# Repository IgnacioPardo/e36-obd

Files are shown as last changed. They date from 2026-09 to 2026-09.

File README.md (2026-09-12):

<div align="center">

# E36 OBD

**Read a pre-OBD2 BMW's brain — from a Mac, an iPhone, an Apple Watch, or a board you build yourself.**

A 1994 BMW E36 316i (M43B16, Bosch Motronic 1.7.2) predates OBD2. It speaks **KWP71** over a single-wire **K‑line**, woken with a 5‑baud slow init. A generic OBD2 scan tool can't talk to it at all — not "fewer PIDs", it will *never* establish a session. The usual answer is a Windows laptop running INPA. This isn't that: it's a Mac client, a native iOS/watchOS app, ESP32 firmware, and two open hardware builds — all offline, no Windows, no VM, no third‑party dependencies.







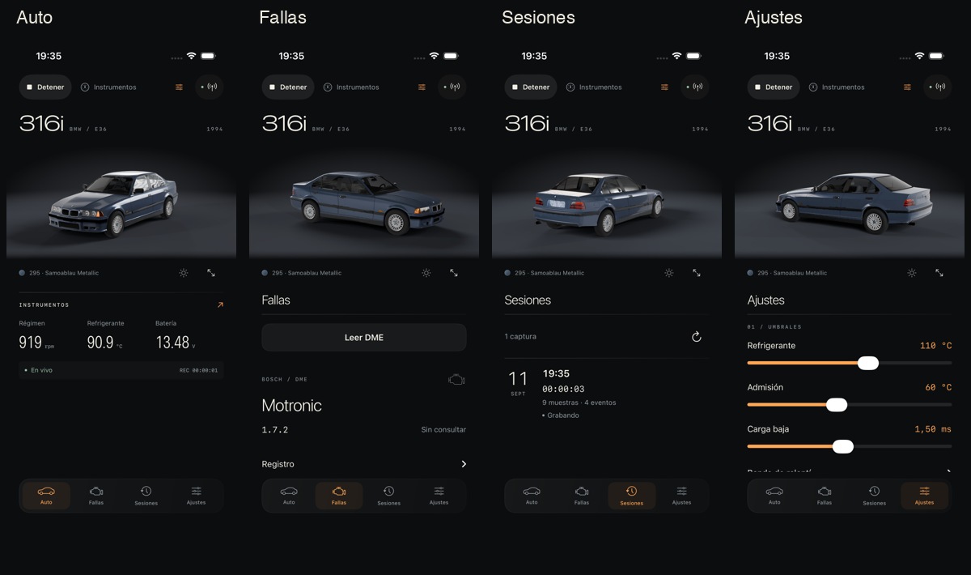
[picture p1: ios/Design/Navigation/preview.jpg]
E36 OBD — Auto, Fallas, Sesiones and Ajustes share a persistent 3D car scene


</div>

---

## Four ways to read the car

| | Component | What it is | Where |
|---|---|---|---|
| 🖥️ | **macOS client + web panel** | ~600 lines of Python (stdlib + `pyserial`) driving an FTDI K‑line cable through Apple's built‑in `AppleUSBFTDI` — the 5‑baud wakeup is bit‑banged with the UART's BREAK control. CLI **and** a local web dashboard. | [`e36obd/`](e36obd/) · [client reference](#-macos-client--web-dashboard) |
| 📱 | **iOS + Apple Watch app** | Native SwiftUI BLE dashboard: authentic E36 instruments, a real‑time 3D car, DME fault reading, session recording to SQLite, CSV export, widgets, CarPlay and Live Activities. No servers, no internet. | [`ios/`](ios/) · [details](#-ios--apple-watch-app) |
| 🔌 | **ESP32‑S3 firmware** | MicroPython K‑line ⇄ BLE bridge (Nordic UART) that the app talks to. Plus an Arduino reference sketch and a WiFi/PWA fallback. | [`firmware/`](firmware/) · [details](#-firmware-esp32-s3) |
| 🧩 | **Onboard board (rev B)** | A custom single PCB — ESP32‑S3 + L9637D + AP63203 buck + an OBD2 plug — that plugs straight into the car, in a printed case with a machined‑look **=BMW=** badge. | [`hardware/onboard/`](hardware/onboard/) · [details](#-hardware) |
| 🛠️ | **ELM backpack (rev E)** | A printed enclosure that turns a gutted ELM327 + an ESP32 DevKit into an inline reader — the salvage build the custom board replaces. | [`hardware/elm-backpack/`](hardware/elm-backpack/) · [details](#-hardware) |

---

## Why it's hard (and what was learned on the car)

K‑line‑only BMWs (E36, E38, E39, early E46) expect the diagnostic K‑line on **OBD2 pin 7**, wake on a **5‑baud** address, and run **KWP71**: framed blocks `[length][seq][title][payload…][0x03]` where *every byte but the last* is acknowledged by its bitwise inversion, in both directions. There is no error recovery — one bad byte ends the session.

This was **verified end‑to‑end on a 1994 E36 M43B16 automatic** (2026‑08‑09). The findings that cost the most to discover:

- **The L‑line jumper is mandatory.** A stock K+DCAN cable drives only OBD2 pin 7, but the 1.7‑era DME wants the 5‑baud wakeup on the **L‑line** (OBD2 pin 15). The fix is a solder bridge between **pins 7 and 15** — the instant it was in, address `0x10` answered `55 00 81`. (Watch pin 16: it's +12 V.)
- **Address is `0x10`** (BMW Motronic DME), not `0x12` (that's DS2, a different protocol).
- **Live values only populate with the engine running** — key‑on/engine‑off reads all zeros and looks exactly like a dead link.
- **Sampling is round‑trip bound** at ~1 Hz over 9600 baud, so a log's silence is not proof a sub‑second glitch didn't happen.
- **Reads degrade with the engine running** — ignition noise corrupts the byte handshake, so the live path collapses the core sensors into one contiguous 11‑byte read and rebuilds the session when it breaks.

> 📎 Full pre‑flight electrical checklist, the discovery method for un‑mapping sensors, and protocol notes are in [the client reference below](#-macos-client--web-dashboard) and [`docs/PROTOCOL_NOTES.md`](docs/PROTOCOL_NOTES.md).

---

## 📱 iOS + Apple Watch app

[`ios/E36OBD.xcodeproj`](ios/) — a native SwiftUI dashboard that reads the car over **BLE**, with no server and no internet. iOS 18+, watchOS 11+, **zero third‑party dependencies** (SQLite is the system `libsqlite3`; everything else is Apple's own frameworks).

<table>
<tr>
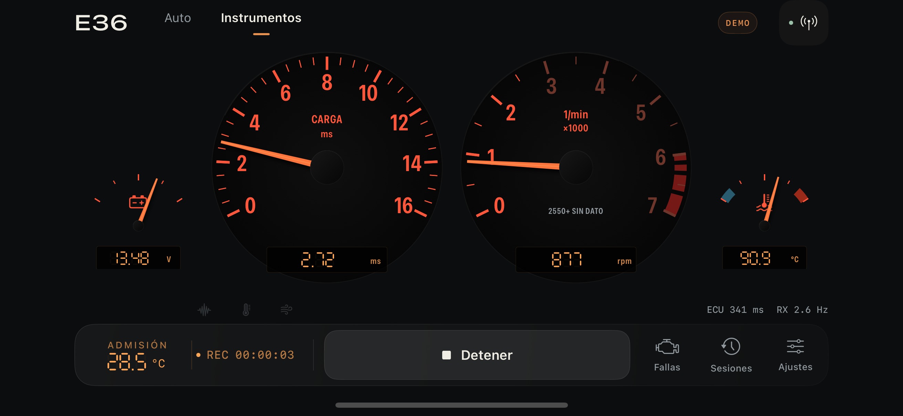
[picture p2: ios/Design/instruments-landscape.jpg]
E36 instrument cluster: load and tach dials, battery and coolant gauges, amber 7-segment readouts
<td width="60%"></td>
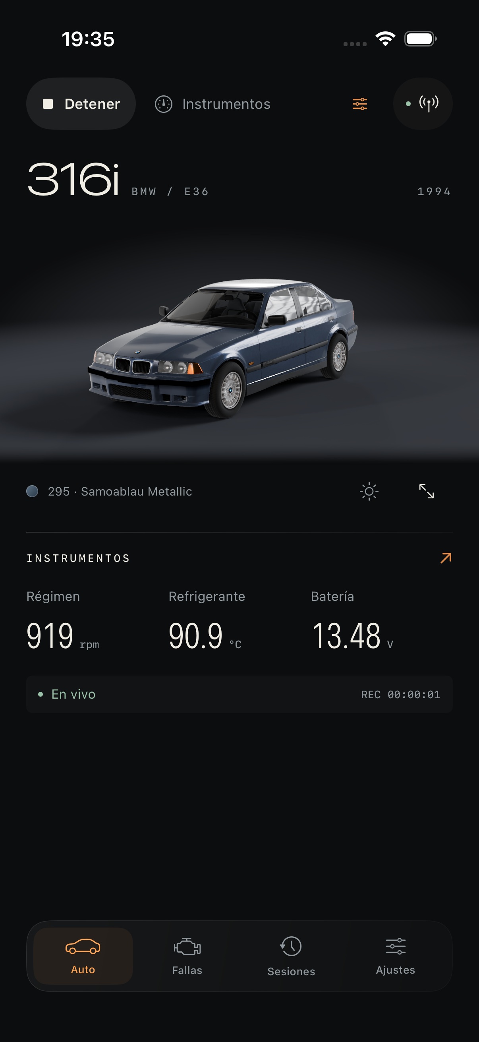
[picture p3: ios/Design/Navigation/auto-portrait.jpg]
Auto overview screen with the 3D E36 and live readings
<td width="40%"></td>
</tr>
<tr>
<td align="center"><em>Instruments — the E36 cluster, rebuilt</em></td>
<td align="center"><em>Auto — vehicle, reader state, latest readings</em></td>
</tr>
</table>

**What it does**

Latest development handoff: [session context, design decisions, validation and installation state](docs/sessions/2026-09-11-app-scene-companions.md).

- **Instruments** — the classic 90s BMW cluster in portrait and landscape: load (ms) and tach dials with the red zone, battery/coolant gauges, amber 7‑segment readouts, fan‑out auxiliaries. Needles ease to each reading without interpolating stored samples. Saturated 2550 rpm and empty‑RAM reads are called out as **DME sin datos** rather than shown as real values.
- **Auto** — a real‑time **3D render of the owner's 316i in 295 Samoablau Metallic**, drawn on‑device with RealityKit + Metal. Normal tabs keep the whole car in frame. Expand the scene for free navigation: one finger orbits horizontally and vertically, two fingers pan the camera, and pinch moves from detail close-ups to distant views without auto-fit pushing back. Zoom and pan can be combined; the chosen distance and position survive device rotation. The reset button or double-tap restores the front view, and closing the scene restores protected dashboard framing. Paint, glass and reflections are computed on the phone; the sun button selects studio or outdoor surroundings.
- **Navigation** — Auto, Fallas, Sesiones and Ajustes share one persistent scene, above their content in portrait and beside it in landscape. Each tab is the next quarter-turn around the car; moving back through the bar reverses that ordered orbit, including when tabs are skipped. The scene reaches the screen edge; text and controls retain readable insets. En vivo, Instrumentos and BLE stay at the top. Starting capture keeps the current tab; closing Instruments returns to it. Session selection and unsaved settings survive navigation.
- **Faults** — reads the DME fault memory; pauses and resumes the same recording session around the read.
- **Sessions** — every capture recorded to local SQLite (WAL, file‑protected), browsable with a shared cursor across all five channels and **CSV export** of sensors + events. Gaps are never bridged.
- **Alerts** — configurable thresholds (low load, coolant, intake) with hysteresis, sound and haptics; every episode is logged even when sound is rate‑limited.
- **Widgets · CarPlay · Watch · Live Activities** — *Instrumento E36*, *Garage E36* (with the car render) and *OBC E36* widgets for the Home Screen, StandBy and CarPlay. Garage and OBC also have a large Home Screen size with all five readings; a watchOS companion with five full‑screen gauges and complications; and a Live Activity on the Lock Screen and Dynamic Island. The ESP32 keeps a single BLE link to the phone; everything else is fed from it.

<table>
<tr>
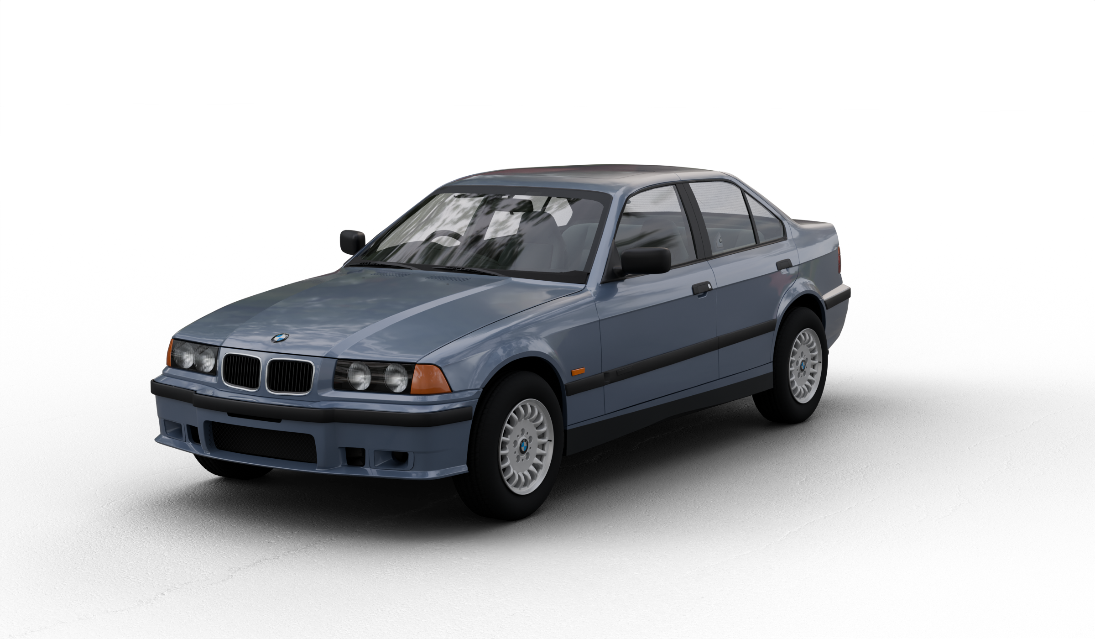
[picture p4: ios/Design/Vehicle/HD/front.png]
High-quality render of the Samoablau E36 316i, front three-quarter
<td></td>
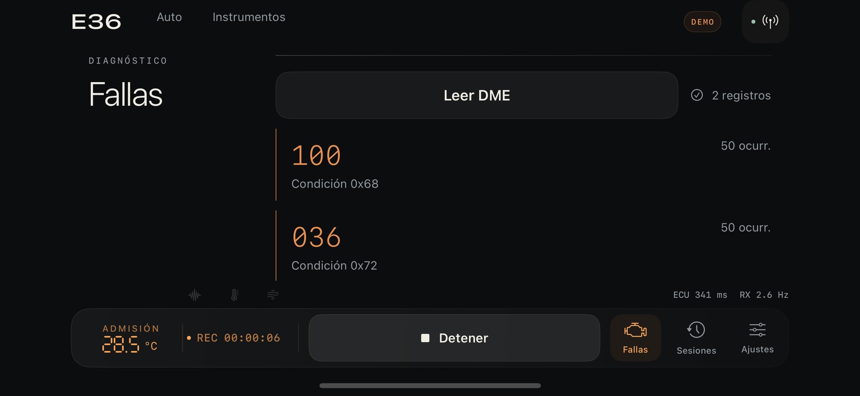
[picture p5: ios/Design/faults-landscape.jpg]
DME fault reading screen
<td></td>
</tr>
</table>

**Architecture.** The tested, platform‑independent core is a local Swift package, [`ios/Core`](ios/Core) (`E36Core`), so the hard parts run without a simulator:

| Module | Responsibility |
|---|---|
| `AcquisitionMachine` | pure state machine for BLE capture (sync → idle → live, faults, DME recovery) |
| `WireProtocol` | frames raw bytes into lines before UTF‑8; parses telemetry vs text |
| `SessionStore` | an `actor` owning the sole SQLite connection; records off the UI/BLE threads; CSV export |
| `AlertEngine` | threshold rules with hysteresis |
| `Models` · `GraphSeries` · `WidgetSnapshot` · `CompanionSnapshot` | sensor model, downsampling that keeps extrema/events, and the bounded snapshots shared to widgets and the watch |

```sh
open ios/E36OBD.xcodeproj          # E36OBD Demo runs on the simulator (scenario picker, no BLE radio)
swift test --package-path ios/Core # 19 core tests, no simulator needed
```

The Xcode project is generated, not hand‑edited — `python3 ios/tools/generate_project.py` regenerates it with the stdlib alone. Deeper docs: **[`ios/DESIGN.md`](ios/DESIGN.md)** (instrument design), **[`ios/VALIDATION.md`](ios/VALIDATION.md)** (QA log), **[`ios/WIDGETS.md`](ios/WIDGETS.md)**, **[`ios/WATCH_AND_LIVE_ACTIVITIES.md`](ios/WATCH_AND_LIVE_ACTIVITIES.md)**, and the 3D pipeline in **[`ios/Design/Vehicle/`](ios/Design/Vehicle/)**.

---

## 🔌 Firmware (ESP32‑S3)

The board runs **MicroPython** (`ESP32_GENERIC_S3‑SPIRAM_OCT`, v1.29.0). On boot, [`firmware/mp/main.py`](firmware/mp/main.py) does `import ble; ble.arrancar()`, starting the BLE loop on its own thread so attaching the REPL doesn't kill it.

| Module | Role |
|---|---|
| [`firmware/mp/kline.py`](firmware/mp/kline.py) | KWP71 transport: 5‑baud slow init, block send/recv with inverted acks, RAM reads, sensor + fault decode. Drives the **ST L9637D** on `TX=GPIO17`, `RX=GPIO18`. DME at **9600 baud** (`0x10`); the automatic gearbox EGS at **4800 baud** (`0x6C`). |
| [`firmware/mp/ble.py`](firmware/mp/ble.py) | The BLE "panel": Nordic UART service, command loop, live streaming, fault reads, session lifecycle and desktop‑grade recovery. |
| [`firmware/mp/web.py`](firmware/mp/web.py) | Optional WiFi SoftAP dashboard (`E36-OBD` / `192.168.4.1`), not started at boot. |
| [`firmware/kline_e36/kline_e36.ino`](firmware/kline_e36/) | An Arduino/C++ reference port of the same protocol — a bring‑up sketch that inits and reads faults once over USB serial. |

**BLE contract** — advertises the **name only** (`E36-OBD`); the app verifies Nordic UART after connecting.

```text
service 6E400001-B5A3-F393-E0A9-E50E24DCCA9E   RX 6E400002-… (write)   TX 6E400003-… (notify)
commands (1 ASCII char): v = live · f = faults · s = stop · ? = help
live line:  D <rpm> <load_ms> <coolant_C> <battery_V> <query_ms> [intake_C]
            D 930 0.70 63.1 13.48 341 23.7
```

Output is CRLF, chunked ≤20 bytes with 12 ms between notifications; intake temp is appended last so older clients stay compatible. **Update firmware over USB** with [`ios/tools/update_ble.py`](ios/tools/update_ble.py) (via `mpremote`) — it backs up every target file, verifies it's really the E36 reader, writes, reads back, and rolls back on any mismatch. It never reflashes MicroPython or touches `main.py`.

Host‑run tests in [`firmware/tests/`](firmware/tests/) exercise the real modules against a scripted fake UART / mocked radio — including a byte‑for‑byte match against the desktop client:

```sh
python3 -B -m unittest discover -s firmware/tests -v
```

---

## 🧩 Hardware

Two open builds, both parametric — a Python source file generates the board or the case, verified by script before export.

### Onboard board — rev B (`hardware/onboard/`)

One 90 × 50 mm two‑layer PCB for JLCPCB SMD assembly: **ESP32‑S3‑WROOM‑1 + L9637D + AP63203 buck + a PCB‑mount OBD2 plug**. 3.3 V straight from the car's 12 V, a hardware low‑battery cutoff (buck EN divider: on at 12.5 V, off at 11.5 V), and it plugs directly into the E36's 20‑pin round connector via a pigtail. `gen_board.py` is the source of truth — placement, nets, zones and the custom OBD2 footprint; `export.py` runs DRC and emits gerbers/BOM/CPL. **DRC: 0 errors.**

<table>
<tr>
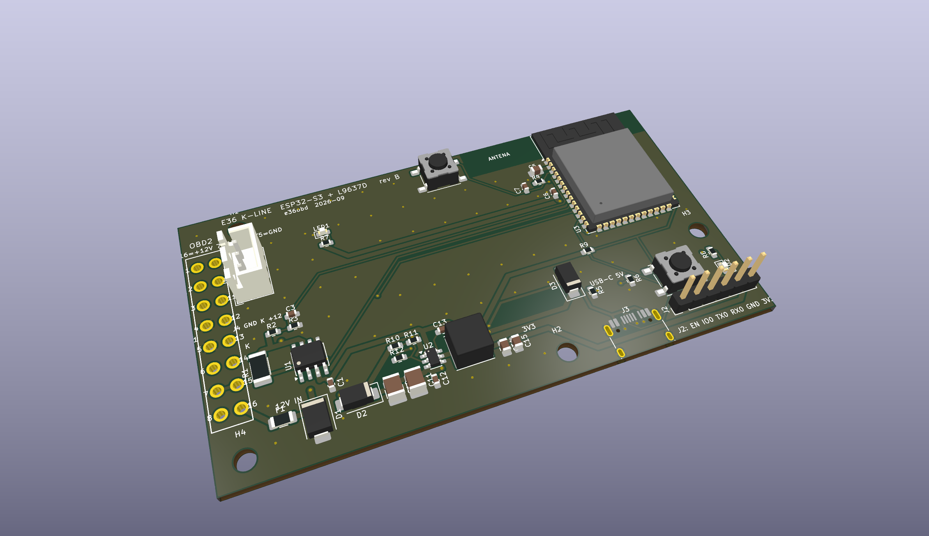
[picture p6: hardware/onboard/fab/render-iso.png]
Bare rev B PCB: ESP32-S3, L9637D, AP63203 buck, OBD2 footprint
<td></td>
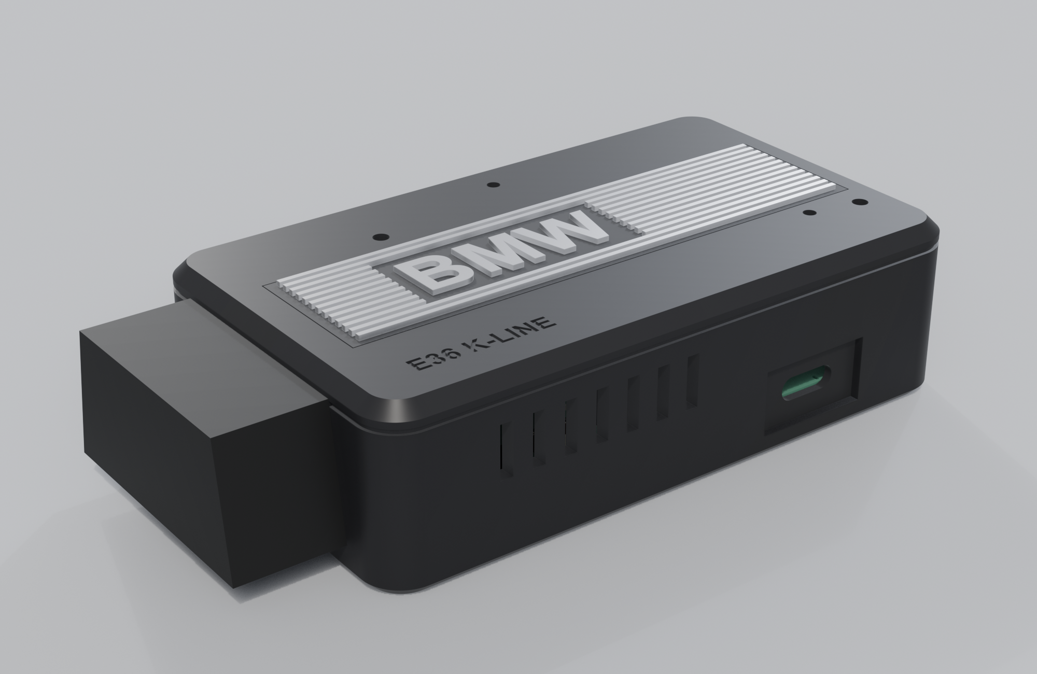
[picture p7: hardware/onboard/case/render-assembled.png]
Printed case with a silver M50-style BMW badge and E36 K-LINE embossing
<td></td>
</tr>
<tr>
<td align="center"><em>The board — ESP32‑S3 + L9637D + buck + OBD2</em></td>
<td align="center"><em>The case — =BMW= badge, light‑guide LED, USB‑C</em></td>
</tr>
</table>

`case.py` generates a three‑piece printed enclosure (96.8 × 56 × 27 mm): black base and lid with R6 corners, 45° chamfers and a shadow line at the seam, plus a separate **=BMW= badge** copied from the M50 valve cover — black field, 13 fine silver ribs running the length of the lid, the "BMW" plaque set toward the plug and cutting only the middle ribs (one filament change at 1.6 mm, or two colours via AMS). The OBD2 plug's neck is clamped in the end wall, the USB‑C shell passes through a shell‑shaped opening flush with a bezel, LEDs come out through Ø3 mm light pipes, RESET/BOOT are clip holes, and four M3 × 12 screws from below thread into brass heat‑set inserts — nothing visible on the outside. `CASE_PIGTAIL=1` builds the variant without the OBD2 plug for a direct 20‑pin pigtail. See [`hardware/onboard/README.md`](hardware/onboard/README.md) for the full BOM, the schematic, the pinout, the print list and the pre‑fab checklist. ([schematic](hardware/onboard/fab/schematic.png))

### ELM backpack — rev E (`hardware/elm-backpack/`)

The predecessor build: a 162 × 48 × 30.4 mm printed inline enclosure that houses a gutted ELM327 + a buck + an ESP32‑S3 DevKit end‑to‑end, with the same ribbed BMW lid. Fully parametric (`model.py` on build123d), with an offline interactive [CAD viewer](hardware/elm-backpack/viewer.html) and print‑ready 3MF/STL.

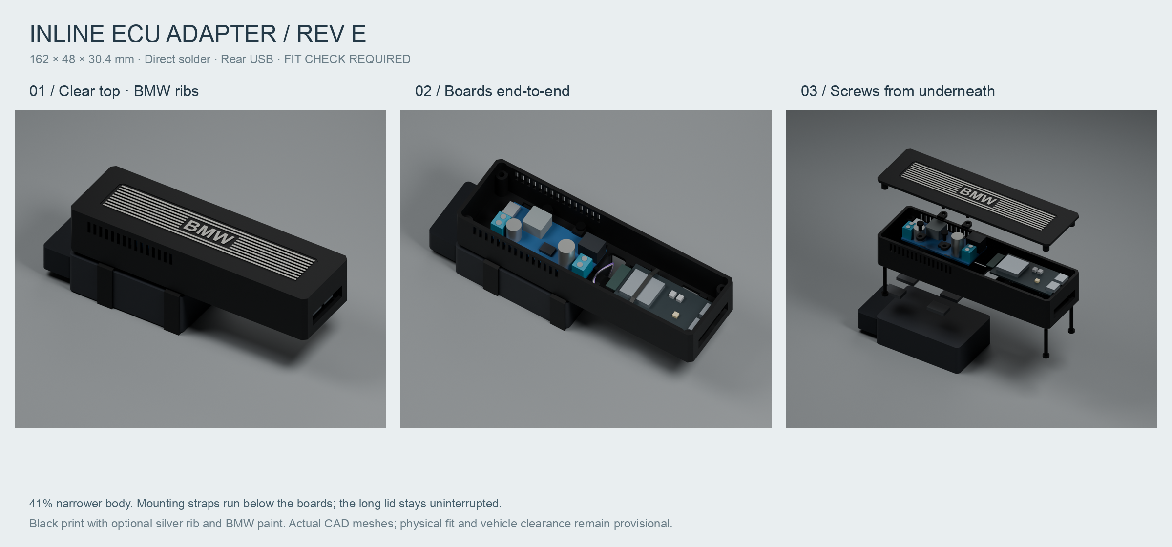
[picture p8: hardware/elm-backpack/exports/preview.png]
ELM-backpack inline enclosure: assembly, internal layout and exploded view


Details, the parts list and print settings: [`hardware/elm-backpack/README.md`](hardware/elm-backpack/README.md).

---

## 🖥️ macOS client & web dashboard

Pure Python — stdlib plus `pyserial`. It drives an FTDI **FT232R "INPA compatible K+DCAN"** cable through the OS's own `AppleUSBFTDI` (no vendor kext), bit‑banging the 5‑baud init with the UART's BREAK control. From the repo root:

```bash
python3 -m venv .venv && ./.venv/bin/pip install pyserial   # first time
./.venv/bin/python -m e36obd doctor                         # desk test, no car
```

**Command line** — run in order; each only makes sense once the previous worked:

| Command | What it does |
|---|---|
| `doctor` | Lists serial ports, flags the FTDI one, toggles BREAK, listens 2 s. Silence with no car is fine. |
| `scan` | Tries candidate addresses (`0x10` first) and reports which return a `0x55` sync + keywords. |
| `id` | Prints the ECU identification strings — the real proof of a working link. |
| `codes` | Reads stored fault codes (raw hex; a *speculative* 5‑byte grouping is not a verified decode). |
| `log` | Live values to CSV — `--adc`, `--ram ADDR:LEN`, `--param`, `--interval`, `--duration`, `--out`. |
| `raw` | Sends an arbitrary block title with optional payload — for hunting non‑standard commands. |
| `clear` | Erases fault memory (prompts). **Destroys evidence — read and save codes first.** |

Global flags go **before** the subcommand: `--port`, `--baud` (9600), `--address` (`0x10`), `--loopback auto|on|off`, `-v`. Example: `./.venv/bin/python -m e36obd --address 0x10 -v id`.

**Web dashboard** — `dash` serves a local panel (stdlib + `pyserial`, no framework/CDN, works offline). One thread owns the serial port and drains an action queue between samples, so recording, re‑reading faults, dumping RAM and probing the gearbox coexist with live polling without fighting over the line.

```bash
./.venv/bin/python -m e36obd dash            # http://127.0.0.1:8036
./.venv/bin/python -m e36obd dash --lan      # reachable from the phone, token-guarded
./.venv/bin/python -m e36obd dash --demo     # synthetic data, no car
```

Four hash‑addressable tabs — **Tablero** (analog instruments + 4‑min trend), **Diagnóstico** (decoded faults, DS2 gearbox probe, before/after snapshots), **Capturas** (recorded sessions with a shared cursor and two‑session overlay), **Scanner** (RAM explorer with cumulative change detection). Write and actuator blocks (`0x02` WriteRAM, `0x1A` WriteEEPROM, `0x04` ActivateActuator) are blocked **in the server**, verified against a simulated ECU. There's also a Web Bluetooth **PWA** in [`docs/ble/`](docs/ble/).

<details>
<summary><strong>Pre‑flight electrical checklist</strong> — read this before the cable ever touches the car</summary>

Almost every "it doesn't work" report is one of these three, and all three fail *silently* — the port opens, the command runs, and nothing answers.

1. **OBD2 pins 7–8 must be bridged.** K‑line‑only BMWs expect the K‑line on pin 7; many cables/adapters present it on pin 8. Set the cable's K‑line switch, or solder 7↔8 on its PCB. Verify with a multimeter in continuity: probe pin 7 and pin 8 on the cable's own 16‑pin connector — it should beep.
2. **The 20‑pin adapter must be fully pinned.** The cable is bus‑powered from OBD2 pin 16 (+12 V from the car). Cheap adapters wired K‑line‑and‑ground only leave the FTDI chip unpowered. Confirm it passes at minimum K‑line, +12 V and ground.
3. **Multimeter checks — verify, don't trust.** Confirm the 20‑pin round pinout against a BMW source (TIS / service manual) before probing; several conflicting diagrams circulate. Do continuity with the harness **disconnected from the car**; do voltage at the car's connector with nothing else plugged in.

| Check | Meter mode | Expected |
|---|---|---|
| Battery at the round connector's +12 V pin | DC volts, black on chassis ground | ~12.4 V off, ~13.8–14.4 V running |
| Round K‑line pin → OBD2 pin 7 | Continuity, unplugged from car | Beeps / ~0 Ω |
| Round +12 V pin → OBD2 pin 16 | Continuity, unplugged | Beeps / ~0 Ω |
| Round ground pin → OBD2 pins 4 and 5 | Continuity, unplugged | Beeps on both |
| OBD2 pin 7 → pin 8 on the cable itself | Continuity | Beeps (see §1) |

4. **Ignition position 2.** The DME is only awake with the ignition in position 2 (dash lights on, engine not running). Position 1 is not enough; nothing answers with the key out.

</details>

<details>
<summary><strong>Discovering what the values mean</strong> — ADC channels and the RAM map are un‑mapped</summary>

`log` is a **discovery tool**, not a dashboard: there's no table saying which channel is coolant or where the TPS lives, and raw ADC bytes are not degrees. The method is empirical — change **one** thing with a known physical effect, then find the column that moved the same way.

- **Coolant temp** — log a full sweep through a cold‑start warm‑up; it's the channel that moves *monotonically* over ~10 min then flattens (NTC sensors often fall as temp rises).
- **Throttle** — engine off, ignition on; sweep the pedal. TPS tracks the pedal, returns to rest, and hits a ceiling at wide‑open.
- **Battery** — calibrate absolutely against the multimeter; two points give a linear scale and often hint at the shared ADC reference.
- **Intake air** — responds within seconds to a heat gun, unlike coolant's minutes of lag.

Prefer monotonic or repeatable‑cycle stimuli, load the CSV into anything that plots, then re‑log the interesting channels at a shorter interval. **Nothing here persists a mapping for you — write down what you confirm.**

</details>

<details>
<summary><strong>Troubleshooting</strong></summary>

| Symptom | Likely cause | What to do |
|---|---|---|
| `No serial port found` | Cable not enumerated, or macOS hasn't claimed it | `ls /dev/cu.*`; try another USB port/cable; `system_profiler SPUSBDataType`; pass `--port`. |
| `doctor` opens the port but BREAK fails | `/dev/tty.*` selected instead of `/dev/cu.*`, or a vendor FTDI kext interfering | Always use `/dev/cu.*`; uninstall any vendor FTDI driver and reboot. |
| `scan` finds no responding address | Almost always electrical | Work the pre‑flight list in order before widening the address set. |
| Init OK but blocks fail their ack — `bad ack for byte N` | Timing / line quality, or non‑standard framing | Re‑run with `-v`; try a shorter adapter; if always byte 0, force `--loopback on|off`. |
| Session establishes then dies mid‑`log` | KWP71 drops the link if blocks stop; also a loose‑connection signature | Lower `--interval`, fewer channels; then check the physical connection. |
| Disconnects worse with the engine running | Ignition noise on a single‑wire bus, or a sagging supply | Route away from plug leads/coil; verify pin‑16 voltage running; clean ground. |
| `NOT_SUPPORTED` | BMW used a different block title | Probe with `raw --title 0xNN`. |

</details>

<details>
<summary><strong>Known vs unknown</strong> — how much to trust the output</summary>

**Solid:** KWP71 framing and acks (from [colinbourassa/libiceblock](https://github.com/colinbourassa/libiceblock)); the macOS BREAK‑banged 5‑baud init (absolute bit deadlines, the port never leaves 9600); loopback auto‑detection.

**Not confirmed:** exact block titles may be non‑standard per manufacturer; the fault‑code record layout and code→description mapping are **not** decoded (a code number without a table tells you a fault exists, not what it is); ADC channel meanings, the RAM map and scaling are unknown and must be derived. `raw` and `log` exist precisely to explore this.

</details>

---

## Repository layout

```
e36obd/         macOS client + web dashboard (Python: stdlib + pyserial)
firmware/       ESP32-S3 firmware — mp/ (MicroPython, shipping) + kline_e36/ (Arduino ref) + tests/
ios/            SwiftUI iOS + watchOS app — E36OBD.xcodeproj, Core/ (E36Core package), Design/Vehicle/ (3D)
hardware/       onboard/ (rev B custom PCB + case) · elm-backpack/ (rev E enclosure) · wiring diagrams
docs/           PROTOCOL_NOTES.md, EGS_NOTES.md, GAUGE_DESIGN.md, cableado.html, ble/ (Web Bluetooth PWA)
sessions/       archived AI-assisted development transcripts (Git LFS)
```

Large binary assets (`.usdz`, `.blend`, `.glb`, `.exr`, `.step/.stl/.3mf`, `.pdf`, session logs) are tracked with **Git LFS** — install [git‑lfs](https://git-lfs.com) and `git lfs pull` to fetch them.

## Safety

- **Do not probe pins at random with the ignition on.** Shorting a DME input to +12 V or ground can destroy it, and not every line is fuse‑protected. An M1.7.2 is expensive and increasingly rare.
- Do continuity testing with the harness **disconnected from the car**; do voltage testing one pin at a time against a known‑good ground.
- **Verify the round‑connector pinout against a BMW source before touching a probe to it.** Assume any diagram — including in this repo — is wrong until you've checked it. Beware pin 16 (+12 V) next to the K‑line.
- **`clear` and fault‑memory erase destroy evidence.** Read and save codes first; the web panel always snapshots before erasing.
- `raw` sends arbitrary block titles to a live engine controller. `WRITE_RAM`, `WRITE_EEPROM` and `ACTIVATE_ACTUATOR` are not read‑only. Know what a title does before sending it.
- Do first‑contact work engine‑off. Once logging with the engine running, keep the cable clear of the belts, fan and exhaust manifold.

---

<div align="center">
<sub>Personal project for a specific 1994 E36 316i (M43B16). No affiliation with BMW; "BMW" marks belong to their owner and the badge/branding here are for a personal build. No formal license — ask before reuse.</sub>
</div>

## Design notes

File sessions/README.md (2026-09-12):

# AI development sessions

Archived transcripts of the AI-assisted development of this project.
Snapshots taken 2026-09-08 (and 2026-09-12 for `c5212502`); conversations may have continued afterward.

## claude/  — Claude Code sessions (JSONL)
| file | source worktree | notes |
|---|---|---|
| `36c9b727-….jsonl` | `~/Desktop/E36_OBD` | main K-line / BLE thread |
| `520df9c4-….jsonl` | `~/Desktop/E36_OBD` | earlier session |
| `17cce4e9-….jsonl` | `conductor/workspaces/E36_OBD/nassau` | this worktree |
| `c5212502-….jsonl` | `conductor/workspaces/E36_OBD/nassau` | 2026-09-10 → 09-12: single-board PCB rev B (ESP32-S3 + L9637D + AP63203 + OBD2), printed case with M50 badge, JLCPCB/PCBWay pricing. Snapshot 2026-09-12; the session continued briefly after it. |

A third Desktop session (`9db594c5-…`, ~124 KB, 2026-08-09) existed at first
scan but was pruned from `~/.claude` before it could be archived.

### Raw material of session `c5212502` (2026-09-12)
| file | what |
|---|---|
| `claude/c5212502-tasks-2026-09-12.zip` | outputs of the background tasks and the Explore sub-agent spawned by that session (Freerouting logs, renders, DRC runs, the session-mining agent report) |
| `claude/c5212502-subagents/`, `claude/17cce4e9-subagents/` | full JSONL transcripts of the sub-agents each session spawned |
| `claude/memory-2026-09-12/` | snapshot of Claude's project memory notes (`MEMORY.md` index + one file per topic) as they stood at the end of the session |

`17cce4e9-….jsonl` was also refreshed to its 2026-09-11 state (it had grown since the first snapshot).

## codex/  — Codex CLI rollouts (JSONL)
Five rollouts whose `cwd` was the `nassau` worktree (2026-09-07).
The two large files are full sessions with inline tool output.

### E36 app conversation, September 11 checkpoint

[`codex/01a07e40-ac26-7072-b6db-2e6874e66e4d-visible-2026-09-11.jsonl`](codex/01a07e40-ac26-7072-b6db-2e6874e66e4d-visible-2026-09-11.jsonl) preserves the user messages and visible assistant replies from the ongoing iPhone/BLE/3D/Watch/widget conversation through the commit-preparation checkpoint. Export metadata records its timestamp, message count and credential redactions. It excludes internal runner instructions, private reasoning and tool payloads; attachment paths refer to the original workspace. Earlier raw snapshots remain historical archives.

For continuation, start with the [current session handoff](../docs/sessions/2026-09-11-app-scene-companions.md), which records the latest accepted design, camera controls, widget fix, tests, device installation and remaining hardware checks.

### E36 raw-format conversation and tool records

The [compressed raw-format archive](codex/01a07e40-ac26-7072-b6db-2e6874e66e4d-raw-records-2026-09-11.jsonl.gz) adds the original tool-call inputs, tool responses and embedded screenshots requested after the visible-message export. It preserves the JSONL record envelopes, timestamps, call IDs and public payload fields. It contains **6,743 message/tool records and 751 embedded images**, about **470 MiB compressed**. One tool call was still pending at the snapshot cutoff.

This is not a byte-identical copy of the internal runner log: private reasoning, system/developer instructions, internal metadata and duplicate runtime events are excluded. Outputs from reads of internal session/instruction files are marked as excluded; known credentials are redacted. The [manifest](codex/01a07e40-ac26-7072-b6db-2e6874e66e4d-raw-records-2026-09-11.manifest.json) records the exact cutoff, SHA-256, counts and exclusions. The archive was reopened to verify gzip integrity, every JSON record, call/output pairing and base64 image payloads.

The local worktree may contain only an LFS pointer to conserve disk space. Materialize the archive before opening it (allow at least 470 MiB of free space):

```sh
git lfs pull --include="sessions/codex/01a07e40-ac26-7072-b6db-2e6874e66e4d-raw-records-2026-09-11.jsonl.gz"
gzip -dc sessions/codex/01a07e40-ac26-7072-b6db-2e6874e66e4d-raw-records-2026-09-11.jsonl.gz | less
```

The standard-library [exporter](export_codex_records.py) accepts a local Codex rollout path and a destination `.jsonl.gz`. It builds in a temporary directory before publishing the file to avoid caching incomplete LFS objects while the archive grows. Source rollouts are read without modification. These archives use Git LFS.

> These are raw transcripts and may contain paths or tokens surfaced by tool
> output. Kept in a private repo. Scrub before making this repository public.

## Readable enclosure session and handoff

The approved long ESP32/buck/ELM enclosure chat now has a [visible-conversation snapshot](../docs/sessions/2026-09-11-elm-backpack-transcript.md) and [continuation handoff](../docs/sessions/2026-09-11-elm-backpack.md), captured for the 2026-09-11 commit/push request. The [eight original reference images](../hardware/elm-backpack/references/README.md) are tracked alongside the enclosure. These readable records omit execution instructions, private reasoning and tool traffic.

### Enclosure raw-format records, September 11 checkpoint

The [compressed JSONL archive](codex/01a07e53-ae96-7b91-8f25-bf9802ad1c1f-raw-records-2026-09-11.jsonl.gz) retains the original record fields and timestamps for 64 public messages, 419 tool call/result records, and 45 embedded images. Its [manifest](codex/01a07e53-ae96-7b91-8f25-bf9802ad1c1f-raw-records-2026-09-11.manifest.json) records the exact snapshot cutoff, counts, exclusions, redactions and SHA-256 checksum. The checkpoint includes the request for raw transcripts; conversation after that cutoff is not included.

This is a filtered raw-format export, not a byte-identical runner backup: system/developer instructions, private reasoning, runtime state and duplicate events are excluded; outputs that read internal instruction/session files are redacted. Tool activity and images are retained, unlike the readable transcript. The archive uses Git LFS. After fetching LFS objects, decode it with:

```sh
gzip -dc sessions/codex/01a07e53-ae96-7b91-8f25-bf9802ad1c1f-raw-records-2026-09-11.jsonl.gz > enclosure-transcript.jsonl
```

The [export script](export_codex_records.py) accepts a local source JSONL path and destination `.jsonl.gz` path and writes a companion manifest.

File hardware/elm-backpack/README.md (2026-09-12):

# BMW inline ECU adapter — revision E

**162 × 48 × 30.4 mm**, with the buck and ESP32-S3 arranged end-to-end. The body is **41% narrower and 52 mm longer** than revision D. The long BMW ribbed lid has no straps or visible screws across its face. Black printed parts, black hardware; silver paint on the BMW lettering and ribs is optional.

The ESP headers are removed for direct soldering. **Both ESP USB sockets face the tail, away from the OBD plug.** The converter remains above the original ELM housing; the ESP occupies the extended tail. Two straps pass through recessed floor slots under the buck and wrap beneath the ELM. A separate rear tie position supports the extended tail against an existing suitable mounting point.

**First-fit prototype:** the board dimensions, ELM housing and installed vehicle clearance remain provisional. Print the gauge and measure the actual parts before the full enclosure. [PLAN.md](PLAN.md) records the measurement sources and decisions.

Current inline enclosure, internal layout and exploded assembly

[Compare the previous wide case with this revision](exports/comparison.png).

## Files

| File | Purpose |
|---|---|
| [Exploded views](exports/exploded-views/all-views.png) / [full-resolution ZIP](elm-backpack-exploded-views.zip) | Four angles: labelled assembly, OBD end, underside fasteners and board mounts |
| [viewer.html](viewer.html) | Offline interactive CAD viewer: orbit, open lid, explode, switch silver paint on/off |
| [print-layout.3mf](exports/print-layout.3mf) | Geometry only: **1 base + 1 lid + 4 buck keepers**, flat on the bed |
| [fit-gauge.stl](exports/fit-gauge.stl) | First print to check both board outlines and screw holes |
| [base.stl](exports/base.stl), [lid.stl](exports/lid.stl), [buck-keeper.stl](exports/buck-keeper.stl) | Millimetre meshes in print orientation; print four keepers |
| [base.step](exports/base.step), [lid.step](exports/lid.step), [buck-keeper.step](exports/buck-keeper.step) | Individual editable solids, in print orientation |
| [assembly-with-references.step](exports/assembly-with-references.step) | Assembled CAD, including named electronics, ELM, pads, straps and optional paint references. Do not print these references. |
| [dimensions.svg](exports/dimensions.svg) | Inline layout and longitudinal section |
| [black.png](exports/black.png) | Same printable geometry without silver paint |
| [parameters.json](parameters.json), [model.py](model.py) | Editable dimensions and CAD generator |

## Parts and hardware

| Quantity | Item | Use |
|---|---|---|
| 4 | Black M3 × 25 screws, head diameter ≤5.6 mm, head height ≤2 mm | Insert from **underneath** through the base into the lid's blind 2.6 mm pilots; nominal thread engagement 4.5 mm |
| 4 | M3 × 6 screws, head diameter ≤5.6 mm | Buck keepers |
| 2 | 10 mm-wide reusable straps, about 1 mm thick and 250 mm long | Through floor slots beneath buck, around ELM; trim after checking closure overlap |
| 1 | Suitable nylon tie or 10 mm strap | Rear floor slots to a suitable existing support; choose length after checking installed route |
| 1 each | Nylon ties approximately 2.5 × 150 and 2.5 × 100 mm | ESP retention and internal harness strain relief |
| 4 | Insulating silicone pads, 10 × 16 × 3 mm | Case-to-ELM spacing |
| 4 + 4 | 0.5 mm silicone pads, about 1 × 5 mm | Buck support edges and keeper toes; upper pads compress into a 0.3 mm gap |
| 2 | 0.5 mm silicone pads, 14 × 6 mm | Central ESP underside supports |
| As needed | Insulating sleeve for ties and protection for the drilled ELM hole | Protect wires and board contact areas |

The lid screws travel through 3.4 mm base holes and engage the lid from z=20.5 to 25 mm. Their heads sit below the floor, within the 3 mm mounting-pad gap. Use the specified low heads; taller heads need more spacing. This closure requires detaching the case from the ELM for lid service.

The keeper toes only overlap the PCB's outer 1 mm. Check all four support patches on the real converter; reposition `buck_clamp_fraction` if a lead or component occupies one. The ESP's central supports stay between its two solder rows.

## Print and check

1. Print **fit-gauge.stl** at 100% in millimetres. With the connecting bar and raised hole bosses at the far end, the left pocket is the buck and the right is the ESP. Pockets add 0.3 mm clearance per side. Left screw sample: 2.6 mm pilot; right: 3.4 mm clearance. Test an M3 screw gently by hand and adjust hole diameters for your printer if necessary.
2. Check the **63.5 × 27.5 mm buck PCB** and **65 × 28 mm overall ESP envelope** against the pockets. Measure the buck's maximum component height above its PCB, solder protrusions, the ESP carrier-PCB ends and antenna overhang, USB position, and clear support patches. The gauge does not establish height or connector fit.
3. Measure available space for the **162 mm case plus USB cable** in the actual vehicle position. The reference ELM body ends 84 mm before the case tail. Locate a suitable support for that extension rather than leaving the OBD connection to carry the full cantilever. The case can be repositioned slightly on the ELM; check both strap locations remain over its body and clear of the plug.
4. Starting print settings: 0.4 mm nozzle, 0.20 mm layers, 4 walls, 5 top/bottom layers, 30% gyroid. Base: floor down. Lid: detailed outer face down, locating rim and blind screw bosses upward. Keepers: flat. Use a smooth plate for the lid detail. The recessed field closes with short bridges between the ribs/letters; inspect them in the slicer. Side vents span 2 mm, and the harness anchor spans 3 mm. The recessed **floor** strap channels are open from above and need no bridge across their 12 mm length. Add removable local support under the 32 mm rear USB-window roof.
5. Import the 3MF as geometry and select your own printer/material profile. Base: **48 × 162 × 28 mm**. Inverted lid: **48 × 162 × 9.9 mm**, including its inward screw bosses. Those bosses nest inside the base, so assembled case height is **30.4 mm**. The arranged bed allowance is approximately **110 × 182 mm**, before brim/exclusion zones. No G-code or printer profile is included.
6. Prefer unfilled ASA for the intended car enclosure, following the material manufacturer's profile and enclosed-printing requirements; see [Prusa's ASA guide](https://help.prusa3d.com/article/asa_1809). PETG can serve for a cool bench fit check. Confirm actual operating temperature with the enclosure closed; the vents establish neither weather sealing nor a continuous converter-output rating.

## Assembly, unpowered

1. Test the empty lid and all eight screw positions. Its rim has 0.35 mm clearance per side. The four lid bosses enter relieved base corners with 0.35 mm radial clearance and a 0.3 mm axial gap to the base posts. Do not force or bottom out screws.
2. **Thread the two 10 mm mounting straps before fitting the buck.** Their crossbars sit in the 1 mm-deep floor recesses at y=-55 and -9.3 mm. The straps should sit flush with the normal inner floor, leaving 1 mm below the assumed buck solder envelope. Keep closures below the ELM, clear of its OBD plug. Prepare a separate tie in the rear slots at y=54 if needed for installation support.
3. Protect the existing ELM hole, label the wires, remove the ESP headers/jumper housings and feed the harness through the **16 × 12 mm floor entry** between the boards. Solder directly to pads or very short pin stubs, insulate each joint, and follow the existing [wiring diagram](../../docs/cableado.html).
4. Apply the small buck support pads. Place the converter component side up, with **input terminal/DC-jack end toward the gap between the boards**. Fit the four padded keepers with M3 × 6 screws; tighten only enough to retain the board. Check support and toe contact on the actual PCB edges.
5. Fit the two ESP pads and the ESP component side up, USB facing the tail window. Route insulated wires parallel to its underside. The nominal 1.5 mm solder envelope leaves 3.5 mm for wires. Guide the sleeved 2.5 mm retaining tie through the two small floor slots and over the metal RF shield; keep the antenna, buttons and nearby components free. Snug without bending the PCB.
6. Tie the insulated harness to the small bridge anchor between the boards. Keep slack back to the ELM hole. Reserve the converter's end spaces for terminal-wire bends, and keep wires clear of the lid rim and screw bosses. Rendered wires show routing intent only.
7. Seat the lid and insert its four M3 × 25 screws **from below**. Apply the four 3 mm mounting pads between the ELM's plain back and the case, at x=±10, y=-72/-31 in the reference layout. Keep straps, screw heads, the small ESP tie and hole clear of the pads.
8. Position the case so the floor entry lies just beyond the ELM tail hole. Wrap the two already-threaded straps beneath the ELM and fasten them. Support the extended ESP end through its rear slots using a suitable existing mounting point; check the complete adapter can be unplugged and serviced.
9. Confirm both real USB cable overmolds enter the rear window and mate fully. Check wiring, then run the intended load with the lid closed and verify temperature and Wi-Fi/BLE reception in its actual installation position.

## What was verified

- Each printed CAD part is a single valid solid. All STL meshes are closed, consistently wound, have one connected component and positive volume, and begin at z=0.
- No detected interference between printed parts, the provisional board/component/solder/USB-plug envelopes, mounting straps and ESP retaining tie. Buck-to-ESP envelopes and straps-to-ELM references are checked separately. [CAD results](exports/cad-validation.json).
- The 3MF was reopened and checked for millimetres, three mesh definitions and six placed parts. It has not been sliced for a specific printer. [Mesh results](exports/mesh-validation.json).
- Actual exported mesh renders and the interactive viewer are inspected. Board measurements, detailed cable bends, pad contact, the drilled hole, thermal/RF performance and available vehicle space require physical checks.

Nominal clearances: **2 mm over the buck**, **14 mm over the ESP**, **3.5 mm below ESP solder joints**, **1 mm below buck solder**, **0.35 mm per side of the lid rim**. These are design allowances, not measurements of the user's hardware.

## Cover and finish

The 136 × 25 mm field runs along the case. Nine parallel ribs surround the BMW lettering. The field is recessed 0.4 mm into the 2.4 mm lid, leaving 2 mm skin outside through-vents. Forty-eight segmented openings between ribs provide about 716 mm² of open area; 15 side vents per wall above the buck add 480 mm². Segmented lid slots retain solid bridges along the long ribs. These areas are geometric, not a thermal rating.

Print all six parts in black. For the illustrated silver detail, highlight only the rib tops and BMW letter faces with compatible silver paint. Keep the field dark and the vents open. There is no extra caption, coloured badge or second filament. Fine plastic grain in the renders is illustrative; paint surfaces and texture are excluded from the print meshes. The optional paint is separately named in the STEP and toggleable in the viewer.

## Regenerate

From the repository root:

```sh
PYTHONDONTWRITEBYTECODE=1 ./.cadenv/bin/python hardware/elm-backpack/model.py
python3 hardware/elm-backpack/package.py
/Applications/Blender.app/Contents/MacOS/Blender -b --factory-startup -t 6 --python hardware/elm-backpack/render.py
PYTHONDONTWRITEBYTECODE=1 ./.cadenv/bin/python hardware/elm-backpack/build_visuals.py
```

CAD uses build123d 0.11.1 on Python 3.12; the packager uses Python's standard library; contact sheets use Pillow. The viewer embeds all meshes and works offline. Dimensions are editable in `parameters.json`; regenerate and resolve any reported clash before printing. Arial Bold outlines are baked into the exported geometry; regeneration uses the macOS font where available.

`auto_height` uses the taller board envelope plus 2 mm. The current 18 mm buck allowance is measured **above the PCB top**. A verified 14 mm component height would reduce overall height to 26.4 mm. Do not reduce it from an estimate.

Previous profiles are preserved in `profiles/rev-d.json`, `rev-c.json`, `rev-b.json` and `headers.json`; previous ZIP deliveries remain separate. Current exports and viewer are **revision E**. Older profiles may be regenerated to a separate output directory with `model.py --parameters ... --out ...`; the current dimension-sheet template describes the inline layout.

## Additional exploded views

The [four-view set](exports/exploded-views/all-views.png) uses the actual revision E meshes. Boards remain complete assemblies. Straps and illustrative wiring are hidden for clarity; the underside view also hides electronics and the ELM, and offsets the lid sideways. The board-mount view moves complete boards outward to expose the base seats and floor slots. These are display offsets only; printable geometry is unchanged. Individual plates are 2400 × 2320 PNGs, with transparent 2400 × 2000 source renders in the [view bundle](elm-backpack-exploded-views.zip).

Regenerate after the main CAD export:

```sh
/Applications/Blender.app/Contents/MacOS/Blender -b --factory-startup -t 6 --python hardware/elm-backpack/render_exploded.py
PYTHONDONTWRITEBYTECODE=1 ./.cadenv/bin/python hardware/elm-backpack/build_exploded_gallery.py
```

## Session history

The approved design decisions, remaining physical checks and reproduction commands are preserved in the [session handoff](../../docs/sessions/2026-09-11-elm-backpack.md). The [readable conversation](../../docs/sessions/2026-09-11-elm-backpack-transcript.md) and [original eight reference photos](references/README.md) are included in the repository.

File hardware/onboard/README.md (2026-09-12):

# E36 K-line — una sola placa (rev B)

ESP32-S3-WROOM-1 + L9637D + buck AP63203 + ficha OBD2 macho, todo en una PCB de **90 × 50 mm**,
dos capas, para mandar a JLCPCB con ensamblado SMD. Reemplaza al conjunto "ELM327 destripado +
DevKitC-1 + módulo buck" y a la placa `../kline-frontend.kicad_pcb` (que dejaba el MCU afuera).

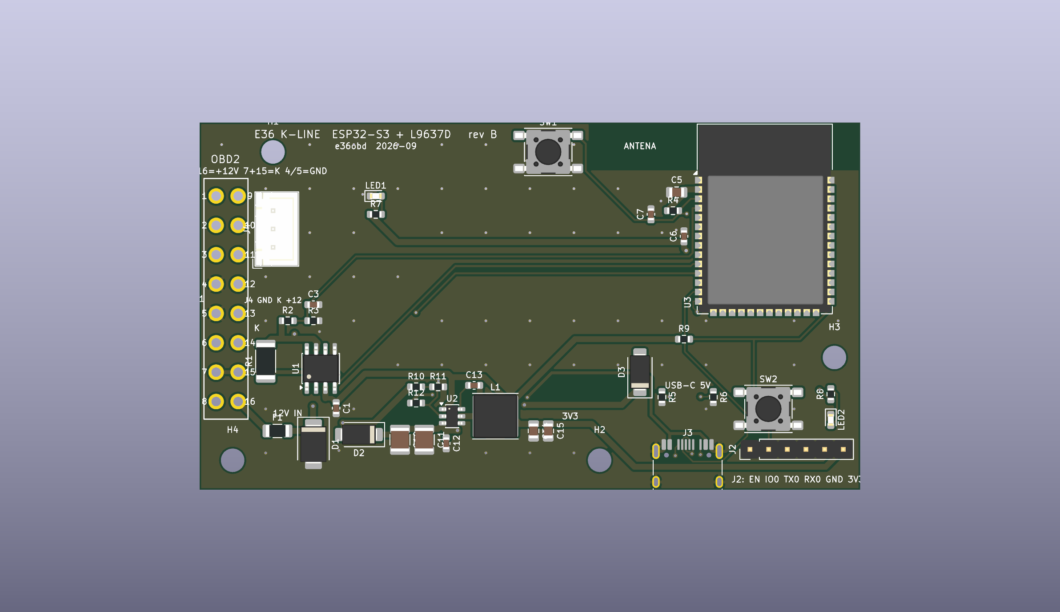
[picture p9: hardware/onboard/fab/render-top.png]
Vista superior


| Archivo | Qué es |
|---|---|
| `gen_board.py` | **La fuente.** Colocación, redes, clases de pista, footprint OBD2, zonas, serigrafía. Genera la placa. |
| `e36-kline-onboard.kicad_pcb` / `.kicad_pro` | Placa generada y ruteada (abrir en KiCad 10). |
| `e36obd.pretty/OBD2_Male_RightAngle_16P.kicad_mod` + `fp-lib-table` | Footprint propio de la ficha OBD2. |
| `gen_schematic.py` → `schematic.svg`, `e36-kline-onboard.net` | Esquema y netlist, generados de **las mismas redes** que la placa y verificados contra ellas. |
| `export.py` → `fab/` | DRC, gerbers (`e36-kline-onboard-gerbers.zip`), `bom-jlcpcb.csv`, `cpl-jlcpcb.csv`, renders. |
| `pricing.py` → `fab/pricing-jlcpcb.md` | Estimación de precio JLCPCB (API de partes + tarifas publicadas): partes, fijos, totales por cantidad. |
| `pcbway.py` → `fab/pcbway/`, `fab/pcbway-sample-order.zip` | Paquete de pedido PCBWay para 1 muestra ensamblada: BOM en su formato con MPN, centroides, dibujo de armado, notas y parámetros del formulario. |
| `case.py` → `case/` | Caja de dos piezas (STL listos para imprimir, STEP, ensamble con referencias). |
| `render_case.py` → `case/render-*.png` | Renders en Blender de la caja con la placa real (GLB exportado por kicad-cli) adentro. |

Estado: **DRC 0 errores, 0 desconexiones** (KiCad 10.0.5). Quedan solo avisos de serigrafía
(referencias de 0603 que pisan pads); JLC los recorta solos.

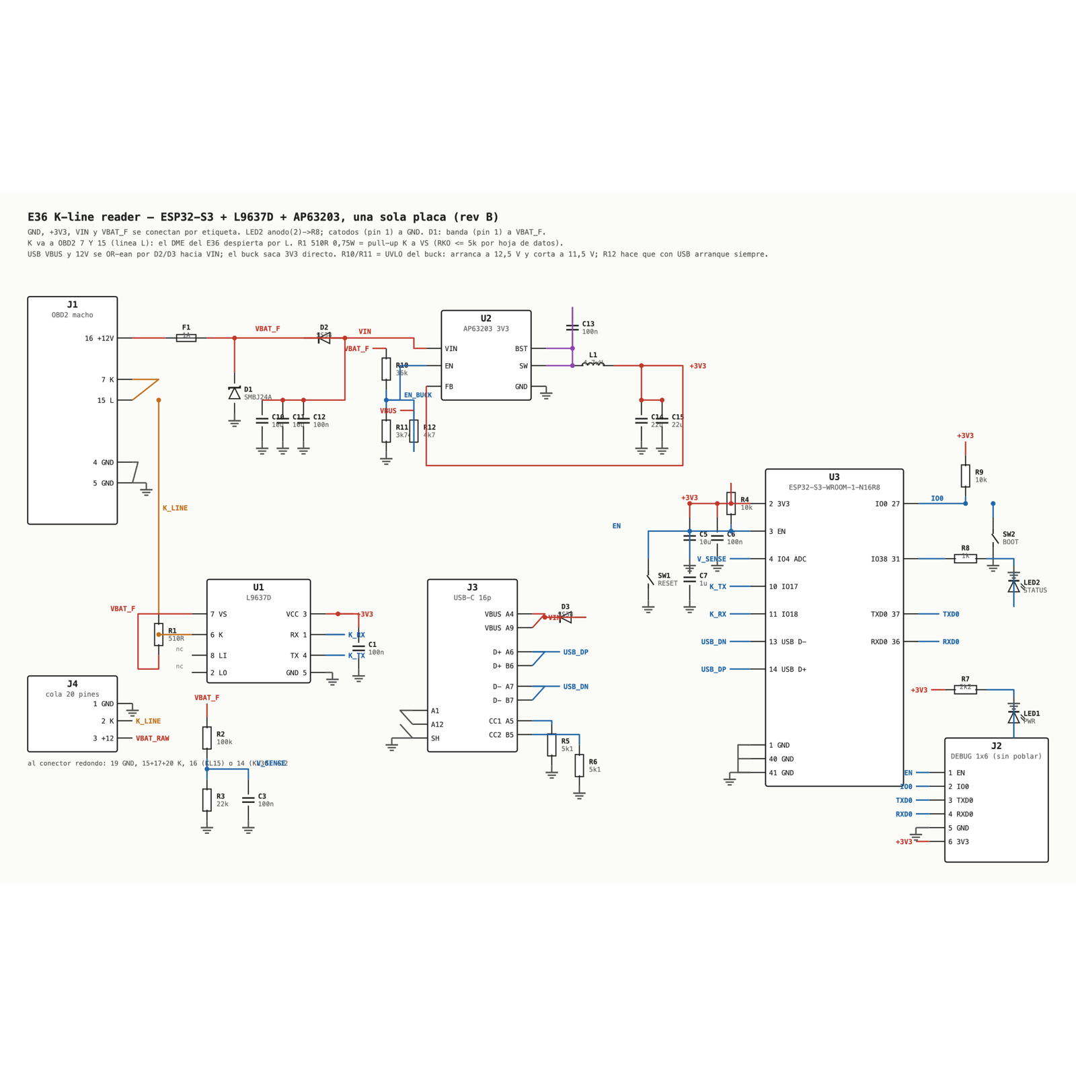
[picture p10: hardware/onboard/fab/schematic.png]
Esquema


## Qué hay en la placa

```
 OBD2 16 ─ F1 1A ─┬─ D1 TVS SMBJ24A ─ GND
                  ├─ R1 510R ─ K ─── OBD2 7 y 15 ──┐
                  ├─ U1 L9637D VS        K ────────┘   RX → GPIO18   TX ← GPIO17
                  ├─ R2 100k / R3 22k ── V_SENSE → GPIO4 (ADC1)
                  ├─ R10 36k / R11 3k74 ─ EN del buck (UVLO: ON 12,5 V, OFF 11,5 V)
                  └─ D2 SS34 ─┬─ VIN ─ U2 AP63203 ─ L1 4.7µH ─ 3V3 ─ ESP32-S3-WROOM-1-N16R8
 USB-C VBUS ─ D3 SS34 ────────┘  └ R12 4k7 → EN (con USB arranca siempre)   │
 USB-C D+/D- ─────────────────────────────────────────── GPIO20/19 ┘
 J4 (cola al redondo de 20): 1 GND · 2 K · 3 +12   — en paralelo con la ficha OBD2
```

- **3,3 V directo desde los 12 V**, sin riel de 5 V. El único consumidor de 5 V era el DevKit.
  El AP63203 (3,8–32 V de entrada, 2 A, salida fija 3,3 V, 1,1 MHz) alimenta módulo y L9637D.
  FB va directo a 3V3 (versión de salida fija).
- **Corte por batería baja, en hardware.** El pin EN del buck tiene umbral de precisión (1,18 V
  sube / 1,10 V baja) y dos fuentes de corriente internas (1,5 µA fija + 4 µA de histéresis).
  Con R10 = 36k desde VBAT_F y R11 = 3,74k a GND (Eq. 1 y 2 de la hoja de datos) el buck
  **arranca a 12,5 V y corta a 11,5 V**: con el motor andando (13,1–14,4 V) está siempre
  encendido; con el motor parado sigue hasta que la batería baja a 11,5 V y ahí se apaga solo,
  quedando el consumo en ~1 mA (1 µA del buck apagado + los divisores + el reposo del L9637D).
  R12 = 4k7 desde VBUS fuerza EN por encima del umbral: **con USB arranca siempre**, haya auto
  o no. La ventana entre batería en reposo (12,6–12,8 V) y alternador flojo (13,1 V) es
  demasiado angosta para detectar "motor parado" solo con resistencias, así que el corte
  duro es el piso de seguridad: lo que evita el drenaje diario es el **deep sleep por
  V_SENSE** en el firmware (dormir por debajo de ~12,9 V unos minutos, despertar y medir).
  Para otros umbrales: `R10 = (0,932·VON − VOFF)/4,1 µA`, `R11 = 1,1·R10/(VOFF − 1,1 + 5,5 µA·R10)`.
- **USB-C solo para programar y para el banco**: VBUS y los 12 V del auto se OR-ean por D2/D3 hacia
  VIN. Con el auto y la notebook enchufados a la vez mandan los 12 V; nada vuelve a la notebook.
  Sin auto, la línea K y V_SENSE están muertas; el ESP32 arranca igual.
- **L9637D** igual que el prototipo que funcionó: VCC a 3,3 V (mínimo 3 V, lógica compatible
  sin conversor), VS a los 12 V filtrados, K a los pines **7 y 15** (el DME despierta por L).
  R1 510 Ω es el pull-up de K a VS que exige la hoja de datos. A 14 V disipa 0,38 W mientras K
  está baja, así que va en **2010** (0,75 W), no en 0805 como en la placa anterior.
- **D1 con la banda hacia +12 V.** En `../kline-frontend` el TVS estaba al revés en el netlist
  (ánodo a +12 V): conduciría a 0,7 V y volaría el fusible. Acá pad 1 (cátodo) = VBAT_F.
  Polaridad invertida del auto → el TVS conduce en directo y F1 corta. Ese es el mecanismo.
- **Sensado de batería**: 100k/22k → 16 V = 2,88 V en GPIO4. `V = 3,3 × adc/4095 × 122/22`.
  El firmware de hoy no lo lee (la tensión viene del DME por K); queda para dormir el módulo
  cuando el motor está parado — el pin 16 es +12 V **permanente**.
- **Módulo entero sobre la placa**, con la antena en el borde superior y una zona prohibida
  (sin cobre, pistas ni vías en las dos caras) de 53–90 × 0–6,5 mm: la opción 2 de la guía de
  Espressif. Se eligió para que la caja sea un prisma liso; la opción 1 (antena colgando) rinde
  algo mejor pero obliga a un saliente. La pared de la caja frente a la antena no puede ser
  metálica ni con carga de carbono.
- **Directo al conector redondo de 20 pines del E36, sin adaptador.** J4 es una JST-XH de 3 vías en
  paralelo con la ficha OBD2: 1 GND, 2 K, 3 +12 V. Se le suelda una cola cortada de un adaptador
  20→OBD2 (o un macho de 20 con cables): **19 → GND, 15+17+20 juntos → K, y el +12 de 16 (KL15,
  ignición) o de 14 (KL30, batería)**. Tomando el +12 del **pin 16** la placa se apaga con la
  llave y el drenaje de batería desaparece del todo; el OBD2 no tiene ese pin, por eso ahí hace
  falta el UVLO y el deep sleep. El macho de 20 no existe para montar en PCB: va por cable. Para
  ese uso, `CASE_PIGTAIL=1 case.py` genera la caja con la pared cerrada y un pasacable de 7 mm en
  vez de la muesca de la ficha.
- **USB: solo el nativo (GPIO19/20), sin puente CH340/CH9102.** Es el puerto "USB" del DevKit, no
  el "COM": MicroPython, `mpremote` y la REPL andan sin tocar nada; grabar la imagen de MicroPython
  exige BOOT apretado al resetear (una vez). Se evaluó poner un CH340C con auto-reset y se descartó
  por innecesario.
- EN: 10k + 1 µF + botón RESET. IO0: 10k + botón BOOT. Programación por el USB nativo
  (GPIO19/20) o por J2 (UART0, sin poblar; pines **EN IO0 TX0 RX0 GND 3V3**). LED verde = 3V3;
  LED ámbar en **GPIO38** (el mismo del RGB del DevKitC-1 v1.1, así el firmware no cambia de pin).

### Pines del ESP32 que usa el firmware

| GPIO | Función | Pin del módulo |
|---|---|---|
| 17 | K_TX → L9637D TX (UART1 + bit-bang del init a 5 baudios) | 10 |
| 18 | K_RX ← L9637D RX | 11 |
| 4 | V_SENSE (ADC1_CH3, funciona con WiFi) | 4 |
| 38 | LED de estado (ámbar) | 31 |
| 0 | BOOT (botón, pull-up 10k) | 27 |
| 19 / 20 | USB D− / D+ | 13 / 14 |
| 43 / 44 | TXD0 / RXD0 → J2 | 37 / 36 |

`firmware/mp/kline.py` sigue con `TX_PIN = 17`, `RX_PIN = 18`: no cambia nada.
En la N16R8 los GPIO 33–37 son de la PSRAM y no se usan.

## La ficha OBD2

Es un macho J1962 acodado de montaje en PCB — el mismo formato que usan los ELM327 y el
**Macchina CCBDM20**. El footprint se construyó desde el STEP y el plano de ese conector,
no de una foto:

| Dato | Valor |
|---|---|
| Paso entre pines de una fila | **4,00 mm** |
| Separación entre filas | **3,00 mm** |
| Fila 1–8 (la de abajo en la cara de enchufe, lado ancho de la D) | 2,25 mm detrás de la brida |
| Fila 9–16 | 5,25 mm detrás de la brida |
| Pata de soldadura | 0,9 × 0,8 mm, ~2,2 mm de largo → agujero 1,3 mm, pad 2,1 mm |
| Cuerpo | 40,3 mm de ancho, todo fuera de la placa; la brida apoya en el borde |

El borde izquierdo de la placa es el plano trasero de la brida. Pin 1 arriba (y = 10 mm),
pin 8 abajo; pines 9–16 en la segunda fila. Solo 4, 5 (GND), 7 (K), 15 (L) y 16 (+12 V) van
a algo; los otros once pads quedan sueltos.

**Antes de soldar el conector**, con la placa sin enchufar al auto, medir continuidad entre
la cara de enchufe y los pads: el pin 16 del macho (esquina, fila de abajo con el lado ancho
arriba, extremo izquierdo mirando los pines) tiene que llegar al pad marcado 16. Si el
conector que compraste está espejado respecto del CCBDM20, el error es **benigno**: +12 V
caería en el pad 9 (sin conectar) y la placa simplemente no encendería. Nada se quema.

## Antes de mandar a fabricar

**Precio** (estimado con `pricing.py`, 2026-09-11, ensamblado económico, sin envío): unas **97 USD por 5 placas
(≈19 c/u)** o **140 USD por 10 (≈14 c/u)**; los fijos son 43 USD (setup 8,18 + stencil 1,53 + 11 partes
extendidas × 3,07) y las partes ≈10 USD por placa, de los cuales el módulo son 5. Detalle en
[`fab/pricing-jlcpcb.md`](fab/pricing-jlcpcb.md). La ficha OBD2 va aparte (sin stock en JLC). Para **una sola muestra
con la ficha soldada por la fábrica**, PCBWay: paquete listo en `fab/pcbway/` (`ORDER-NOTES.md` tiene los valores del
formulario y el texto de instrucciones). **Cotización oficial** del motor de PCBWay (`fab/pcbway/quote-official.md`):
PCB 5 pcs 6,50 USD + ensamblado 1 placa 88,00 USD (tarifa plana) + envío FedEx 48,87 / DHL 72,73; componentes
aparte (≈15–25 USD): ≈160–170 USD la muestra.

1. **Números LCSC.** Los marcados `verificar` o `C?` en `fab/bom-jlcpcb.csv` hay que
   confirmarlos en la librería de JLC al momento de pedir: L9637D (C130489), módulo
   ESP32-S3-WROOM-1-**N16R8** (C2913202), inductor SWPA6045S4R7MT (C78804), TVS SMBJ24A,
   capacitores 1210 10 µF/50 V X7R, la 2010 de 510 Ω y la 0603 de 3,74k (E96). El resto son
   básicos de JLC.
2. **Variante del módulo.** El firmware cargado es `ESP32_GENERIC_S3-SPIRAM_OCT`: necesita
   PSRAM octal → **N16R8** (o N8R8). Una N16 sin R8 arranca pero ese build no.
3. **Ficha OBD2.** J1 es THT: soldarla a mano (patas cortas, estañar desde abajo) o pedir el
   ensamblado TH de JLC (`C9900166046`, "OBD-II-16P-Male-90-Deg", sin plano público:
   verificar su footprint contra la tabla de arriba antes de confiar).
4. **Capacidades JLC**: 2 capas, 1,6 mm, 1 oz. Pista mínima usada 0,187 mm (los cuellos que
   deja Freerouting en los pines finos), holgura mínima 0,15 mm, vía 0,7/0,35, taladro mínimo
   0,3. Todo dentro de lo estándar (0,127 mm / 0,3 mm).
5. **En la vista previa de JLC** revisar la rotación de lo polarizado: D1, D2, D3 (banda),
   LED1/LED2, U1 (pin 1), U2, U3. El CPL sale con el origen en la esquina inferior izquierda.
6. J2 no se puebla (está fuera del BOM y del CPL).
7. La caja es `case.py` (sección **La caja**); la `../elm-backpack` no sirve para esta placa.
8. Si vas directo al conector de 20 pines, no hace falta soldar la ficha OBD2 (J1): con J4 y la
   cola alcanza, y la caja `-pigtail` cierra esa pared.

## La caja

`case.py` (build123d, `~/Desktop/E36_OBD/.cadenv/bin/python hardware/onboard/case.py`) genera
en `case/` una caja de **tres piezas** para **esta** placa, con las mismas coordenadas de
`gen_board.py`: base y tapa en negro y el **emblema =BMW= aparte, en plata**, que encaja a ras
en un cajeado de la tapa. La `../elm-backpack` no sirve: era para las placas sueltas.

Caja cerrada

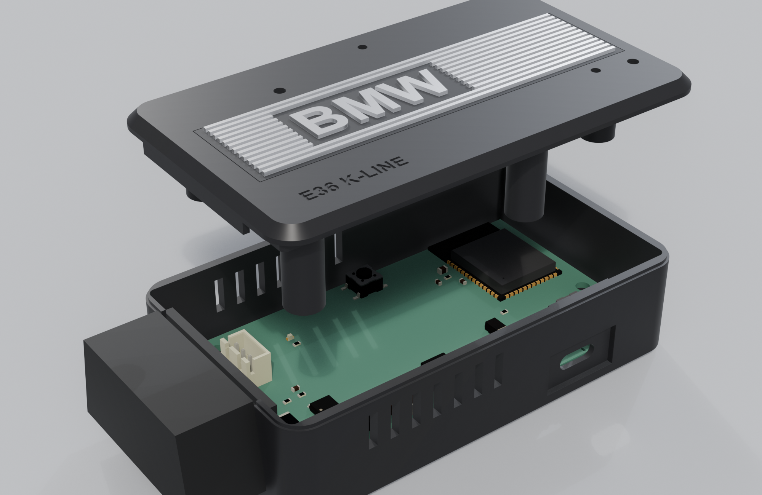
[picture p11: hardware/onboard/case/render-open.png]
Caja abierta con la placa


| | |
|---|---|
| Exterior | **96,8 × 56,0 × 27,0 mm**, prisma liso, más los 16 mm del conector |
| Forma | esquinas verticales R6, chaflán de 45° de 2 mm en el borde de la tapa y de 1,5 mm en el del piso, línea de sombra de 0,5 mm en la junta; tapa lisa |
| Paredes / piso / tapa | 2,4 / 2,4 / 3,0 mm; la pared del conector 1,5 mm |
| Interior sobre la placa | 17 mm — lo fija la brida del conector (15,6 mm), no la electrónica (máx. 5 mm) |
| Sujeción | 4 × **M3 × 12** desde abajo, cabeza embutida; pasan por los separadores (3 mm) y la placa y roscan en **insertos M3 termofijados** (latón, Ø4,6 × 4,6; agujero impreso Ø4,0 × 5,5) en los postes Ø7,5 de la tapa. Sin tornillos a la vista |
| Variante | `CASE_PIGTAIL=1`: sin muesca para la ficha OBD2, pared izquierda cerrada con pasacable Ø7 para la cola al conector de 20 (`base-pigtail.stl`, `lid-pigtail.stl`) |
| Conector OBD2 | la pared entra en el **cuello de 2 mm** del conector: la brida queda adentro, el cuerpo afuera. La muesca está abierta hacia arriba para bajar la placa; la lengüeta de la tapa la cierra |
| USB-C | **la ficha atraviesa la pared**: sobresale 1,6 mm del borde de la placa y pasa por una abertura con la forma de su blindaje (estadio 9,4 × 3,6, 0,22 de juego por lado) en una pared local de 1,3 mm; la boca queda a ras del fondo de un bisel de 18 × 10 donde entra el sobremoldeado del cable. Una repisa de 1,2 mm bajo el borde de la placa toma el empuje del enchufe |
| Antena | queda dentro, contra la pared trasera: esa pared no puede ser metálica ni con carga de carbono |
| Botones | agujeros Ø2 sobre RESET y BOOT: se pulsan con un clip, no hay botones a la vista (BOOT se movió en la placa a (77,5, 39) para dejar libre la banda del emblema) |
| LEDs | dos **guías de luz**: varilla acrílica Ø3 × 16 mm pegada desde adentro en un agujero Ø3,1 con tope a 0,5 mm de la cara (se ve un punto de Ø2,4) |
| Emblema | pieza aparte `badge.stl`, **85 × 22 × 1,6 mm**, copiada de la tapa M50: campo negro, **13 nervios finos** (0,8 mm de ancho, paso 1,6) que corren a lo largo, y la placa "BMW" **corrida hacia la ficha**, de 12 mm de alto: interrumpe solo los siete nervios del medio; los tres de arriba y los tres de abajo siguen enteros a lo largo, como en el motor. Nervios y letras en relieve de 0,8 mm en plata: se imprime relieve arriba con un **cambio de filamento en la capa de 1,6 mm** (negro → plata) o en dos colores con el AMS. Entra a ras en el cajeado de la tapa con 0,15 de juego por lado; se pega con cianoacrilato |
| Piso | grabado "E36 K-LINE rev B" y el pinout OBD2 |
| Otros | 7 respiraderos por lado (2 × 8 mm), dos ranuras 3 × 12 en el piso para un precinto |

Archivos: `base.stl` (piso abajo), `lid.stl` (**ya dada vuelta**, cara exterior abajo), `badge.stl`
(relieve arriba), `base.step`, `lid.step` (en coordenadas de montaje) y `assembly.step` con la placa,
el módulo, el conector (cuerpo en D real) y los volúmenes de los componentes más altos como referencia.
Los renders (`render_case.py`, Blender EEVEE con tres soles y piso) muestran la ficha OBD2 con su
forma en D. Renders: `render_case.py` (Blender 4.5,
Workbench) mete el GLB de la placa (`kicad-cli pcb export glb --drill-origin`) en la caja y saca
`render-assembled/open/board/rear/connector-end.png`. El conector se dibuja como bloque: no hay
modelo 3D libre del CCBDM20 en KiCad.

Verificado por el script: cada pieza es un sólido válido y ninguna interfiere con la placa, el
módulo, la brida/cuello/cuerpo del conector, el USB-C, los botones, el inductor, el TVS ni los
pads de la ficha (la muesca del conector pasa la prueba con 0,15 mm hacia el cuerpo y 0,35 hacia la
brida), y el emblema no toca la tapa. Los chaflanes de 45° se imprimen sin soporte en las dos
piezas (cara exterior contra la cama en la tapa). **No verificado**: el juego real del cuello contra un conector medido, la tolerancia de tu
impresora en los pilotos de 2,6 mm y en el labio de 0,3 mm, y la temperatura en vano motor (ASA).

Imprimir: 0,4 mm, 0,2 mm de capa, 4 paredes; base piso abajo, tapa cara exterior abajo (los
grabados quedan contra la cama, como en la elm-backpack), emblema como viene (relieve arriba, en
plata; con 0,12 mm de capa queda más fino). Sin soportes salvo, si hace falta, el techo de la
abertura USB. Después: cuatro insertos M3 con el soldador en los postes de la tapa, dos varillas
acrílicas Ø3 cortadas a 16 mm en los agujeros de los LEDs, y el emblema pegado en su cajeado.

## Lo que no se verificó

- **Encaje físico del conector.** Sale de un STEP, no de un conector medido. Antes de soldar,
  apoyar el conector sobre la placa y ver que las 16 patas entren.
- **Ruteo automático.** Freerouting (2.4.1, 30 pasadas) hizo las pistas; yo fijé colocación,
  anchos por clase (potencia 0,8 mm, K 0,5, USB 0,2, señal 0,25) y 80 vías de costura de GND.
  El lazo del buck es corto (SW → L1 a 2,4 mm) pero no está optimizado a mano.
- **Térmica en vano motor.** AP63203 hasta 125 °C de juntura; módulo −40…85 °C ambiente.
  Nadie midió la temperatura donde va a vivir.
- **Consumo con motor parado.** ~40–100 mA continuos del módulo despierto = 1–2,4 Ah/día de la
  batería. Es firmware (deep sleep por V_SENSE), no placa.

## Regenerar

```sh
PY=/Applications/KiCad/KiCad.app/Contents/Frameworks/Python.framework/Versions/3.9/bin/python3
$PY hardware/onboard/gen_board.py                # colocación + redes + zonas, sin pistas
FREEROUTING=/tmp/fr/freerouting.jar PASSES=30 \
$PY hardware/onboard/gen_board.py --route        # exporta DSN, rutea, importa SES, cose GND
$PY hardware/onboard/export.py                   # DRC, gerbers, BOM, CPL, renders en fab/
python3 hardware/onboard/gen_schematic.py        # schematic.svg + .net verificados contra N
```

Freerouting: `curl -L -o /tmp/fr/freerouting.jar https://github.com/freerouting/freerouting/releases/download/v2.4.1/freerouting-2.4.1.jar`
(necesita Java 21+; con `-mt 1` para que el optimizador no genere violaciones de holgura).

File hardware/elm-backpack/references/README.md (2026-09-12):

# Original enclosure reference images

The eight images supplied in the enclosure-design chat, preserved with their original filenames. The related-board dimensions and photo estimates remain provisional; these are not dimensioned scans.

- [C7Ws7u/image.png](<C7Ws7u/image.png>)
- [1oUab5/Screenshot 2026-09-07 at 21.01.18.png](<1oUab5/Screenshot 2026-09-07 at 21.01.18.png>)
- [C2j69D/image.png](<C2j69D/image.png>)
- [JtD1lp/Screenshot 2026-09-07 at 21.01.42.png](<JtD1lp/Screenshot 2026-09-07 at 21.01.42.png>)
- [NnfwtA/Screenshot 2026-09-07 at 21.02.11.png](<NnfwtA/Screenshot 2026-09-07 at 21.02.11.png>)
- [IZgJo3/WhatsApp Image 2026-09-07 at 21.03.03 (2).jpeg](<IZgJo3/WhatsApp Image 2026-09-07 at 21.03.03 (2).jpeg>)
- [bQd2Rp/WhatsApp Image 2026-09-07 at 21.03.03 (1).jpeg](<bQd2Rp/WhatsApp Image 2026-09-07 at 21.03.03 (1).jpeg>)
- [BzqjeP/WhatsApp Image 2026-09-07 at 21.03.03.jpeg](<BzqjeP/WhatsApp Image 2026-09-07 at 21.03.03.jpeg>)

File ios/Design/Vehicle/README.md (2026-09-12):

# Vehicle reconstruction

The editable asset reconstructs the owner's 295 Samoablau Metallic four-door 1994 E36 316i from photographs. Open `E36-316i.blend` for the vehicle and native Cycles materials. `ReferenceLighting.blend` links that vehicle into three photographic camera studies. The photographs provide appearance and camera landmarks; they are not a dimensional scan or a measured lighting environment. The retained wheel casting remains an approximation.

## Geometry and finish

The accepted early kidney outline is preserved. The erroneous additional 16.7-degree pitch has been removed without changing the traced front silhouette. The original hood, nose carrier and upper bumper alignment is restored exactly. Grille depth follows the untouched carrier surface; two narrow recessed mounting returns close the aperture gaps behind the chrome. The traced X/Z outline and object rotations stay unchanged. `alignment-validation.json` verifies zero displacement across all 215,709 evaluated body vertices and 14,628 upper bumper vertices. The earlier whole-carrier deformation was rejected. The M front bumper contains hollow air ducts tessellated from the supplied `FogIntake.step` at its original scale, with a mirrored opposite side. Their flanges are recessed 4.5 mm into the bumper seats. The lower bumper has a rounded moulded return instead of the previous thin, sharply folded edge. `front-fit-validation.json` records these geometry changes and the reviewed close-up angles.

Body badges and wheel caps use the supplied artwork. The hood and trunk roundels have shallow convex faces, rolled metal rims and locally fitted native recesses. The white quadrants are enamel; the lettering and dividers have a metallic mask and fine relief normal map. `BadgeReview/` records the accepted model detail review. The two rear headrests have been removed while preserving the bench and front seats. The rear 316i lettering follows the trunk surface, inset from its top crease and outside seam. The stock rear bumper has a separate black rubbing strip and a central charcoal lower insert; its lower corner returns remain body blue. The exhaust body is tucked behind the apron so the short outlet remains visible.

The cabin is left-hand drive: steering wheel, column, pedals and instrument pod are on the vehicle's left, with the glovebox on the right and the center console facing the driver. The steering roundel, dial markings and control labels retain their readable orientation. This corrects the original donor interior without reflecting the car. `left-hand-drive-validation.json` records unchanged exterior geometry, normals, UVs, materials, seats and ride height. Both linked Blender scenes and the portable/app exports use the corrected cabin; the app's ambient visibility has been rebaked.

The model is frozen at the user's request for the scene/material pass. The badge pocket edits leave the main carrier and upper bumper vertices exactly unchanged; the bonnet front boundary differs by at most 0.043 mm through subdivision. `FrontFit/` is the earlier alignment review, not a render of the latest badges. See the source hashes in each gallery.

The final app has a separately requested stance variant: the sprung body drops 30 mm at the front axle and 15 mm at the rear, adding about 0.32° of forward rake. All body parts receive the same rigid transform, preserving their alignment. Wheel, tyre, brake and lower suspension transforms remain fixed. The source `.blend`, GLB and portable USDZ retain the reference ride height. `prepare_vehicle_stance.py` creates the app derivative and verifies unchanged mesh/normal/UV data and tyre transforms; its report accompanies the runtime. The sampled arch-crown gap reduces from about 61 to 32 mm at the front and 67 to 52 mm at the rear.

The Samoablau pigment is inferred from three low-glare panels in the owner's RAW photograph after EXIF orientation and Display P3-to-sRGB conversion. Sky-reflection samples are kept separate. The linear pigment is `(0.1110, 0.1420, 0.2123)`, with metallic coverage `0.22`, base roughness `0.30` and clearcoat roughness `0.055`. These are rendering parameters, not a measured paint formula. `paint-samples.jpg`, `paint-samples.json` and `paint-calibration.json` preserve the sampling evidence.

The native source retains layered Samoablau paint, optical glass, lamp optics, rubber, cast aluminum, chrome and fabric materials. `HD/` contains separate Cycles previews. These are offline renders, not screenshots of the iPhone renderer. See each manifest for the exact source revision used; older previews must not be treated as evidence of a newer runtime revision.

## App rendering

`../../E36OBD/VehicleScene/` contains the actual geometry rendered by Swift, RealityKit and Metal. Horizontal dragging orbits continuously, pinching zooms, two-finger dragging changes elevation, and double tapping resets the view. Camera pose survives orientation and tab changes. The renderer does not access Bluetooth or recording and stops submitting frames while idle or in the background.

The bundled USDZ differs from the portable source export. Ambient visibility is ray traced into vertex alpha. The fixed studio also has a direct/indirect diffuse bake in vertex RGB, matched to the final studio environment, pose and material parameters. Metal supplies the live specular and clearcoat reflections. It preserves the original specular F0 while suppressing the native diffuse lobe, then adds the decoded bake; diffuse is counted once. The daylight alternative evaluates the complete live PBR response and uses only baked ambient visibility. No body geometry, split normal or UV is decimated during packing. Smooth world-space glazing normals avoid triangle-shaped reflections. Ground shadows contain no car pixels.

The default **Grafito** scene uses Poly Haven Studio Small 09, rotated and exposed after native camera comparisons. The imported Samoablau pigment is unchanged. The matte receiving floor is lit by the same probe, and the studio shadow covers 20 m with a distant edge fade. The optional **Luz natural** scene pairs Park Parking reflections with its corresponding world-fixed background. [Scene study](SCENE_STUDY.md) records the comparisons, sources and limits.

In the daylight alternative, paint and glass share a prefiltered Park Parking HDR environment. Its spherical mean luminance matches the previous probe, preserving the pigment calibration while changing the sky, ground and directional light. The model remains freely viewable geometry; it is not an image turntable. A lighting change requires regenerating the ground shadow; a stance change also requires refreshing geometry-dependent occlusion. Portable GLB/USDZ files use standard PBR approximations and do not depend on the app's shaders. `AppLighting.blend` is the separate app-stance lighting scene; `AppLighting/` contains its offline previews.

The app renders into a scene-linear RGBA16Float target, then applies a compiled AgX Medium High Contrast display transform. The 64³ half-float LUT is generated from Blender's OCIO configuration; the app does not load OCIO. Highlights remain HDR until the final display conversion. The display stage composites dashboard black after tone mapping. Up to 1.5× spatial supersampling (2560-pixel long-edge cap), four-tap linear-radiance resolve and 4× coverage MSAA reduce fine-edge breakup. No temporal history or motion trails are used, and the GPU still rests when idle.

Runtime paint uses metallic coverage 0.50, base roughness 0.22 and clearcoat roughness 0.055, with derivative-based microfacet filtering. The sampled Samoablau pigment remains unchanged. The image-based lighting exponent is 0.15, half a stop below the prior 0.65 setting. This balances deeper panel shading with clearer metallic reflections; it is a visual calibration of the mobile BRDF, not a measured paint composition. Dielectric reflectance respects the imported specular control rather than assigning every surface the same F0. The headlamps use two synchronized scene passes: the first captures the reflectors without the optical shells, and the second refracts that HDR image through the molded lens before adding Fresnel reflection. Both air/glass/air interfaces are evaluated on the front shell; the rear shell is hidden. Circular lenses draw before the rectangular cover in a `ModelSortGroup` with a post-pass depth stage, and the glass does not write depth during shading. This corrects the cover hiding most of the lens treatment while retaining the opaque bodywork's depth test. Zoned 3.8 mm ribs distinguish the two optics, and filtered circular relief defines their molded edges.

The refracted ray is projected onto the existing 43 mm-deep parabolic cup with a 59.3 mm radius and roughly 8 mm clearance at its lip. These dimensions describe the existing model, not measurements of the physical headlamp. The passes use the same camera snapshot and no prior-frame history; rear and side views skip the hidden headlamp pass. This screen-space approximation cannot trace off-screen geometry or multiple internal bounces. The front and side indicators now have a prismatic amber return beneath their existing clear cover. Absorption and relief approximate the reference appearance; they do not emit light or indicate vehicle lamp state. Reflectors retain their imported surface parameters. Taillight covers use the same dielectric Fresnel treatment instead of the imported semitransparent metallic material; red/amber plastic has a single surface-reflection layer. `MetalReview/` contains actual simulator frames and revision hashes, including a close camera for the complete headlamp and indicator. [Before/after](../headlamp-comparison.jpg), [close-up](../headlamp-closeup.jpg) and `optics-validation.json` document this pass. Simulator results do not establish iPhone frame rate or thermal performance.

## Regeneration

Use Blender 4.5 with Metal on macOS. No Python runtime, Blender installation or network service is required by the app.

```sh
/Applications/Blender.app/Contents/MacOS/Blender \
  --background --factory-startup --disable-autoexec \
  ios/Design/Vehicle/E36-316i.blend --python ios/tools/export_vehicle.py

python3 ios/tools/prepare_vehicle_exhaust.py \
  ios/Design/Vehicle/E36-316i.usdz \
  .context/vehicle-exhaust/E36-Tucked.usdz

python3 ios/tools/prepare_photographic_studio.py

python3 ios/tools/prepare_vehicle_stance.py \
  --source .context/vehicle-exhaust/E36-Tucked.usdz \
  --output .context/vehicle-stance --front-mm 30 --rear-mm 15

/Applications/Blender.app/Contents/MacOS/Blender \
  --background --factory-startup --disable-autoexec \
  --python ios/tools/bake_vehicle_lighting.py -- \
  --model .context/vehicle-stance/E36-AppStance.usdz \
  --environment ios/Design/Vehicle/SoftboxEnvironment.exr \
  --output .context/vehicle-lighting --exposure 0 --hybrid-studio --skip-native-save

python3 ios/tools/pack_vehicle_lighting.py .context/vehicle-lighting
```

Download the CC0 [Studio Small 09 HDR](https://polyhaven.com/a/studio_small_09) and pass its path to `prepare_photographic_studio.py --source` when the local source cache is absent. That tool requires OpenImageIO and NumPy.

The exhaust, stance and packing tools need NumPy and Pixar's `usd-core` in the development Python environment. Packing preserves corner positions, split normals and UV seams exactly while removing unused UV sets and consolidating redundant vertex indices. Validate the bake against the stance derivative, not the original ride-height export. Review the baked model in the simulator before replacing the bundled model. The bake and stance reports record source/environment hashes, exposure, encoding and output hashes; keep them beside the corresponding USDZ. When changing ride height or lighting, regenerate both ground shadows with `prepare_vehicle_shadows.py` from the same transformed geometry and environment.

Regenerate the display LUT with `python ios/tools/build_vehicle_display_lut.py` in an authoring environment containing NumPy and `opencolorio`. The generator validates interpolation against 20,000 deterministic OCIO samples and writes its configuration hash, domain and error statistics beside the LUT.

Prepare the runtime coordinate conversion before prefiltering with Xcode’s `realitytool`. A six-direction RGB-gradient probe found a 90° equirectangular convention offset after converting Blender Z-up to the app’s Y-up. The preparation tool shifts columns without interpolation or clipping; it preserves the original HDR for Blender bakes. `environment-orientation-validation.json` records the uncorrected failure and corrected axes.

```sh
python3 ios/tools/prepare_vehicle_environment.py \
  --source ios/E36OBD/VehicleScene/StudioEnvironment.exr \
  --output .context/vehicle-lighting/RealityKitEnvironment.exr

xcrun realitytool image --platform iphoneos --deployment-target 18.0 \
  --cube-face-size 1024 --specular-size 1024 --diffuse-size 64 \
  --ibl-sampling-quality high \
  --output-reality-asset ios/E36OBD/VehicleScene/StudioEnvironment.realityenv \
  .context/vehicle-lighting/RealityKitEnvironment.exr
```

The environment preparation tool requires NumPy and OpenImageIO during authoring. Keep its report with the compiled resource hashes in `scene-settings.json`.

Debug simulator builds accept `--demo --vehicle-review=nose` (or `rear`, `side`, `optics`) to render a fixed photo-matched camera. `--vehicle-review=cabin` checks the driving position from between the front seats with the complete model visible. These review views are excluded from Release and do not alter the normal dashboard. Compare actual Metal screenshots, not only Blender previews, when evaluating runtime materials.

`ios/tools/render_vehicle.py` produces an optional offline turntable under `.context/vehicle-turntable`; it does not populate app resources. `ios/tools/render_vehicle_references.py` regenerates the photographic studies. Source attribution and reconstruction limits are in [CREDITS.md](CREDITS.md); validation is in [../../VALIDATION.md](../../VALIDATION.md).

### Rear lower insert (11 September)

The lower central apron now meets the underside of the bumper corners. Its previous 34 mm downward bow is removed, with a smooth transition into the corners and the exhaust notch retained. This is a local mesh correction; the upper seam, paint/black boundaries, other 386 meshes, left-hand-drive cabin and wheel stance are unchanged. The app USDZ, ambient visibility and ground shadow were regenerated from the corrected source. See `rear-apron-validation.json`. The `--vehicle-review=apron` Debug camera inspects the actual Metal asset from behind.

The rectangular headlamp cover now carries a combined front/back dielectric reflection, a broad low-intensity return, and derivative-filtered moulding across the complete assembly. This keeps the outer glass visible between the two circular optics. The correction is limited to the front headlamp covers; paint, cabin glass, amber plastic, and the vehicle geometry are unchanged. See [the Metal close-up](../Widgets/headlamp-detail.png).

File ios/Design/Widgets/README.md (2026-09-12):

# Widget and motion revision

Three widget designs share the same dated observation: Instrument, Garage and OBC. Garage and OBC provide small, medium and large sizes; all three provide the small size for StandBy and CarPlay. Each keeps units, missing-channel handling, sample age and source-separated storage.

Large Garage gives the car the full width above all five readings. Large OBC emphasizes the selected channel with four secondary readings below. Both use `systemLarge`, the largest iPhone Home Screen widget family supported by the current Xcode 26.2 toolchain. These sizes do not change the smaller CarPlay presentation.

The Garage image comes from the shipped Metal renderer and the app E36 mesh, with the same studio lighting and shaders. The app runs this scene in 3D; widgets use a transparent bitmap. No photograph cutout or substitute car is used. The image retains its full-color rendering in tinted widget appearances. Paint designation: **295 · Samoablau Metallic**.

To regenerate the bitmap, build the Debug simulator app and launch with `--demo --vehicle-review=widget --scene-study=graphite --widget-car-export`. After warm-up it writes `Documents/widget-car.png` in the simulator app container. Save that file, then repeat with `--widget-car-only` to capture the same camera without the shadow receiver. Run `python3 ios/Design/Widgets/prepare-car.py full-scene.png vehicle-only.png ios/WidgetShared/Assets.xcassets/WidgetCar.imageset/car.png`. The script isolates and feathers the shadow contribution while preserving the vehicle, and asserts completely transparent image edges. Cropping the original long studio shadow directly leaves the visible rectangle reported on the Home Screen. `car-render.json` records the adopted sources and crop. Both export flags are Debug-only and never change the production display transform. Use them only in the simulator.

In normal tabs, a single tap advances through exterior angles. Expanded mode provides horizontal/vertical orbit, unrestricted practical dolly and screen-plane panning, with simultaneous two-finger pan/pinch. Camera buttons and reset animate focus and distance back to a fitted view. Closing expanded mode removes its translation and distance from the dashboard camera; the same renderer survives. Camera buttons use the shortest orbit; tabs use their ordered quarter-turns. The camera moves around the stationary car and lights. There is no idle animation, no motion driven by telemetry, and no rendering while Instruments, the connection sheet or the app background hides the scene. Reduce Motion makes view changes immediate and disables coast.

The supplied BMW roundel is also the iPhone and Watch app icon. DEMO badges and notification/export prefixes have been removed; simulation remains an explicit selectable data source and keeps its own storage.

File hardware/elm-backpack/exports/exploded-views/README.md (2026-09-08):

# E36 inline adapter — exploded views

Four high-resolution PNG plates generated from the approved revision E CAD:

1. assembly.png — labelled assembly overview
2. reverse.png — OBD-end three-quarter view
3. underside.png — hidden lid screws and bottom of the case
4. mounts.png — board retention and floor features

all-views.png combines all four. Files ending in -raw.png have transparent backgrounds for reuse. The per-view JSON files record the camera and source-geometry hash.

The boards remain complete assemblies. Straps and illustrative wiring are hidden for clarity; the underside view also hides the electronics and ELM. The lid is offset sideways in that view, and the board-mount view spreads the complete boards apart to reveal the seats. All offsets are for display only; the printable model is unchanged. Physical board fit remains provisional.

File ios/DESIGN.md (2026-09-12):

# E36 instrument design review

The first version treated each requirement as another visible component. It needed a coherent instrument architecture.

## Critique

| Problem in the first version | Consequence | Design change |
| --- | --- | --- |
| Alerts, errors and discovered devices were conditional children of the main vertical stack. | Their appearance changed the available height and resized or moved the gauges precisely when attention mattered most. | Instrument frames depend only on the viewport. A fixed annunciator strip owns transient states; device lists belong to the connection sheet. |
| Navigation either rebuilt the dashboard or covered it with cards that resembled dismissible trays. | Gauges lost their position, or selected tabs appeared to open temporary overlays. | Full content pages share a persistent dock. The dashboard stays mounted and hidden; returning reveals the same instrument positions. Only connection uses a native sheet. |
| The first version used orange for every UI role; the first redesign then made the scales white. | One lacked hierarchy; the other lost the illuminated E36 character. | Orange-red instrument markings, amber LCD readings, subdued unsupported RPM, and ordinary ivory/gray text in controls and secondary pages. |
| Circular bezels, triangular hands and metallic hubs resembled separate watches. | The result did not resemble the supplied BMW cluster. | Shared matte black background, flat broad needles, large black hubs, and fan-shaped auxiliary scales. |
| Five equal rectangular buttons. | Starting a capture had the same prominence as opening settings. | One clear En vivo/Detener action, three quiet navigation controls, and connection access in the header. |
| The demo selector, firmware status sentences and link timing occupied the driving screen. | Test controls and implementation detail competed with the vehicle. | One fixed DEMO menu; ECU latency and reception rate in the connection sheet. The main face retains the five channels, units and recording state. |
| A large amber panel occupied a separate row in landscape. | It reduced the available height for the main instruments. | Intake and recording status sit inside the existing bottom control bar; portrait uses a shallower, dark display. |
| Faults immediately exposed a running terminal; settings explained basic controls in paragraphs. | The app required reading before it could be scanned. | Fault records first, original messages behind Registro. Settings show thresholds and delivery controls; notifications, idle band and help are disclosed on demand. |
| Tests checked that screens existed, without checking stability. | A passing test did not establish good layout behavior. | UI tests compare the x/y/width/height of every main dial across warnings, multiple simultaneous alerts, engine-off, saturation, reconnection and navigation. |

## Interpreting the brief

The supplied illuminated E36 photograph determines the instruments' visual language. The Apple and watchmaking references inform hierarchy and precision without substituting a watch face for the BMW cluster. These are design interpretations, not claims of an official collaboration.

The tachometer uses a 232-degree sweep, numerals 0–7, half-thousand minor marks, condensed slanted numerals, the two-line 1/min ×1000 legend, a broad orange hand and a matte black hub. Its upper red blocks follow the photographed face, but the entire range above 2550 remains dimmed and labeled unavailable. Color bands are visual face markings; they do not change the configurable alert rules.

The coolant and battery instruments use short fan-shaped scales and channel-specific symbols. The load instrument adapts the denser main scale to milliseconds; it does not present speed or fuel data. Small amber seven-segment readings preserve exact values and units without dominating the analog faces. All lettering, hands, bands and LCD segments are drawn natively.

The dashboard uses a single native instrument composition. Portrait and landscape have intentional layouts; transient app state cannot choose a third layout. Readout values and units remain explicit. The unavailable 2550–7000 RPM sector remains honest, and saturation has its own reserved indication.

Secondary pages use ordinary readable text. Essential operating information is retained even when hidden from the default face: the complete firmware log, fault conditions, reception timing, notification permissions and threshold explanations remain accessible.

Apple's guidance on [alerts](https://developer.apple.com/design/human-interface-guidelines/alerts) supports direct messages without explanations that repeat the controls. Its [gauges guidance](https://developer.apple.com/design/human-interface-guidelines/gauges) reinforces preserving a readable value within its represented range. The user's E36 cluster and OBC photographs remain the physical references.

## Acceptance criteria

- A warning, reader discovery or error cannot change a dial's frame.
- Changing pages or dismissing the connection sheet preserves orientation, instrument positions and the current capture.
- Fallas, Sesiones and Ajustes remain selected when tapped again. Only one destination appears selected; pages have no close button, floating card or dimmed dashboard backdrop.
- Page scroll position, a selected session and unsaved settings survive switching tabs. Connection dismissal returns to the current page.
- The main face contains no firmware log or instructions. Link timing belongs to the connection sheet and the quiet landscape footer.
- All five sensor channels and their units remain available in both orientations.
- Landscape intake and recording indicators fit within the bottom control bar; there is no separate OBC banner above it.
- Controls retain at least a 44 × 44 pt target; maximum Dynamic Type remains usable in scrollable pages and the connection sheet.
- Original samples, alerts, fault text and CSV export retain their existing behavior.
- Review simulator captures in portrait, landscape, with warnings, and across page/sheet navigation. Layout tests supplement visual review.

## Vehicle overview — September 9

The next weakness was the app's overall hierarchy: it opened like a diagnostic tool, with every screen sharing the same instrument texture. The supplied BMW and Tesla examples suggest a more personal starting point, a strong vehicle image, and a clear distinction between ownership information and driving instruments.

**Auto** presents the user's Samoablau four-door E36, one observed connection state and three recent readings. DME diagnostics and recorded journeys remain accessible in the fixed dock. It does not invent remote vehicle controls, health scores, or a successful diagnosis before the DME has been read. Starting En vivo opens **Instrumentos**. Switching either way preserves the same capture; the overview itself sends no ECU command.

The dashboard retains the BMW scales and layout. A barely visible recessed face provides depth without chrome bezels. Only the needles animate between received values, over 0.28 seconds with no overshoot; numeric values and stored samples remain exact. Reduce Motion disables those transitions. Satin black surfaces, ivory primary controls, restrained amber accents, and ordinary readable secondary text distinguish the app shell from the physical instruments.

Landscape places the car and telemetry side by side. Warnings stay in the lower bar. Portrait puts the car above the telemetry rail and keeps the main capture action in a fixed dock. DME records use plain text and a fine amber rule; session charts retain their existing surfaces and interactions.

### Scene-led revision — September 11

The first vehicle overview still gave its large E36 heading and repeated navigation rows the same prominence as the car. The rounded telemetry card made the scene feel like an illustration inserted into a utility screen. The revision gives the car a wider stage, a compact **316i / E36 / 1994** identity and a Samoablau finish label. Fine rules, restrained monospace captions and ivory typography connect the overview to the precision of the original instruments without redrawing them.

The overview removes the duplicate Fallas/Sesiones destinations. Three exact readings form an open telemetry rail; connection and capture state sit underneath. A reserved portrait warning slot prevents alerts from resizing the composition. Large text can reflow telemetry into a vertical, scrollable layout. In landscape, identity and finish controls sit at the edges of the scene, leaving more height for the actual car.

The **360°** control expands the exterior within the dashboard bay. Front, profile and rear presets supplement the existing orbit, zoom and reset gestures. The fixed En vivo/Detener and navigation controls remain accessible, as do capture status and warnings. Landscape moves camera presets to a side column. Camera pose lives in the root UI, surviving tab and orientation changes; expanding or closing the exterior never starts, stops or polls acquisition.

Secondary pages use the same fine dividers and restrained typography. The DME's unqueried state remains explicit. Session rows now lead with day/month, time, duration and counts; complete dates remain available to VoiceOver. Graphs, exports, threshold values and all commands are unchanged.

The revision deliberately leaves `CockpitLayout`, `InstrumentDial`, `OBCDisplay`, the shared instrument palette, the entire acquisition stack, and the car's model/shaders unchanged. There is no idle scene animation or new recurring timer.

### Consistent navigation — September 11

The floating inspectors mixed permanent tab selection with temporary-overlay affordances: rounded cards, an X and a dimmed dashboard. They also changed shape between portrait and landscape without gaining real sheet gestures. Fallas, Sesiones and Ajustes now occupy the whole content bay on the same matte background as the app. Portrait stacks the title above the content; landscape places the title beside it, preserving height for records and controls. Neither presentation has a card boundary or close button.

The dock stays in place. Selecting a destination again keeps it open; Auto and Instrumentos return to the dashboard, and their selection marks disappear while another page is active. Destinations mount on first use and retain their state afterward, including session detail, scroll position and unsaved thresholds. Moving the portrait annunciator into the dashboard bay makes page geometry independent of the last dashboard surface while preserving the instruments' available size and position.

Connection is a focused utility presented with SwiftUI's native sheet: system drag indicator, medium/large detents, a close control and the system's landscape adaptation. Swiping it away or closing it returns to the same selected page. This presentation owns no navigation selection and sends no connection or capture command when opened or dismissed. CSV export retains the existing native share sheet.

At accessibility text sizes, threshold labels and their complete value/unit move onto separate lines. The landscape page heading becomes shorter so the content remains scrollable. Pages have explicit accessibility containers and heading traits. [Before/after](Design/navigation-comparison.jpg) · [Three destinations](Design/navigation-pages.jpg) · [Native connection sheet](Design/connection-portrait.jpg).

### Vehicle model and lighting

The overview renders the actual USDZ geometry through RealityKit's `RealityRenderer` in a Metal view. The traced early kidney outline is retained; the erroneous extra 16.7-degree mounting pitch is removed in the source geometry. Its original hood, nose carrier and upper bumper seams are preserved exactly. Grille depth follows the existing panel, with narrow recessed mounting returns closing the aperture gaps. The earlier whole-carrier deformation is removed; the traced grille outline and object rotations remain unchanged. The M bumper contains hollow ducts tessellated from the owner's STEP model at its original dimensions, recessed into their seats, and a rounded lower return matching the softer edge in the photograph. The retained wheel casting remains an approximation of the reference.

The runtime evaluates diffuse, specular, clearcoat and glass from one live HDR environment, retaining geometry-baked ambient visibility in vertex alpha. A verified 90° equirectangular conversion aligns RealityKit with the native Blender scene and its ground shadow. The older baked RGB illumination is no longer sampled, avoiding uneven vertex shading. Glass uses smooth world-space normals, Fresnel reflection and two-pass current-frame Snell refraction through the fluted headlamp lens.

The lamp material pass corrects a separate transparency-order defect: the rectangular cover previously hid much of the circular lens shading. The optical shells now render in a defined order, with refraction evaluated on the front shell and opaque bodywork still respected. Zoned glass ribs, molded lens rims and a prismatic amber return give the headlamps and indicators internal detail without changing paint or vehicle geometry. [Optical comparison](Design/headlamp-comparison.jpg) · [close-up in the app](Design/headlamp-closeup.jpg).

The Samoablau pigment follows ICC-converted samples from three low-glare panels in the owner's RAW photograph. Reflective hood/fender samples are evaluated separately. Paint parameters and annotated sampling regions are retained with the asset; they are inferred rendering parameters, not a measured paint formula.

The subsequent material review addressed washed-out body colour and weak reflections in the app. Environment intensity is half a stop lower, while the runtime paint uses metallic 0.50, roughness 0.22 and clearcoat roughness 0.055. The imported pigment, geometry and environment orientation remain intact. Three alternatives were compared at identical front, profile and rear cameras; the selected balance keeps readable shaded panels and clearer sky/tree reflections without making the body uniformly dark. These are visual PBR adjustments, not measurements of the physical coating. [Before and after in the app](Design/paint-lighting-comparison.jpg).

The rear badge is lower and inset from the trunk seam. The lower charcoal finish is limited to the central rectangular insert; the corner returns stay blue. The original black rubbing strip remains separate. The exhaust body is raised behind the apron. The portable exporter gives the rear insert a material boundary matching the native shader mask.

A transparent ambient shadow is derived from the car onto an eight-metre plane, with its outer edge feathered to zero opacity. It remains fixed in world space as the camera moves. The app car is actual geometry; the shadow contains no car pixels. Fixed illumination requires rebaking if the environment changes.

The [Blender scene](Design/Vehicle/E36-316i.blend) retains its full offline materials and separate HD previews. Native ray-traced glass and indirect lighting are richer than the mobile PBR approximation; an HD Blender render is not evidence of the app's appearance. Runtime quality is reviewed in actual app screenshots.

One-finger horizontal dragging orbits, pinching changes distance, two-finger dragging changes elevation, and double tapping restores the camera. VoiceOver offers 30-degree adjustment and reset. Vertical single-finger gestures remain available to scroll the overview. Camera pose survives orientation and tab changes without accessing acquisition, Bluetooth or SQLite.

The model and precompiled environment load asynchronously and are cached. The Metal view submits frames for camera/layout changes and a bounded initial shader warm-up, then stops drawing. The scene renders to an HDR half-float target with four-sample coverage antialiasing and up to 1.5× spatial supersampling, capped at a 2560-pixel long edge. A final Metal pass resolves radiance and applies the AgX Medium High Contrast display transform. GPU events synchronize both stages before presentation. There is no acquisition-driven render loop. Backgrounding disables rendering; the capture manager retains its own lifecycle.

[Native Blender, GLB and USDZ files](Design/Vehicle/) and [HD previews](Design/Vehicle/HD/) are retained separately. Source attribution, regeneration instructions and reconstruction limits are in [CREDITS.md](Design/Vehicle/CREDITS.md) and the [asset README](Design/Vehicle/README.md).

### Simulator review

[Overview](Design/preview.jpg) · [Vehicle in portrait](Design/overview-portrait.jpg) · [Vehicle in landscape](Design/overview-landscape.jpg) · [Expanded exterior](Design/exterior-landscape.jpg) · [Session archive](Design/sessions-portrait.jpg) · [Instrument panel](Design/instruments-portrait.jpg)

These are captures of the real app in its labeled demonstration mode. Interaction tests rotate and reset the vehicle, exercise the exterior presets, start a capture, switch Auto/Instrumentos and orientation, then verify that each flow produced one session. Separate captures review maximum accessibility text with readable units and the archive in both orientations.

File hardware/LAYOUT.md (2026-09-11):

# Front-end K-Line E36 — placa

> **Superada por `onboard/`** (2026-09-11): la placa única con el ESP32-S3-WROOM-1, el buck
> discreto y la ficha OBD2 montada está en [`onboard/README.md`](onboard/README.md). Este
> documento describe el front-end anterior, que dejaba el MCU afuera. Ojo: en aquel netlist el
> TVS D1 quedó con el ánodo a +12 V; en la placa nueva la banda va a +12 V.

**DRC limpio: 0 violaciones, 0 desconectados** (KiCad 10.0.5). Placa en
`kline-frontend.kicad_pcb`, generada por `gen_board.py` desde el netlist.
Queda 1 aviso menor: la serigrafía de J1 toca el borde.

Netlist: `kline-esp32.net`. Once componentes, once redes, todas conectadas.

## La decisión de arquitectura

**El ESP32 no va en la placa.** La placa es el front-end del lado del auto y
termina en `J2`, un conector de 7 vías. El MCU cuelga de ahí por cable.

Esto no es un rodeo para evitar medir el zócalo. Es dónde va el límite:

- La función del lado del auto — ficha, protección, transceptor — **no cambia
  nunca**. El MCU sí: podés pasar de S3 a clásico, a un Pico, o Espressif revisa
  la placa y mueve los pines. La PCB no se rehace por ninguna de esas cosas.
- El conector OBD2 está abajo del tablero, rodeado de chapa. **Pésimo lugar para
  WiFi.** Con el MCU en un cable lo ponés donde haya señal, no donde haya ficha.
- La placa queda chica. Puede llegar a entrar en la carcasa del ELM327.

Usá conector **con traba** — JST-XH o similar. Dupont suelto en un auto se sale
con la vibración.

### J2 — salida al MCU

| pin | red | dirección |
|---|---|---|
| 1 | GND | — |
| 2 | +5V | placa → MCU (alimentación) |
| 3 | **K_RX** | placa → MCU |
| 4 | **+3V3** | MCU → placa (alimenta V<sub>CC</sub> del L9637D) |
| 5 | **K_TX** | MCU → placa |
| 6 | V_SENSE | placa → MCU (ADC) |
| 7 | GND | retorno |

**Los pines 3, 4 y 5 cambiaron respecto de la primera versión.** El orden viejo
era +3V3 / K_TX / K_RX. Con el ruteo real, ese orden obligaba a que K_RX cruzara
sobre las otras dos: en U1 sale más abajo que TX y VCC, pero tenía que llegar al
pin de J2 más arriba. Reordenando, las tres quedan monótonas y salen **rectas y
paralelas** desde U1 hasta J2, sin un solo cruce.

Los 3,3 V vienen **del regulador del ESP32**. El L9637D consume 1,4 mA típicos,
así que sobra, y evita poner un LDO propio.

## Anchos de pista

Placa de **80 × 50 mm**. Con 60 × 40 el ruteo quedaba estrangulado y el DRC
tiraba 80 violaciones; ampliarla fue más barato que pelear cada holgura.

| red | ancho | por qué |
|---|---|---|
| GND, VBAT_FUSED, +5V | 0,8 mm | Camino de potencia hacia el MCU |
| K_LINE | 0,5 mm | Poca corriente, pero viene de afuera |
| K_TX, K_RX, V_SENSE, +3V3 | 0,3 mm | Señal |

Dos capas. Plano de masa entero en la inferior, sin cortarlo con pistas.

## Colocación

```
  [J1 OBD2] ─ [F1] ─┬─ [C2] [D1] ─┬─ [J3 buck] ─┐
                    │             │             │
                    └─ K_LINE ─ [R1] ─ [U1] ────┴─ [J2 → MCU]
                                       [C1]
```

**Orden desde la ficha:** OBD2 → fusible → bulk y TVS → recién ahí se ramifica.
Nada aguas arriba del fusible salvo la pista de entrada.

**U1 cerca de J1**, no de J2. La pista que conviene corta es K_LINE, que es la
que trae el ruido del auto.

**C1 a menos de 5 mm del pin 3 de U1**, con vía propia a masa. Es la regla que
más se rompe.

## Checklist antes de fabricar

- [ ] Footprint del L9637D verificado: SO-8, paso 1,27 mm
- [ ] **Pin 1 de U1 marcado en la serigrafía.** El pinout no es simétrico:
      girado 180° pone V<sub>S</sub> — los 12 V del auto — donde va RX. Se lleva
      puesto el chip y lo que esté colgado de J2
- [ ] Serigrafía con los números de pin del OBD2 al lado de J1
- [ ] Serigrafía con la tabla de J2 en la placa, para no contarla con multímetro
      dentro de un año
- [ ] Polaridad de C2 y de D1 marcadas

Ya no hay nada que medir del ESP32.

## Cambios que impuso el ruteo

**F1 pasó a fusible SMD 1206.** El portafusible de cuchilla ATO ocupaba media
placa y bloqueaba los canales. Si querés fusible reemplazable a mano, va
**en línea sobre el cable** de entrada, antes de la ficha.

**Dos saltos a la capa inferior**, cosidos con vías:

- **K_LINE** pasa por debajo de la bajada de 12 V. Es el único cruce
  inevitable: los 12 V tienen que bajar del canal superior al inferior, y la
  línea K tiene que ir de izquierda a derecha.
- **+3V3 → C1** salta por debajo de K_RX. C1 va sobre el lado derecho de U1,
  que es donde está el pin 3.

**Las vías de masa son solo cuatro**, para los pads SMD (D1, U1, R3, C1). Los
pasantes — J1, J2, J3, C2 — ya llegan al plano inferior por su propio agujero.

## Reproducirlo

```
PY=/Volumes/KiCad/KiCad/KiCad.app/Contents/Frameworks/\
   Python.framework/Versions/3.9/bin/python3
$PY hardware/gen_board.py
kicad-cli pcb drc --severity-error hardware/kline-frontend.kicad_pcb
```

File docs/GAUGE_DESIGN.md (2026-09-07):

# Gauge design — building instrument-grade readouts for the E36 dashboard

A build guide, not an essay. Every snippet here was executed, rendered in Chrome and
inspected before it went into this file; the maths was checked numerically. Where a
number is quoted (overshoot in rpm, settle time in frames) it was measured, not
estimated.

Scope: vanilla JS, inline SVG, no libraries, no CDN, works offline. Everything below
drops into `e36obd/static/dashboard.html` alongside the existing `lineChart()` and
follows the same conventions — template-literal SVG strings assigned via `innerHTML`,
CSS custom properties for colour, `1 Hz` polling.

Labelling matches `PROTOCOL_NOTES.md` and `DASHBOARD_RESEARCH.md`: **CONFIRMED**
(verified here by execution/measurement, or a primary source), **LIKELY** (one decent
source or a strong inference), **UNKNOWN** (a guess — do not act on it as fact).

---

## 0. The one-paragraph version

A gauge looks serious when its geometry is derived rather than nudged, when it shows
restraint about colour, and when it never claims more than it knows. Three things do
most of the work: (1) a single angle convention that makes `transform="rotate()"` a
literal translation of the value→angle map, so no sign errors are possible;
(2) critically damped needle motion, which by construction cannot oscillate and — as
measured in §3.4 — never displays a value the sensor did not report; (3) knowing which
channels want a pointer and which want a number. Your rpm wants a dial. Your battery
voltage does not, and §4.1 explains why forcing it into one produces a gauge that is
40% warning zone.

---

## 1. The geometry core

### 1.1 Angle convention — pick one and never think about it again

**Degrees, measured clockwise from 12 o'clock.**

```
    0° = up (12:00)      90° = right (3:00)
  180° = down (6:00)    270° = left (9:00)
```

This is the right choice for one specific reason: SVG's y axis grows *downward*, so
screen-clockwise is the positive rotation direction. That makes this convention agree
with SVG's own `rotate()` **and** with arc `sweep-flag=1`. Draw a needle pointing
straight up, and `transform="rotate(θ 100 100)"` aims it at exactly θ in your
convention. No sign flips, no offset constants, nowhere for an error to hide.

Converting to the frame `Math.cos`/`Math.sin` want is a single subtraction:

```js
// screen-clockwise-from-12  ->  standard math frame
const a = (deg - 90) * Math.PI / 180;
x = cx + r * Math.cos(a);
y = cy + r * Math.sin(a);
```

Verify it once and move on — **CONFIRMED** by execution, with `cx=cy=100, r=50`:

| deg | x | y | reads as |
|----:|--:|--:|---|
| 0 | 100 | 50 | up |
| 90 | 150 | 100 | right |
| 180 | 100 | 150 | down |
| 270 | 50 | 100 | left |

**Sweep conventions.** A 270° sweep starting at 225° (7:30, lower-left) ends at
225+270 = 495° ≡ 135° (4:30, lower-right) — symmetric about vertical, with the gap
centred at the bottom. That is the classic full-size tachometer layout and it is what
you want for rpm. A 250° sweep starting at 235° also lands symmetrically (235+250 =
485 ≡ 125°) and gives more room for two- and three-digit numerals; use it for
temperature and anything with wide labels.

The real E36 cluster tachometer sweeps somewhat less than 270° — by inspection of
cluster photographs it is roughly 240–250°, needle at rest near 8 o'clock —
**UNKNOWN** as an exact figure, I could not find a BMW spec for it. It is a parameter;
set `sweep` to taste. Note also that a 270° sweep is *not* a period-correct E36
detail, it is the generic instrument convention. Both look right.

### 1.2 The three helpers

```js
const R2 = n => Math.round(n * 100) / 100;                 // keeps path data short
const clamp = (v, lo, hi) => v < lo ? lo : v > hi ? hi : v;

/* Polar -> cartesian. deg is clockwise from 12 o'clock. */
function pol(cx, cy, r, deg) {
  const a = (deg - 90) * Math.PI / 180;
  return [cx + r * Math.cos(a), cy + r * Math.sin(a)];
}

/* Arc from a0 to a1 at radius r. Because our angles run clockwise and SVG's
   sweep-flag=1 also means clockwise, the flag is simply "is a1 after a0". */
function arcPath(cx, cy, r, a0, a1) {
  const [x0, y0] = pol(cx, cy, r, a0), [x1, y1] = pol(cx, cy, r, a1);
  const large = Math.abs(a1 - a0) > 180 ? 1 : 0;
  const sweep = a1 >= a0 ? 1 : 0;
  return `M${R2(x0)} ${R2(y0)} A${R2(r)} ${R2(r)} 0 ${large} ${sweep} ${R2(x1)} ${R2(y1)}`;
}

/* Tick values anchored to a NICE grid (multiples of step), not to min.
   Anchoring to min gives you ticks at -30,-10,10,... which look like a mistake. */
function ticksFor(min, max, step) {
  const out = [];
  if (!(step > 0)) return out;
  for (let k = Math.ceil(min / step - 1e-9); k <= Math.floor(max / step + 1e-9); k++)
    out.push(k * step);
  return out;
}
```

The `1e-9` slop in `ticksFor` is load-bearing. Without it `ticksFor(0, 1, 0.1)` drops
the final tick to floating-point error. With it you get 11 ticks — **CONFIRMED**.

A 270° arc cannot be drawn as a single `A` command if it is a full 360° (start and end
coincide and nothing renders). Anything up to ~355° is fine; you will never approach
that on an instrument.

### 1.3 Choosing a scale — the step everyone skips

**The display range is not the sensor range.** This is the single highest-leverage
decision on a gauge face, and getting it wrong cannot be rescued by any amount of
styling.

Three rules:

1. **Show the band that carries meaning.** Your coolant sensor resolves −30 to 130 °C.
   A coolant gauge that starts at −30 spends a quarter of its sweep on temperatures
   the car will never see, compressing the 80–110 °C band where every decision
   actually lives. Start it at 20.
2. **A warning zone wider than ~25% of the sweep means the scale is wrong** — or the
   channel does not want a dial at all. §4.1 works this through for battery voltage.
3. **Pick ranges that divide evenly by `majorStep`.** `ticksFor` anchors to nice
   multiples, so a range of 40–130 with `majorStep: 10` gives ticks at both ends;
   a range of −30–130 gives you a first tick at −20 and a bare arc before it.

Verified tick counts for the ranges recommended in §9 — **CONFIRMED**:

| range | majorStep | ticks | first/last |
|---|---:|---:|---|
| 0–7000 | 1000 | 8 | 0 / 7000 |
| 40–130 | 10 | 10 | 40 / 130 |
| 10–16 | 1 | 7 | 10 / 16 |
| 0–20 | 5 | 5 | 0 / 20 |

### 1.4 `gauge()`

Returns a complete `<svg>` string. Radii are expressed in a fixed 200×200 viewBox so
every constant is legible and the whole thing scales with one `size` parameter.

```js
function gauge(cfg) {
  const c = Object.assign({
    min: 0, max: 100, value: null, majorStep: 20, minorStep: 5,
    startAngle: 225, sweep: 270, label: '', note: '', unit: '', dec: 0,
    zones: [], numFmt: v => String(v), size: 190,
  }, cfg);

  const CX = 100, CY = 100;
  //  zone band ── 92   (outboard, clear of everything)
  //  tick rail ── 86   (ticks grow INWARD from here)
  //  minor tip ── 80
  //  major tip ── 74
  //  numerals  ── 63
  const R_ZONE = 92, W_ZONE = 5.5, R_RAIL = 86, R_MAJ = 74, R_MIN = 80, R_NUM = 63;

  const span = c.max - c.min;
  const ang = v => c.startAngle + (clamp(v, c.min, c.max) - c.min) / span * c.sweep;
  const end = c.startAngle + c.sweep;
  const hot = v => c.zones.some(z => z.hot && v >= z.from - 1e-9 && v <= z.to + 1e-9);
  const inZone = c.value == null ? null
    : c.zones.find(z => c.value >= z.from - 1e-9 && c.value <= z.to + 1e-9);
  const liveCol = inZone ? inZone.color : 'var(--series-1)';

  let s = '';
  // bezel: one hairline ring. That is the entire skeuomorphism budget.
  s += `<circle cx="${CX}" cy="${CY}" r="97" fill="none"
          stroke="var(--border-lit)" stroke-width="1"/>`;

  // warning zones — dim until the needle is actually inside one
  for (const z of c.zones) {
    const live = c.value != null && c.value >= z.from && c.value <= z.to;
    s += `<path class="g-zone" d="${arcPath(CX, CY, R_ZONE, ang(z.from), ang(z.to))}"
            stroke="${z.color}" stroke-width="${W_ZONE}" opacity="${live ? 1 : .3}"/>`;
  }

  // tick rail
  s += `<path class="g-rail" d="${arcPath(CX, CY, R_RAIL, c.startAngle, end)}"/>`;

  // minor ticks, skipping any that coincide with a major
  const majors = ticksFor(c.min, c.max, c.majorStep);
  const isMajor = new Set(majors.map(v => v.toFixed(6)));
  for (const v of ticksFor(c.min, c.max, c.minorStep)) {
    if (isMajor.has(v.toFixed(6))) continue;
    const a = ang(v);
    const [x0, y0] = pol(CX, CY, R_RAIL, a), [x1, y1] = pol(CX, CY, R_MIN, a);
    s += `<line class="g-tick-min${hot(v) ? ' hot' : ''}"
            x1="${R2(x0)}" y1="${R2(y0)}" x2="${R2(x1)}" y2="${R2(y1)}"/>`;
  }

  // major ticks + numerals
  for (const v of majors) {
    const a = ang(v);
    const [x0, y0] = pol(CX, CY, R_RAIL, a), [x1, y1] = pol(CX, CY, R_MAJ, a);
    const [nx, ny] = pol(CX, CY, R_NUM, a);
    const h = hot(v) ? ' hot' : '';
    s += `<line class="g-tick-maj${h}" x1="${R2(x0)}" y1="${R2(y0)}" x2="${R2(x1)}" y2="${R2(y1)}"/>`
       + `<text class="g-num${h}" x="${R2(nx)}" y="${R2(ny)}" dy="0.34em"
            text-anchor="middle">${c.numFmt(v)}</text>`;
  }

  // a SHORT note may live inside the dial (e.g. "×1000"). A long label may not — §1.4b
  if (c.note) s += `<text class="g-label" x="${CX}" y="82" text-anchor="middle">${c.note}</text>`;

  // needle: drawn pointing UP, aimed purely by rotate()
  const a0 = c.value == null ? c.startAngle : ang(c.value);
  s += `<g class="g-needle-g" transform="rotate(${R2(a0)} ${CX} ${CY})"`
     + `${c.value == null ? ' style="display:none"' : ''}>`
     + `<path class="g-needle" d="M100 20 L102.5 100 L101.7 117 L98.3 117 L97.5 100 Z"
          style="fill:${liveCol}"/></g>`
     + `<circle class="g-hub-o" cx="${CX}" cy="${CY}" r="8.5" style="stroke:${liveCol}"/>`
     + `<circle class="g-hub-i" cx="${CX}" cy="${CY}" r="3"/>`;

  // digital co-readout, in the gap at the bottom of the sweep
  const txt = c.value == null ? '—' : c.value.toFixed(c.dec);
  s += `<text class="g-val" x="${CX}" y="138" text-anchor="middle"
          style="fill:${liveCol}">${txt}</text>`
     + `<text class="g-unit" x="${CX}" y="153" text-anchor="middle">${c.unit}</text>`;

  return `<svg viewBox="0 0 200 200" width="${c.size}" height="${c.size}"
    role="img" aria-label="${c.label} ${txt} ${c.unit}">${s}</svg>`;
}
```

**The needle.** `M100 20 L102.5 100 L101.7 117 L98.3 117 L97.5 100 Z` — a pointed tip
at radius 80, widest (±2.5) exactly at the pivot, tapering to a ±1.7 counterweight
tail 17 units behind it. The counterweight is what stops it looking like an arrow
clipped to a circle; real pointers are balanced about their pivot and the tail is the
visual evidence of that. The hub is two circles — a panel-coloured disc with a lit
ring, then a small solid centre — which covers the needle root and gives the pivot a
physical reading.

**Needle tip radius vs tick radius.** The tip lands at radius 80, exactly at the inner
end of the minor ticks. A needle that stops short of the ticks looks lost; one that
overlaps the numerals looks careless. Land it on the minor-tick line.

#### 1.4b Long labels do not go inside the dial — **CONFIRMED by rendering**

With numerals at radius 63, the numerals near the top of the sweep sit at
y ≈ 60–70 — precisely where a centred title wants to be. A first pass put
`label` at y=66 and the words `REFRIGERANTE` and `BATERÍA` collided with the numerals
`80 / 90` and `13` respectively.

The fix is not to move the text, it is to **put the channel name outside the dial**,
in the panel cell header. That is also what production dashes do, it lets the label be
as long as it needs, and it creates the horizontal alignment grid that §7 depends on.
Only a short note — `×1000`, `°C` — may sit inside, at y≈82 (18 units above the hub,
well inside the numeral ring). `gauge()` therefore takes `note`, and `label` is used
only for the accessible name.

### 1.5 The CSS

Sizes and colours live here, not in the markup, so a whole panel can be re-weighted in
one place.

```css
.g-num   { fill: var(--text-secondary); font-family: var(--mono); font-size: 12px;
           font-variant-numeric: tabular-nums; letter-spacing: .02em }
.g-num.hot { fill: var(--critical) }
.g-label { fill: var(--text-muted); font-family: var(--mono); font-size: 8.5px;
           letter-spacing: .22em; text-transform: uppercase }
.g-val   { fill: var(--text-primary); font-family: var(--mono); font-size: 26px;
           font-weight: 500; font-variant-numeric: tabular-nums; letter-spacing: .01em }
.g-unit  { fill: var(--text-muted); font-family: var(--mono); font-size: 9px;
           letter-spacing: .18em }
.g-tick-min { stroke: var(--text-muted);    stroke-width: 1 }
.g-tick-maj { stroke: var(--text-secondary); stroke-width: 2.4 }
.g-tick-maj.hot, .g-tick-min.hot { stroke: var(--critical) }
.g-rail  { stroke: var(--text-muted); stroke-width: 1; fill: none; opacity: .55 }
.g-needle{ fill: var(--series-1) }
.g-hub-o { fill: var(--surface-1); stroke: var(--series-1); stroke-width: 1.6 }
.g-hub-i { fill: var(--series-1) }
.g-zone  { fill: none; stroke-linecap: butt }

/* bloom belongs on the needle only — see §7 */
.lit .g-needle { filter: drop-shadow(0 0 4px rgba(224,82,26,.55)) }
/* stale data dims the whole instrument, not just the value */
.stale svg { opacity: .32 }
```

> **Trap — SVG presentation attributes lose to CSS.** `<text class="g-val" font-size="14">`
> renders at **26px**, not 14px, because `font-size` as an XML attribute is a
> presentation attribute and any CSS rule outranks it. This bit the first draft in
> three places. For a one-off size override use `style="font-size:14px"` (inline style
> wins) or add a modifier class. **CONFIRMED** by rendering.

The major:minor tick ratio is **2.4 : 1 in stroke weight and 12 : 6 in length**. Both
differences are needed — length alone is too weak a signal at small sizes, weight
alone reads as a rendering artefact.

---

## 2. Warning zones

A zone is an arc segment at radius 92, outboard of the tick rail with 6 units of black
between them, `stroke-linecap="butt"` so the ends are square and land exactly on their
threshold values.

```js
zones: [{ from: 6000, to: 7000, color: 'var(--critical)', hot: true }]
```

**Making it read at a glance without shouting** comes down to three decisions, and the
third is the one that matters:

1. **Put it outboard, not under the needle.** A band behind the pointer competes with
   it. Outside the ticks it is peripheral — you see it without looking at it.
2. **Keep it thin.** 5.5 units against a 92-unit radius. It is a margin annotation, not
   a region of the dial.
3. **Render it at `opacity: .3` until the needle is inside it, then 1.0.** A redline
   that is permanently at full strength is decoration; the eye tunes it out within
   seconds and it has no headroom left for when it matters. Dim it, and the transition
   to full opacity is itself the alarm.

The `hot: true` flag additionally recolours the **ticks and numerals inside the zone**
to `--critical`. This is the cheapest legibility win on the whole face: the scale
itself tells you where the limit is, so the band is confirming information rather than
carrying it alone. Real tachometers print the redline numerals in red for the same
reason.

Finally, when the needle enters a zone the needle, hub ring and digital readout all
adopt the zone colour (`liveCol` above). One state change, three coordinated signals,
no ambiguity about which channel is complaining.

---

## 3. Needle animation

### 3.1 The problem, stated honestly

Samples arrive at 1 Hz. Snapping the needle 60 times a minute is unreadable. But any
smooth motion between samples is **displaying values that were never measured** — that
is what interpolation is, and no amount of cleverness avoids it.

So the question is not "how do I avoid inventing data" (you cannot) but "what class of
lie am I willing to tell". There are two, and they are not equally acceptable on a
diagnostic tool:

- **Lag** — the needle shows a value the sensor reported slightly in the past. Benign.
  Every mechanical gauge ever built does this.
- **Overshoot** — the needle shows a value the sensor *never reported at all*, past
  the target, because the animation carries momentum. On a tachometer this can put the
  needle into the redline during a blip that never actually reached it. **This is not
  acceptable**, and it is exactly what spring/bounce easing — the default in most
  animation libraries — produces.

Never use an easing curve with overshoot (`easeOutBack`, `spring` with damping < 1,
`cubic-bezier` with a control point outside [0,1]) on a measurement.

### 3.2 The three candidates

| solver | order | overshoot | corner at sample | notes |
|---|---|---|---|---|
| linear interpolation over the sample interval | — | none | yes, visible | needle arrives exactly as the next sample lands; constant velocity looks mechanical (this is what stepper-motor clusters do) |
| exponential smoothing `x += (t−x)(1−e^(−dt/τ))` | 1st | **provably zero** | yes, in velocity | one line, never arrives exactly, feels soft |
| **critically damped spring** | 2nd | see §3.4 | none | smooth in position *and* velocity; the boundary case that cannot oscillate |

Critical damping (ζ = 1) is the right default: it is the fastest second-order approach
that does not oscillate, and it is what a real pointer with a properly specified damper
does. Underdamped oscillates (lies). Overdamped is just slow.

### 3.3 The exact step — do not integrate this numerically

With the target constant across a frame, the error `e = x − target` obeys
`ë + 2ωė + ω²e = 0`, whose critically damped solution is closed-form:

```
  A = e₀                     B = v₀ + ω·e₀
  e(t) = (A + B·t)·e^(−ωt)
  ė(t) = (B − ω(A + B·t))·e^(−ωt)
```

Which is six lines of JS and is **exact for any dt** — no stiffness, no explosion when
a background tab hands you a 5-second frame:

```js
/* Critically damped step. smoothTime T is the ~time to converge; omega = 2/T. */
function smoothStep(x, v, target, dt, T) {
  const w = 2 / T;
  const E = Math.exp(-w * dt);
  const e0 = x - target;
  const B  = v + w * e0;
  return [target + (e0 + B * dt) * E,
          (B - w * (e0 + B * dt)) * E];
}
```

Because it is the analytic solution and not an integrator, one 0.5 s step gives
bit-identical results to five hundred 1 ms steps — **CONFIRMED** (agreement to 1e-6 in
position, 1e-5 in velocity). Unity's `Mathf.SmoothDamp` is the same formulation with a
polynomial approximation to `e^(−x)` that you do not need in JS.
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

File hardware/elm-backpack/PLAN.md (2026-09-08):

# Inline ELM327 ECU adapter — revision E

Make a black printed enclosure for the user's loose buck converter and ESP32-S3, alongside the existing ELM BT shell. Keep the BMW-and-stripes detail; remove the broad, strapped-over desktop-box proportions. Preserve direct soldering and USB pointing away from the OBD plug.

The revised body is **162 × 48 × 30.4 mm**: boards end-to-end, mounting below the electronics, screws from underneath, uninterrupted long cover. Relative to D, width falls 41.5%, length increases 52 mm, footprint area falls 13.8%, and height stays unchanged. This trades width for a longer tail that needs available vehicle space and a suitable support.

This is a dimensioned first-fit prototype. No physical measurements have been provided. The ELM and electronics remain marked **FIT CHECK REQUIRED**. The old `hardware/case.py` targets a different custom PCB and is not reused.

## Measurements and evidence

All dimensions are millimetres. Retrieved 2026-09-07.

| Item | Evidence | Revision E design value | Confidence / action |
|---|---|---|---|
| Buck family | Blue board, barrel jack, two screw terminals, 330 inductor, two electrolytics, USB-C in the supplied photos. [DROK's related board](https://www.droking.com/power-supply-module-dc-9v-36v-to-5.2v-5a-double-output-buck-converter-usb-charger-voltage-regulator-adapter-driver-module) specifies 63 × 27 × 10. [USB-C seller](https://www.didacticaselectronicas.com/shop/buck-usbc-5a-fuente-de-alimentacion-step-down-12-24v-a-5v-usb-tipo-c-46849) gives 63 × 27 × 10 but incorrectly labels the units cm. | PCB 63.5 × 27.5 × 1.6; 18 above PCB; 3 below PCB for solder | Family match, not proof of the exact revision. Measure the PCB, capacitor height, and underside before printing the full base. |
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

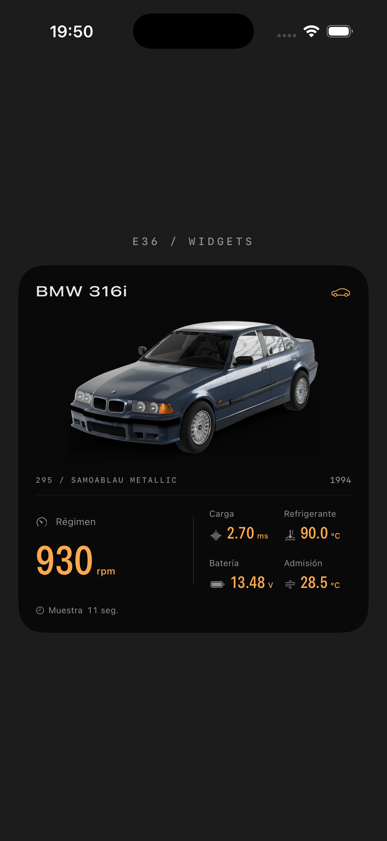
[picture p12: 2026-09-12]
ios/Design/Widgets/large-garage.png

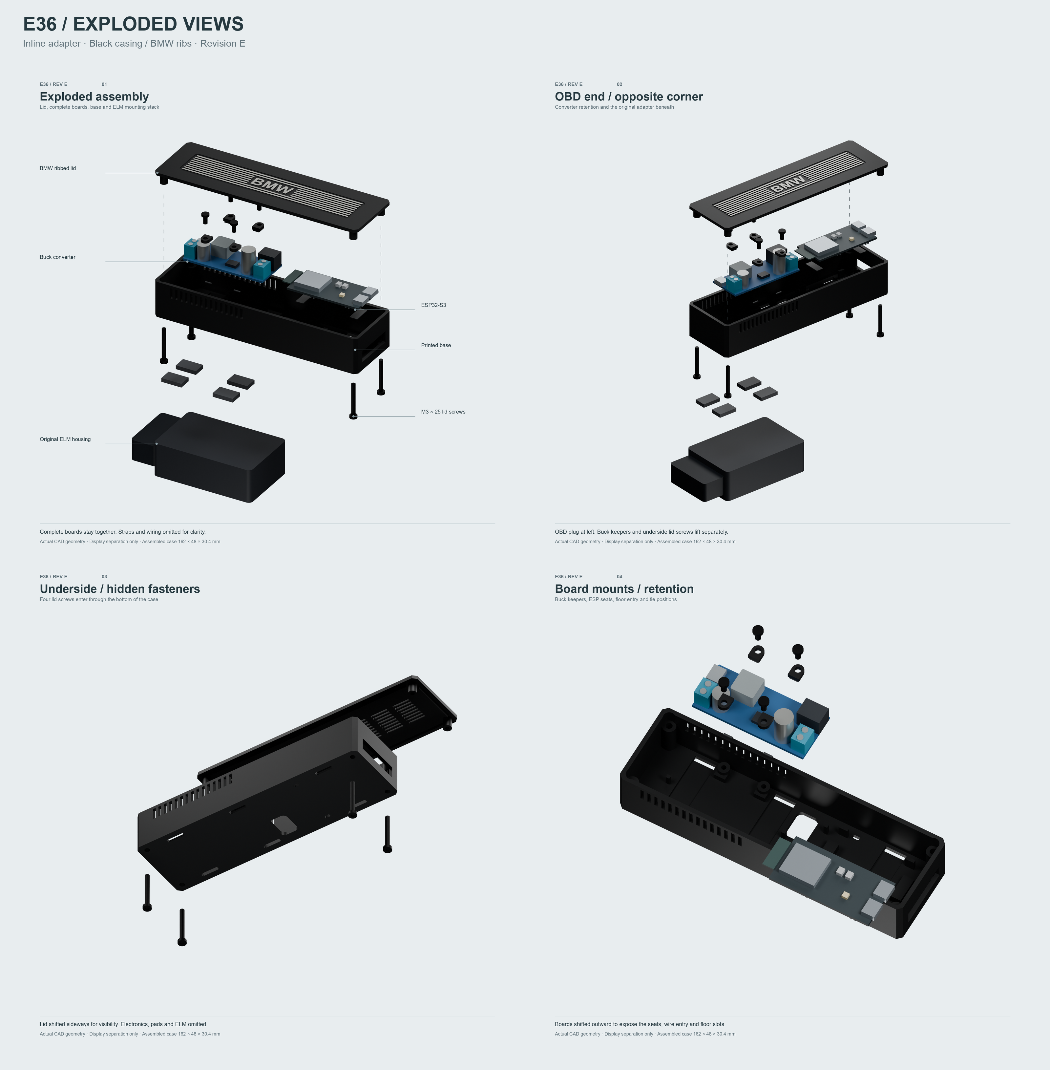
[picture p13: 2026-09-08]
hardware/elm-backpack/exports/exploded-views/all-views.png

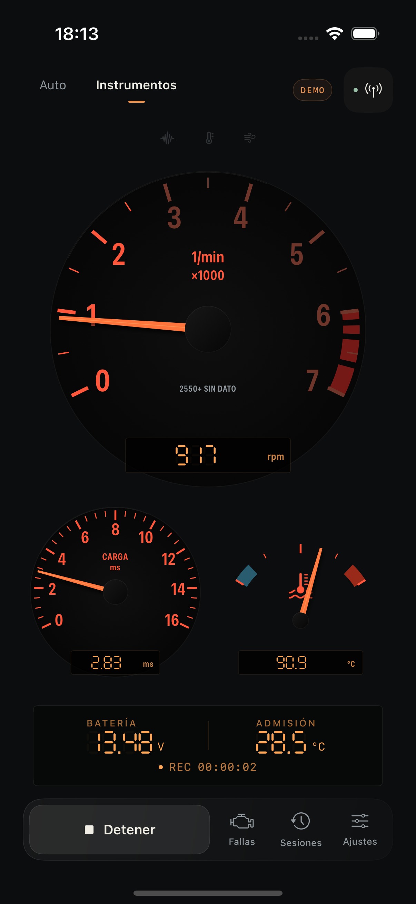
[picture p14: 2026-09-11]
ios/Design/instruments-portrait.jpg

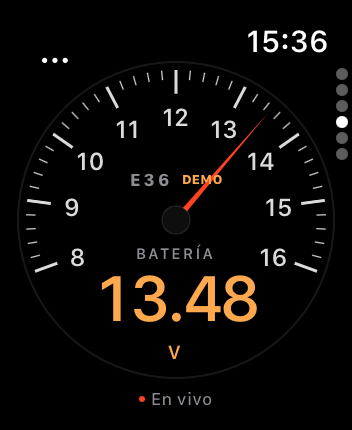
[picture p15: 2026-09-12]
ios/Design/Companion/41-battery-normal.png

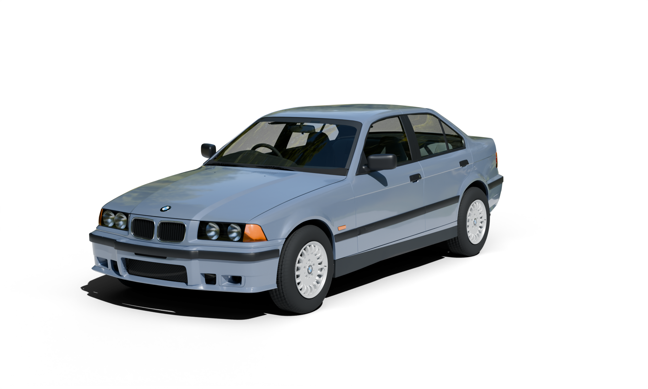
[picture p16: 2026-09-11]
ios/Design/Vehicle/AppLighting/front.png

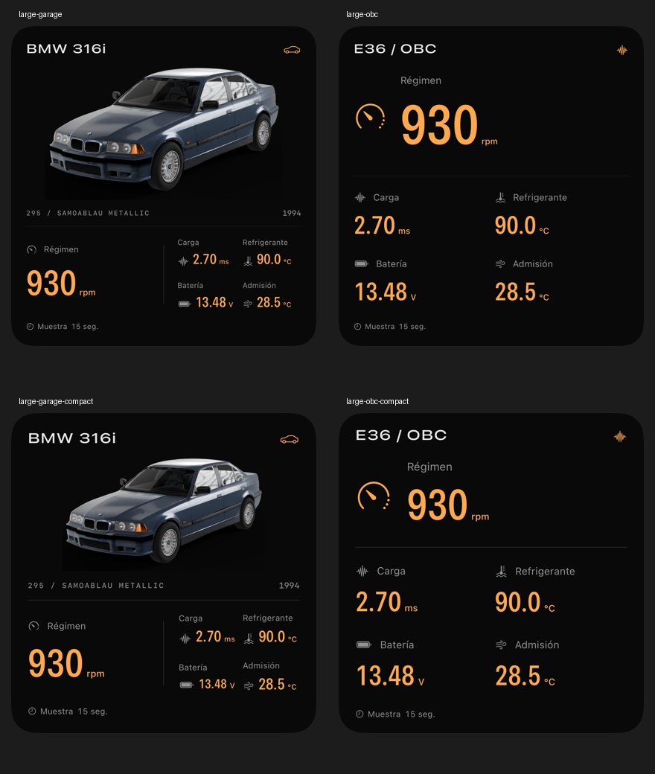
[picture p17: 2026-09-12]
ios/Design/Widgets/large-review-sheet.jpg

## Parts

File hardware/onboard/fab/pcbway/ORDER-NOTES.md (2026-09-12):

# PCBWay — pedido de 1 muestra ensamblada (borrador, 2026-09-11)

Placa: **E36 K-line reader rev B**, `hardware/onboard`. Subir `e36-kline-onboard-gerbers.zip` en el
formulario de PCB y, en el paso de ensamblado, `bom-pcbway.csv`, `pnp-pcbway.csv` y
`assembly-drawing-top.pdf`. Todo en este directorio (y en `pcbway-sample-order.zip`).

## Formulario PCB (pcbway.com/QuickOrderOnline.aspx)

| Campo | Valor |
|---|---|
| Board type | Single pieces |
| Size | 90 × 50 mm |
| Quantity | 5 (mínimo práctico; se ensambla 1) |
| Layers | 2 |
| Material | FR-4, TG 150 |
| Thickness | 1.6 mm |
| Min track / spacing | 6/6 mil (la placa usa 0,15 mm mínimos) |
| Min hole size | 0.3 mm |
| Solder mask | Green |
| Silkscreen | White |
| Surface finish | HASL lead-free (ENIG si se quiere mejor plano para el módulo) |
| Via process | Tenting vias |
| Finished copper | 1 oz |
| Remove product No. | Yes |
| Impedance control | No |

## Formulario de ensamblado

| Campo | Valor |
|---|---|
| Assembly quantity | **1** (o 2 para tener repuesto: el setup es igual) |
| Assembly side | Top only |
| Unique parts | 30 |
| SMD parts | 36 |
| THT parts | 2 (J1 conector OBD2, J4 JST XH) |
| BGA/QFN | 0 |
| Parts sourcing | Turnkey: PCBWay compra todo. Alternativa: J1 consignado (ver notas) |
| Sensitive components | Sí: módulo Wi-Fi U3 (no tocar la antena con fixtures) |
| Function test | No; solo inspección visual/AOI |
| Conformal coating | No |

## Notas para "Your instructions" (copiar y pegar)

```
Single assembled sample of a 2-layer automotive diagnostics reader. All SMD on top; two THT parts (J1, J4).
1. J1 is a J1962 OBD2 male right-angle PCB plug (Macchina CCBDM20 or equivalent): 16 pins, 4.00 mm pitch,
   two rows 3.00 mm apart, rows at 2.25 mm and 5.25 mm behind the flange, body overhangs the board edge.
   PLEASE check your connector against the footprint (holes 1.3 mm) before soldering; if it does not match,
   contact us before proceeding. Alternatively we can consign the connector.
2. U3 (ESP32-S3-WROOM-1-N16R8): must be the N16R8 variant (octal PSRAM). Keep the antenna end free of fixture contact.
3. Polarised parts: D1 (TVS) cathode band to pad 1 (+12 V rail); D2/D3 cathode to pad 1; LED1/LED2 cathode pad 1;
   U1 and U2 pin 1 as per silkscreen dot.
4. J2 (1x6 header) is DNP. Mounting holes H1-H4 stay empty.
5. Use the pick-and-place file coordinates (origin bottom-left, mm); rotations are KiCad convention, please
   confirm orientation from the assembly drawing for U1, U2, U3, D1-D3 and LEDs.
6. Lead-free process. No wash residue on the USB-C receptacle.
```

## Precio oficial (motor de cotización de PCBWay, ver `quote-official.md`)

PCB 5 pcs **6,50 USD** · ensamblado 1 placa **88,00 USD** (tarifa plana, igual para 2 o 5) · envío a Argentina
FedEx 48,87 / DHL 72,73 USD. Los componentes los cotizan a mano tras revisar el BOM: estimar 15–25 USD para una
muestra. Total esperado ≈ 160–170 USD con FedEx.

## Archivos

- `e36-kline-onboard-gerbers.zip` — gerbers + taladros (KiCad 10, extensiones Protel).
- `bom-pcbway.csv` — BOM en columnas PCBWay, con fabricante y MPN por línea y el código LCSC como pista.
- `pnp-pcbway.csv` — centroides, origen esquina inferior izquierda, mm, incluye J1/J4.
- `assembly-drawing-top.pdf/.png` — referencias y contornos (F.Fab + serigrafía).
- `board-render-top.png`, `schematic.png`, `top-layer-plot.png` — para el revisor.
- `OBD2_footprint.kicad_mod` — el footprint de J1, por si necesitan las cotas.

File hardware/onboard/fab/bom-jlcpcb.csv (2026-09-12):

Comment | Designator | Footprint | LCSC Part # | MPN | Nota
OBD2-M-90 | J1 | OBD2_Male_RightAngle_16P | C9900166046 (JLC TH) verificar | CCBDM20 / J1962 male 90deg PCB | paso 4.0, filas 3.0
1A 32V | F1 | Fuse_1206_3216Metric | C183160 | S1206-S-1.0A (Sart) | fusible 1206 (extendido)
SMBJ24A | D1 | D_SMB | C123819 | SMBJ24A | TVS unidireccional, catodo (banda) a +12V
SS34 | D2,D3 | D_SMA | C8678 | SS34 | OR de entrada 12V -> VIN
510R 0.75W | R1 | R_2010_5025Metric | C175041 | CR2010F510RE04Z | pull-up K a VS, 0,3 W pico
L9637D | U1 | SOIC-8_3.9x4.9mm_P1.27mm | C153038 | E-L9637D013TR | transceptor ISO9141 (ST, ECOPACK)
100n | C1,C3,C13,C6 | C_0603_1608Metric | C14663 | 0603 100nF 50V X7R | desacople VCC U1
100k | R2 | R_0603_1608Metric | C25803 | 0603 100k 1% | divisor V_SENSE, rama alta
22k | R3 | R_0603_1608Metric | C31850 | 0603 22k 1% | divisor V_SENSE, rama baja
AP63203 | U2 | TSOT-23-6 | C780769 | AP63203WU-7 | buck 3.3V 2A, 3.8-32V
10u 50V | C10,C11 | C_1210_3225Metric | C53084458 | CC1210X7R50V106MN | CIN
100n 50V | C12 | C_0603_1608Metric | C14663 | 0603 100nF 50V | CIN hf
4.7uH 3.3A | L1 | L_Sunlord_SWPA6045S | C78804 | SWPA6045S4R7MT | inductor buck
22u 10V | C14,C15 | C_0805_2012Metric | C45783 | 0805 22uF 10V X5R | COUT
USB-C 16P | J3 | USB_C_Receptacle_HRO_TYPE-C-31-M-12 | C165948 | TYPE-C-31-M-12 | programacion / banco
5k1 | R5,R6 | R_0603_1608Metric | C23186 | 0603 5.1k | CC1 pull-down
ESP32-S3-WROOM-1-N16R8 | U3 | ESP32-S3-WROOM-1 | C2913202 | ESP32-S3-WROOM-1-N16R8 | antena sobre la placa, zona sin cobre
10u | C5 | C_0805_2012Metric | C15850 | 0805 10uF 10V | desacople 3V3 modulo
10k | R4,R9 | R_0603_1608Metric | C25804 | 0603 10k | pull-up EN
1u | C7 | C_0603_1608Metric | C15849 | 0603 1uF 10V | RC de EN
RESET | SW1 | SW_SPST_PTS645Sx43SMTR92 | C318884 | TS-1187A-B-A-B / PTS645 | reset (EN a GND)
BOOT | SW2 | SW_SPST_PTS645Sx43SMTR92 | C318884 | TS-1187A-B-A-B / PTS645 | IO0 a GND
PWR blanco | LED1 | LED_0603_1608Metric | C2290 | KT-0603W | 3V3 presente (blanco: el unico 0603 basico junto al rojo)
2k2 | R7 | R_0603_1608Metric | C4190 | 0603 2.2k | LED1
STATUS rojo | LED2 | LED_0603_1608Metric | C2286 | KT-0603R | IO38
1k | R8 | R_0603_1608Metric | C21190 | 0603 1k | LED2
36k | R10 | R_0603_1608Metric | C23147 | 0603WAF3602T5E | UVLO buck, rama alta (Eq.1 AP63203) (extendido)
3k74 | R11 | R_0603_1608Metric | C23016 | 0603WAF3741T5E | UVLO buck, rama baja: ON 12,5 V / OFF 11,5 V (extendido)
4k7 | R12 | R_0603_1608Metric | C23162 | 0603 4.7k | VBUS fuerza EN: en el banco arranca igual
PIGTAIL | J4 | JST_XH_B3B-XH-A_1x03_P2.50mm_Vertical | C144394 | B3B-XH-A(LF)(SN) | cola al redondo de 20: 1 GND(19) 2 K(15+17+20) 3 +12(16 KL15 o 14 KL30)

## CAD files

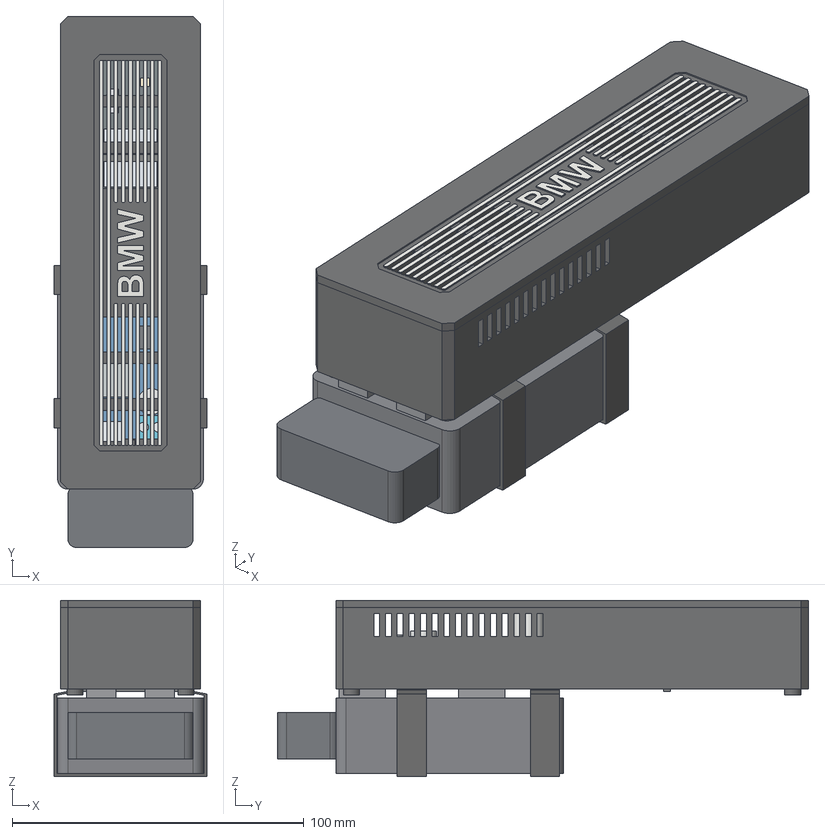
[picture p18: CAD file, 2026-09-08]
hardware/elm-backpack/exports/assembly-with-references.step
52.4 x 182.0 x 60.4 mm
base
lid
buck keeper 4 x 4
REF optional silver rib paint x 14
REF optional silver lettering paint
REF buck PCB
REF buck input DC jack
REF buck input terminal
REF terminal screw x 4
REF buck output terminal
REF buck input capacitor
REF buck output capacitor
REF buck inductor
REF buck controller
REF buck USB C
REF ESP PCB
REF ESP antenna - no tie here
REF ESP RF shield - tie here
REF ESP USB C x 2
REF ESP solder pad x 44
REF direct solder joint x 8
REF ESP button x 2
REF ESP RGB LED
REF insulating support pad x 6
REF keeper toe pad - compressed x 4
REF mounting silicone pad x 4
REF ELM shell - UNMEASURED
REF OBD plug - UNMEASURED
REF M3 x 25 underside lid screw x 4
REF M3 x 6 screw x 4
REF reusable 10 mm strap x 2
REF ESP retaining nylon tie

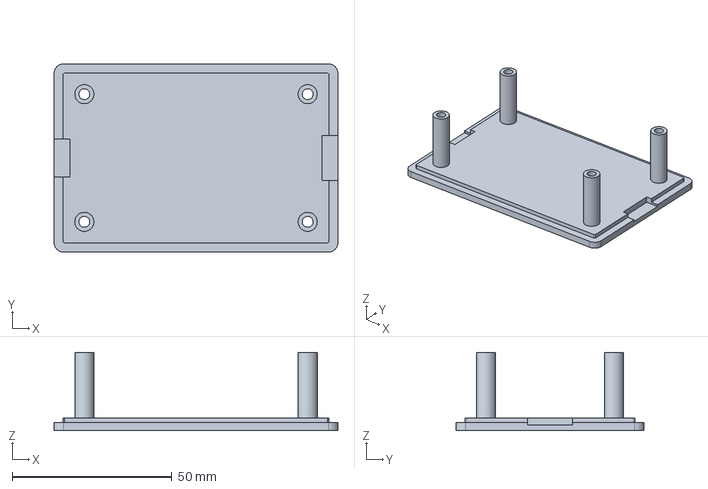
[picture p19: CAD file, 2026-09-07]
hardware/case-lid.step
89.0 x 59.0 x 24.5 mm

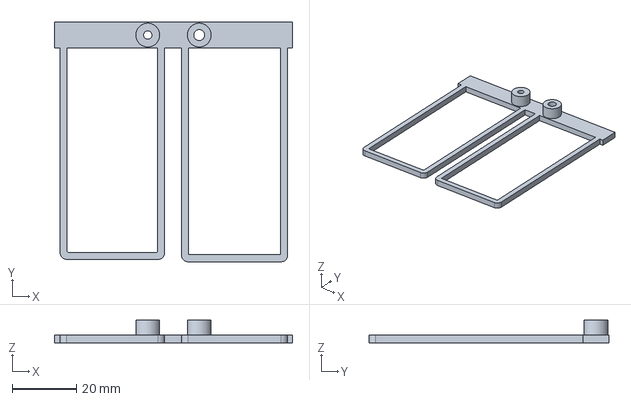
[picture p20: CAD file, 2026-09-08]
hardware/elm-backpack/exports/fit-gauge.step
74.0 x 74.5 x 7.00 mm

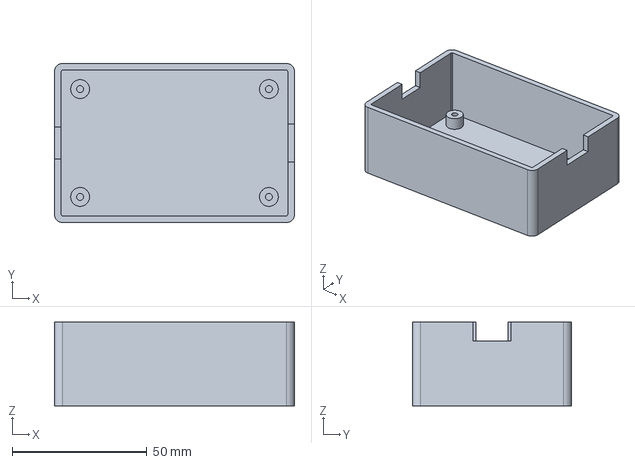
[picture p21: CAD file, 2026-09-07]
hardware/case-base.step
89.0 x 59.0 x 31.1 mm

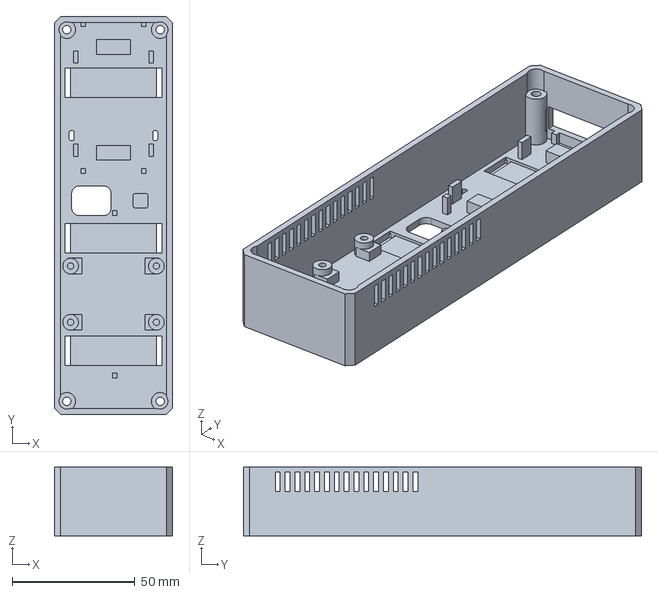
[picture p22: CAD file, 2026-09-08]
hardware/elm-backpack/exports/base.step
48.0 x 162.0 x 28.0 mm

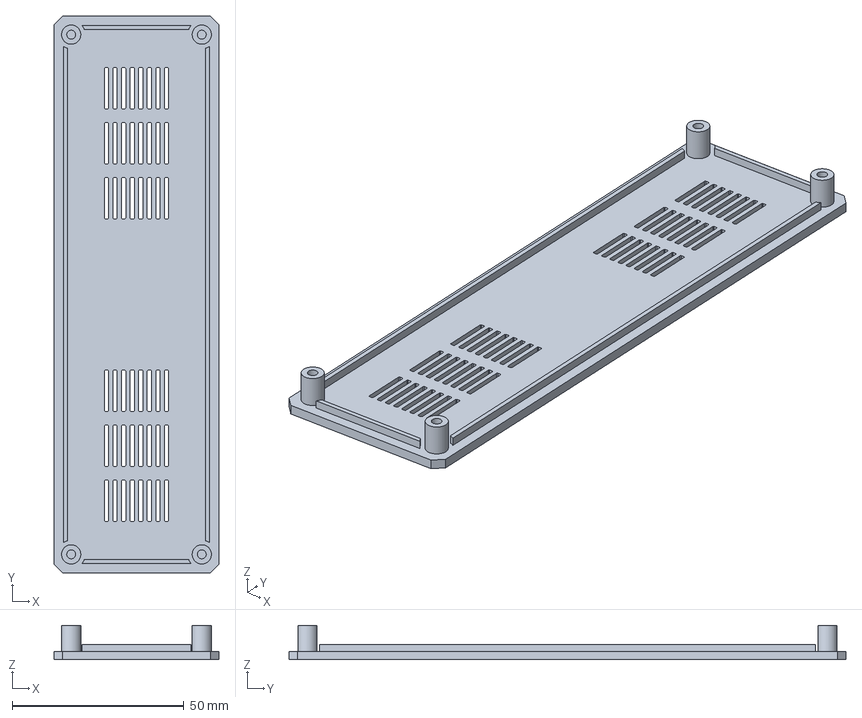
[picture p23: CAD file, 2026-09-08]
hardware/elm-backpack/exports/lid.step
48.0 x 162.0 x 9.90 mm

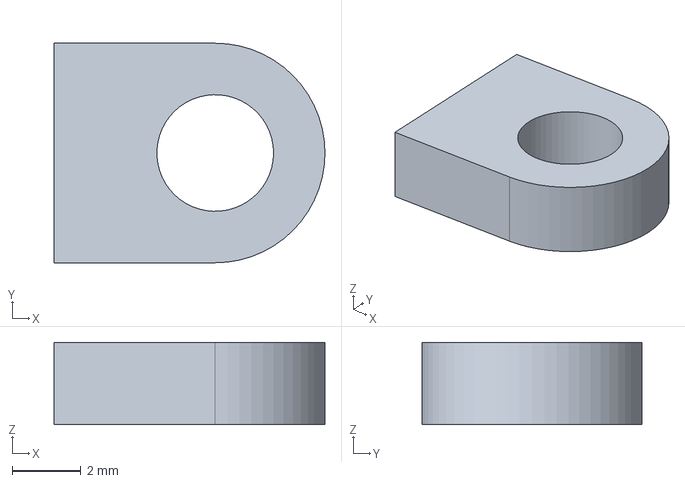
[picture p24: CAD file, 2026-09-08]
hardware/elm-backpack/exports/buck-keeper.step
7.90 x 6.40 x 2.40 mm

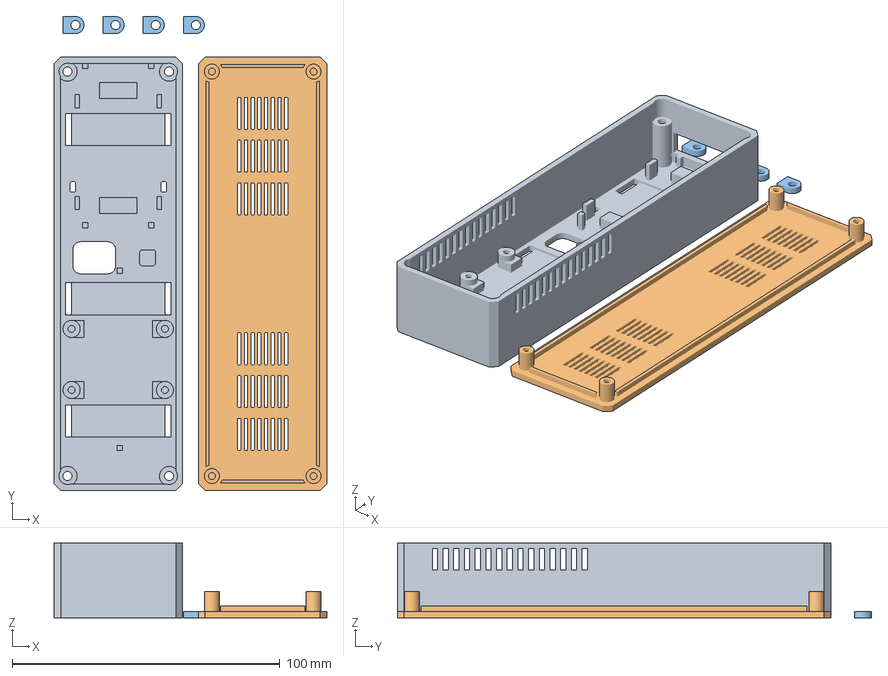
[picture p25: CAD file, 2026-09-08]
hardware/elm-backpack/exports/print-layout.3mf
102.0 x 177.2 x 28.0 mm
base
lid
buck-keeper x 4

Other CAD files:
hardware/onboard/case/assembly-pigtail.step
hardware/onboard/case/assembly.step
hardware/onboard/case/lid-pigtail.step
ios/Design/Vehicle/FogIntake.step
hardware/onboard/case/base-pigtail.step
hardware/onboard/case/lid.step
hardware/onboard/case/badge.stl
hardware/onboard/case/base.step
hardware/elm-backpack/exports/base.stl
hardware/elm-backpack/exports/buck-keeper.stl
hardware/elm-backpack/exports/fit-gauge.stl
hardware/elm-backpack/exports/lid.stl
hardware/onboard/case/base-pigtail.stl
hardware/onboard/case/base.stl
hardware/onboard/case/lid-pigtail.stl
hardware/onboard/case/lid.stl
ios/Design/Vehicle/AppLighting.blend
ios/Design/Vehicle/E36-316i.blend
ios/Design/Vehicle/ReferenceLighting.blend
ios/Design/Vehicle/WheelStudy.blend

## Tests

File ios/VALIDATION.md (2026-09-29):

# Validación de la app E36

La demo y las pruebas automáticas no validan la radio del iPhone ni el enlace contra el auto.

## Comprobaciones automáticas

Desde la raíz del repositorio:

```sh
swift test --package-path ios/Core
python3 -B -m unittest discover -s firmware/tests -v
xcodebuild -project ios/E36OBD.xcodeproj -scheme E36OBD \
  -destination 'platform=iOS Simulator,name=iPhone 16 Pro,OS=18.6' \
  -derivedDataPath ios/DerivedData CODE_SIGN_IDENTITY=- test
```

Elegir un dispositivo que aparezca en `xcrun simctl list devices available` y que Xcode muestre como elegible. Si Xcode indica que falta la plataforma de su SDK, instalarla desde **Settings → Components**, o con `xcodebuild -downloadPlatform iOS`. El esquema ahora incorpora el reloj: instalar también watchOS (`xcodebuild -downloadPlatform watchOS`). Cada target usa su SDK; no compilar todos con un `-sdk iphonesimulator` global.

Para ejecutar los targets de pruebas directamente sobre un simulador ya instalado:

```sh
python3 ios/tools/test_simulator.py --device UUID_DEL_SIMULADOR
```

El script conserva el resultado `.xcresult` y las capturas bajo `ios/TestResults/`. En Xcode 26.2, si `actool` exige el runtime 26.2 que todavía no está instalado, agregar `--without-icon`: permite comprobar el código completo y las pruebas en iOS 18.6, omitiendo exclusivamente el catálogo del ícono. Ese resultado **no valida la compilación del catálogo**. La compilación normal conserva el ícono y requiere completar los componentes de Xcode.

El script firma los productos del simulador de forma ad hoc (`CODE_SIGN_IDENTITY=-`) para que Xcode incluya los entitlements simulados del App Group. No necesita una identidad de desarrollo para el simulador. Desactivar toda la firma omite esos entitlements y hace fallar la prueba de almacenamiento compartido del widget.

Las pruebas del núcleo cubren límites de fragmentos y UTF-8, desbordamiento, formatos BLE, RAM vacía, secuenciación de comandos, restauración, alertas, transacciones, recuperación, CSV y conservación de picos/huecos en gráficos. Las pruebas de interfaz guardan capturas de las dos orientaciones y recorren grabación, fallas, avisos, reconexión, recuperación tras cierre, texto grande e historial. Los tests de firmware usan el código real con módulos de hardware sustituidos y comprueban respaldo, verificación y recuperación del actualizador con un transporte USB simulado.

La revisión del tablero incorpora comprobaciones de coordenadas: cada esfera principal debe mantener x, y, ancho y alto (tolerancia 0,5 pt) al aparecer uno o varios avisos, apagar el motor simulado, saturar la lectura, reconectar y cerrar paneles. Los controles principales deben conservar áreas de al menos 44 × 44 pt. Las capturas se revisan también visualmente: estas aserciones no detectan por sí solas jerarquía, contraste o texto incorrecto.

### Resultado local — 7 de septiembre de 2026

- **19 pruebas Swift del núcleo**, **8 pruebas Python de firmware/actualizador** y **5 pruebas XCTest** (3 unitarias y 2 recorridos de interfaz): todas aprobadas, sin pruebas omitidas.
- Xcode 26.2, simulador iPhone 16 Pro con iOS 18.6; compilación mediante `test_simulator.py --without-icon`. El código de la app y la descripción Bluetooth incluida en el producto se verificaron. El catálogo del ícono sigue pendiente del runtime 26.2 requerido por `actool`.
- Capturas revisadas en ambas orientaciones y con el máximo tamaño de texto; se corrigieron la actualización del OBC, el área táctil de las sesiones y el solapamiento del selector de demo. Se abrió la hoja de exportación con sus dos CSV.
- Un CSV de demostración conservó 32 muestras originales, 17 eventos, tres inicios de alerta y los estados `populated`/`unpopulated`.
- El iPhone 17 Pro detectado usa iOS 27.0 beta (24A5430a), con Developer Mode desactivado; no hay identidades de firma válidas en este Mac. No se instaló en ese dispositivo y su compatibilidad con Xcode 26.2 no se da por validada.
- No se detectó un ESP32 en un puerto USB. **No se modificó firmware en hardware**. Quedan pendientes todas las comprobaciones físicas de la lista siguiente, incluida la captura de 30 minutos.

### Revisión de diseño — 7 de septiembre, 23:20 ART

- Se recompiló la interfaz revisada y se repitieron las **5 pruebas XCTest**, todas aprobadas. Esta revisión conserva el núcleo de adquisición y persistencia de la validación anterior.
- Se comprobaron coordenadas estables durante avisos individuales y simultáneos, motor apagado, saturación, reconexión y cierre de paneles, además de las áreas táctiles mínimas y el contador de sesiones con texto accesible.
- Revisión visual de las capturas finales: vertical, horizontal, fallas, ajustes, temperaturas, historial y recuperación con tamaño de texto máximo. Se corrigieron la separación entre escalas y valores, el tamaño del control principal horizontal, el borde del fondo de los paneles y la etiqueta de cantidad de sesiones.
- Resultado: `ios/TestResults/20260908T021856419293Z/Tests.xcresult`. Capturas exportadas en `.context/qa/redesign-final/`. Se utilizó `--without-icon`; continúa pendiente la validación del catálogo con el runtime correspondiente.

### Ajuste al cuadro de referencia — 7 de septiembre, 23:43 ART

- Se aprobaron nuevamente las **5 pruebas XCTest** con las escalas del cuadro E36, agujas planas, centros negros, indicadores auxiliares en abanico y displays segmentados.
- Las comprobaciones de posición incluyen también la batería en horizontal. Se verifica que admisión y estado de grabación queden dentro de la altura de la barra inferior y que el tacómetro quede por encima.
- Resultado: `ios/TestResults/20260908T024152140241Z/Tests.xcresult`; capturas revisadas en `.context/qa/bmw-reference/`. La compilación utiliza el mismo `--without-icon` documentado arriba. El pequeño cambio posterior al pictograma de batería se comprueba visualmente en el simulador.

### Widget — 8 de septiembre, 00:08 ART

- **25 pruebas del núcleo** (19 existentes y 6 del widget) y **7 pruebas XCTest** (5 unitarias y 2 de interfaz), todas aprobadas. Se comprobaron la extensión embebida, el App Group real del simulador, la separación ESP32/demo, los datos ausentes o corruptos y los límites de publicación.
- Resultado: `ios/TestResults/20260908T025912280891Z/Tests.xcresult`. Compilación con firma ad hoc y `--without-icon` en iPhone 16 Pro, iOS 18.6. La firma permite comprobar el contenedor compartido; no constituye firma para un iPhone físico.
- Se encontró **Instrumento E36** en la galería del sistema, se agregó a la pantalla de inicio y se cambió su configuración. El origen ESP32 sin lecturas muestra un guion; Demostración conserva su rótulo DEMO. El menú ofrece los cinco sensores.
- Se contrastaron las lecturas del widget con las de la app y su archivo compartido: refrigerante a 112,5 °C con aviso y RPM saturadas como `2550+`. Se accionó la flecha sin abrir la app y se comprobó que la antigüedad de la muestra continúa visible. Capturas en `.context/qa/widgets/`.
- Esta comprobación verifica WidgetKit en la pantalla de inicio. **No valida CarPlay físico**, su contraste al retirar el fondo ni las actualizaciones con BLE real. El runtime iOS 26.2 seguía descargándose; la compilación del catálogo del ícono también sigue pendiente. Ver [WIDGETS.md](WIDGETS.md) para instalación y comprobaciones en el vehículo.

### Actualización física del ESP32 — 8 de septiembre, 11:09 ART

- Detectado por USB en `/dev/cu.usbmodem5C4C0875701`: ESP32-S3 con Octal-SPIRAM, MicroPython 1.29.0 del 24 de agosto. Los archivos `ble.py` y `main.py` del dispositivo coincidían con las versiones previas del repositorio.
- Se repitieron las **8 pruebas de firmware y del actualizador**, todas aprobadas. Se reemplazó únicamente `ble.py` para agregar admisión al final del mensaje `D`; no se reflasheó MicroPython ni se modificó K-line.
- Respaldo anterior: `.context/firmware-backups/20260908T140820825057Z/ble.py`. La lectura posterior del dispositivo coincide byte por byte con `firmware/mp/ble.py`; SHA-256 instalado: `0b71e5f027fb0cbfd0f4f568807d8b6941025c7db4405d792751606ec7f6a1f3`.
- Tras reiniciar, la consola confirmó `anunciando como E36-OBD` y el arranque del bucle BLE sin excepciones. Registro: `.context/esp-boot.log`; comprobación de respaldo y hashes: `verification.json` junto al respaldo. Se cerró la consola sin interrumpir el panel.
- Este resultado verifica la instalación y el arranque en hardware. No verifica una conexión BLE desde el iPhone, muestras reales del DME ni continuidad con CarPlay; esas pruebas siguen pendientes.

Para volver exactamente al BLE anterior:

```sh
python3 ios/tools/update_ble.py --restore .context/firmware-backups/20260908T140820825057Z/ble.py
```

### Instalación en el iPhone — 8 de septiembre, 11:27 ART

- **E36 OBD 1.0 (1) instalado y abierto en el iPhone 17 Pro**, conectado por USB, con iOS 27.0 beta (24A5430a). Developer Mode y los servicios de desarrollo quedaron habilitados. `devicectl` confirmó la instalación, el lanzamiento y que el proceso de la app seguía ejecutándose.
- La compilación completa para dispositivo con Xcode 26.2 (17C52) terminó correctamente. Incluye el catálogo del ícono, la descripción Bluetooth y `E36OBDWidgets.appex`; ya no se omite `Assets.xcassets`. Se verificaron las firmas de ambos bundles y su App Group en los perfiles instalados.
- Se utilizó el **Personal Team** del usuario. El App Group se registró desde Signing & Capabilities y se incluyó en ambos perfiles. El perfil de la app vence el **15 de septiembre de 2026 a las 11:23 ART**; renovar compilando y reinstalando conserva los datos. La configuración local del equipo está en `ios/Local.xcconfig`, ignorado por git.
- Producto: `.context/iphone-build/Build/Products/Debug-iphoneos/E36OBD.app`. Evidencia: `.context/iphone-final-build.log`, `.context/iphone-install-result.json`, `.context/iphone-launch-verified.json` y `.context/iphone-sideload-verification.json`.
- Esta prueba confirma instalación y arranque con la beta del teléfono. No confirma todavía recepción BLE del ESP32, consultas al DME, widgets en CarPlay físico ni captura prolongada con pantalla bloqueada.

### Diagnóstico de BLE y captura — 8 de septiembre, 11:44 ART

- El registro SQLite del iPhone confirmó descubrimiento de `E36-OBD` a −52 dBm, Bluetooth autorizado, conexión NUS y suscripción TX. La conexión inicial funcionó al omitir la opción de demora con valor cero.
- Se guardó una muestra real a las 11:38:59: **990 rpm, 3,30 ms de carga, 21,4 °C de refrigerante, 13,62 V, 19,1 °C de admisión y 440 ms de consulta**. El firmware confirmó `detenido (1 muestras)` al detener esa captura. Esto confirma recepción y almacenamiento del formato ampliado; no confirma continuidad.
- En otro intento, el firmware notificó `se corto: sin respuesta de la ECU`. La app inició recuperación, pero CoreBluetooth rechazó inmediatamente las demoras enviadas como `Double`, con `CBErrorDomain (1)`. El rechazo anterior a la demora provocaba un bucle de reintentos; la captura aportada por el usuario muestra ese bucle.
- Se reemplazó la demora por un `NSNumber` entero de segundos y se detiene la recuperación automática si iOS rechaza los parámetros, evitando el bucle inmediato. Se conserva cada etapa de descubrimiento/conexión y el dominio/código del error en el registro, usando la cola existente de almacenamiento.
- **25 pruebas del núcleo, 7 unitarias de iOS y 2 de interfaz aprobadas**. Las dos pruebas nuevas verifican opciones iniciales ausentes y demoras enteras de 1/2/5/10/30 segundos. Tras cambiar el tipo de demora se recompiló para dispositivo y se repitieron las 7 unitarias. La interfaz no cambió.
- La última compilación está instalada y su firma verificada. **La reconexión con demora entera todavía no está validada en hardware**: iOS rechazó el lanzamiento de prueba porque el teléfono estaba bloqueado. El ESP32 no aparece actualmente como puerto USB en el Mac; queda pendiente el trazado directo de K-line y una captura continua.
- Evidencia: `.context/ble-debug-live-check/`, `.context/ble-fix-simulator-tests.log`, `.context/ble-reconnect-unit-tests.xcresult`, `.context/ble-reconnect-install.json` y `.context/ble-reconnect-smoke-launch.json`.

Una compilación Debug admite una prueba de conexión BLE con demora de un segundo, sin iniciar captura ni borrar sesiones:

```sh
xcrun devicectl device process launch --device ID_DEL_IPHONE com.ignaciopardo.e36obd --ble-smoke-test
```

Usarla con la app detenida y el iPhone desbloqueado. Nunca usar `--uitesting` en el teléfono real: ese argumento borra la base local para las pruebas del simulador.

### Traza física de recuperación — 9 de septiembre, 16:18 ART

- El ESP32 volvió a estar disponible en el puerto USB detectado `cu.usbmodem5C4C0875701`. Se respaldaron `main.py`, `ble.py`, `kline.py` y `boot.py` en `.context/ble-sep09/firmware/`. Los tres primeros coinciden byte por byte con el repositorio; no se modificaron archivos del dispositivo.
- Se reinició el panel y se cargaron envoltorios de diagnóstico **solo en RAM** mediante `mpremote resume run .context/ble-sep09/trace.py`. Registran operaciones BLE, mensajes y traceback al fallar K-line. Un reinicio elimina esa instrumentación. Para observar un panel en ejecución, usar `resume`: el `mpremote` instalado hace soft reset por defecto antes de `exec`, `run` o acceso a archivos.
- **La recuperación BLE con demoras enteras funciona en el teléfono físico.** Tras cada error del DME, la consola confirmó desconexión, publicidad, reconexión, `detenido` y un nuevo intento `vivo`. Los intervalos entre el error y la siguiente sincronización BLE fueron 2,595 / 3,875 / 6,675 / 11,555 / 31,716 segundos: corresponden al backoff 1/2/5/10/30 más el establecimiento del enlace. Después continuó usando aproximadamente 30 segundos; no apareció el bucle inmediato de la captura anterior.
- Los **nueve errores** recogidos hasta este corte son `sin respuesta de la ECU` en `kline.init`, esperando el primer byte con `_rx(500)` en la línea 142. No llegó siquiera el sincronismo `0x55`: estos intentos fallaron antes de identificación, sensores o memoria de fallas. No hubo muestras ni códigos en este tramo. La conexión física al vehículo y su estado de contacto todavía deben confirmarse; esta evidencia no permite atribuir el fallo a cableado, alimentación o temporización.
- La última imagen aportada coincide con el registro antiguo del **8 de septiembre a las 11:39:50**. El registro extraído hoy conserva esos eventos históricos; no demuestra que el bucle inmediato continúe en la compilación actual.
- El iPhone estuvo disponible al inicio y ejecutó la app, pero después dejó de estar disponible para `devicectl`. La captura por USB del ESP32 continúa de forma independiente. Evidencia: `.context/ble-sep09/serial-trace.log`, `.context/ble-sep09/capture-summary.json`, `.context/ble-sep09-phone-before/` y `.context/ble-sep09-devices-current.json`.
- Se confirma recuperación del transporte BLE. **La captura continua de datos reales y la lectura completa de fallas siguen pendientes** de una ECU que responda.

### Contacto en posición 2 y prueba directa — 9 de septiembre, 16:29 ART

- El usuario confirmó contacto en **posición 2, motor apagado**. La lectura de fallas transmitida por BLE recibió `error: sin respuesta de la ECU` y luego la ayuda completa hasta `?  esta ayuda`. Esto confirma físicamente la finalización mediante ayuda, incluso cuando el DME no responde; no es una memoria sin fallas.
- Se pausó BLE y se ejecutó `.context/ble-sep09/direct_kline.py` directamente por USB, después de soft reset, sin otro hilo consultando la ECU. GPIO17 alto/bajo/alto produjo cinco lecturas consecutivas de GPIO18 **1/0/1**, respectivamente: el eco local TX/RX funciona.
- La conexión directa a DME `0x10` falló esperando el sincronismo inicial. Un segundo intento con **2.000 ms** para la primera respuesta, en lugar de 500 ms, tampoco recibió ningún byte. La captura está en `.context/ble-sep09/direct-kline.log`. Se restauró el timeout, se dejó TX alto y se reinició el firmware normal; no se grabaron cambios en sus archivos.
- Se reanudó la traza BLE en `.context/ble-sep09/serial-trace-after-probe.log`. Otra lectura de fallas terminó con el mismo error de ECU y la ayuda completa. El usuario confirmó posteriormente que el cableado del ESP es correcto; la investigación continúa sobre el inicio de sesión, sin atribuir el fallo al cableado.
- Se corrigió la interfaz: un error de lectura ya **no muestra el checkmark ni “0 registros”**. La demo incorpora `DME sin respuesta` para reproducir errores de apertura, interrupción en vivo y lectura de fallas. La prueba de interfaz verifica error visible, botón nuevamente habilitado y ausencia del resultado exitoso.
- **7 pruebas unitarias y 3 de interfaz aprobadas**, incluida la nueva regresión. Resultado: `ios/TestResults/20260909T192550028418Z/Tests.xcresult`; captura revisada en `.context/ble-sep09/qa/79902710-76D1-4495-BE15-FF2B18D5941A.png`.
- La app completa para iPhone compiló y pasó la verificación de firma. **Esta corrección visual todavía no está instalada:** tanto `devicectl` como `idevicescreenshot` dejaron de encontrar el iPhone. El usuario autorizó capturas remotas; se necesita volver a conectar el teléfono al Mac para realizarlas y actualizar la app.

### Temporización y recepción UART — 9 de septiembre, 16:35 ART

- Pruebas exclusivas por USB, sin BLE ni otro hilo de adquisición, cargadas solo en RAM. Se comparó el inicio original con dos intentos omitiendo el vaciado de RX posterior a crear el UART. Los tres fallaron antes del primer byte. No hubo bytes descartados por ese vaciado.
- La secuencia GPIO para `0x10` se reflejó correctamente en RX en cada cambio, también después de reutilizar el UART. Los intervalos medidos fueron aproximadamente **200,05–200,08 ms**. Crear el UART llevó **0,858–0,913 ms**; estos intentos no respaldan las hipótesis de pérdida de control del pin ni de un vaciado tardío de la respuesta.
- El UART a 9600 baudios transmitió un byte `0x55` y recibió exactamente su eco. Tras **10 segundos de reposo**, se observó RX durante dos segundos después del wake-up: **cero cambios de nivel y ningún byte**. Se repitió sin crear el UART, con el mismo resultado. Los mayores intervalos entre observaciones fueron 31 y 27 µs, respectivamente. Esto describe la señal observada en GPIO18; no determina por sí solo la causa de la falta de respuesta del DME.
- Evidencia y scripts reproducibles: `.context/ble-sep09/uart-probe.log`, `uart_probe.py`, `rx-probe.log` y `rx_probe.py`. Se reinició el panel normal, se verificó la publicidad y se restauró la traza en `serial-trace-after-uart-probes.log`. **No se modificaron archivos del ESP.**
- Se solicitó apagar el contacto durante diez segundos y volver a posición 2, con el motor apagado, para comprobar si cambia el estado de la sesión del DME. Esa prueba necesita confirmación del usuario antes de ejecutarse. La captura continua sigue sin estar validada.

### Actualización del iPhone — 9 de septiembre, 16:40 ART

- El iPhone 17 Pro volvió a estar accesible mediante CoreDevice por red local. Se respaldó la base antes de actualizar en `.context/ble-sep09-phone-reconnected/`. La firma completa del producto volvió a verificarse.
- **La corrección de la lectura fallida de fallas quedó instalada y abierta en el teléfono.** `devicectl` confirmó instalación y lanzamiento del nuevo bundle; se verificaron los procesos de la app y su widget. Evidencia: `.context/ble-sep09/iphone-fault-fix-install.json`, `iphone-fault-fix-launch.json` e `iphone-processes-after-update.json`.
- La copia posterior en `.context/ble-sep09-phone-after-update/` conserva las **seis sesiones y la única muestra original**. Los eventos pasaron de 17.561 a 17.583. No se utilizaron argumentos que borraran datos ni se desinstaló la app.
- Otra lectura física de fallas completó `error: sin respuesta de la ECU` seguido de la ayuda hasta `?  esta ayuda`. La traza del ESP vuelve a situar el fallo antes del primer byte de sincronismo. La actualización corrige la presentación del error; no resuelve ni valida la captura continua.
- No se obtuvo una captura remota del teléfono: `idevicescreenshot` no pudo abrir la conexión, la alternativa DVT agotó su espera y Xcode mostraba `Take Screenshot` deshabilitado. La comprobación visual de esta corrección sigue siendo la del simulador; instalación, lanzamiento y conservación de datos sí se verificaron en el dispositivo.
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

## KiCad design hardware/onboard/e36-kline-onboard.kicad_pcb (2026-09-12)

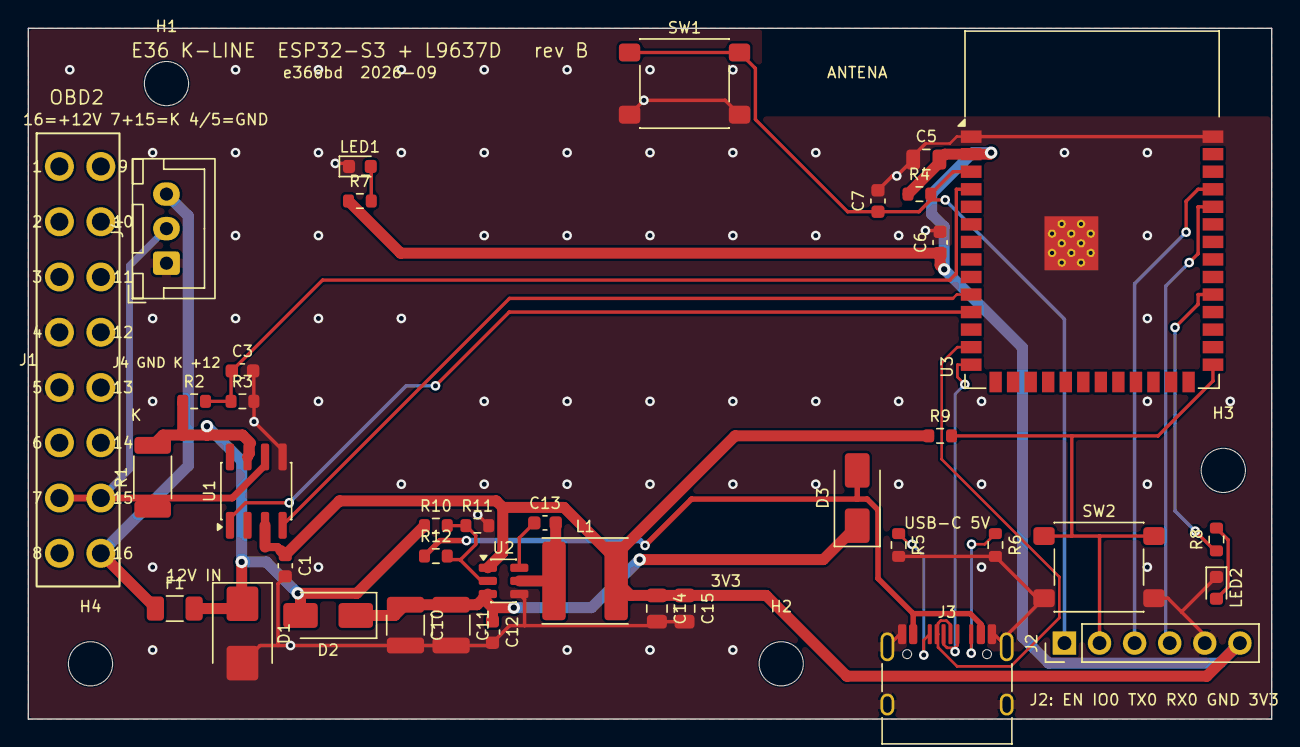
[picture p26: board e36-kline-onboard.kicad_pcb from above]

Board: 2 copper layers, 90.0 x 50.0 mm, 43 parts (0 on the bottom side), 24 nets.

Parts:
C1, C3, C6, C13: 100n; C_0603_1608Metric
C5: 10u; C_0805_2012Metric
C7: 1u; C_0603_1608Metric
C10, C11: 10u 50V; C_1210_3225Metric
C12: 100n 50V; C_0603_1608Metric
C14, C15: 22u 10V; C_0805_2012Metric
D1: SMBJ24A; D_SMB
D2, D3: SS34; D_SMA
F1: 1A 32V; Fuse_1206_3216Metric
H1, H2, H3, H4: M3; MountingHole_3.2mm_M3
J1: OBD2-M-90; OBD2_Male_RightAngle_16P
J2: DEBUG; PinHeader_1x06_P2.54mm_Vertical
J3: USB-C 16P; USB_C_Receptacle_HRO_TYPE-C-31-M-12
J4: PIGTAIL; JST_XH_B3B-XH-A_1x03_P2.50mm_Vertical
L1: 4.7uH 3.3A; L_Sunlord_SWPA6045S
LED1: PWR blanco; LED_0603_1608Metric
LED2: STATUS rojo; LED_0603_1608Metric
R1: 510R 0.75W; R_2010_5025Metric
R2: 100k; R_0603_1608Metric
R3: 22k; R_0603_1608Metric
R4, R9: 10k; R_0603_1608Metric
R5, R6: 5k1; R_0603_1608Metric
R7: 2k2; R_0603_1608Metric
R8: 1k; R_0603_1608Metric
R10: 36k; R_0603_1608Metric
R11: 3k74; R_0603_1608Metric
R12: 4k7; R_0603_1608Metric
SW1: RESET; SW_SPST_PTS645Sx43SMTR92
SW2: BOOT; SW_SPST_PTS645Sx43SMTR92
U1: L9637D; SOIC-8_3.9x4.9mm_P1.27mm
U2: AP63203; TSOT-23-6
U3: ESP32-S3-WROOM-1-N16R8; ESP32-S3-WROOM-1

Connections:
+3V3: C1.1, C5.2, C6.1, C14.1, C15.1, J2.6, L1.2, R4.1, R7.1, R9.1, U1.3, U2.1, U3.2
BST: C13.1, U2.6
CC1: J3.A5, R5.1
CC2: J3.B5, R6.1
EN: C7.1, J2.1, R4.2, SW1.1, U3.3
EN_BUCK: R10.2, R11.1, R12.2, U2.2
GND: C1.2, C3.2, C5.1, C6.2, C7.2, C10.2, C11.2, C12.2, C14.2, C15.2, D1.2, J1.4, J1.5, J2.5, J3.A1, J3.A12, J3.SH, J4.1, LED1.1, LED2.1, R3.2, R5.2, R6.2, R11.2, SW1.2, SW2.2, U1.5, U2.4, U3.1, U3.40, U3.41
IO0: J2.2, R9.2, SW2.1, U3.27
IO38: R8.1, U3.31
K_LINE: J1.7, J1.15, J4.2, R1.1, U1.6
K_RX: U1.1, U3.11
K_TX: U1.4, U3.10
LED1_A: LED1.2, R7.2
LED2_A: LED2.2, R8.2
RXD0: J2.4, U3.36
SW: C13.2, L1.1, U2.5
TXD0: J2.3, U3.37
USB_DN: J3.A7, J3.B7, U3.13
USB_DP: J3.A6, J3.B6, U3.14
VBAT_F: D1.1, D2.2, F1.2, R1.2, R2.1, R10.1, U1.7
VBAT_RAW: F1.1, J1.16, J4.3
VBUS: D3.2, J3.A4, J3.A9, R12.1
VIN: C10.1, C11.1, C12.1, D2.1, D3.1, U2.3
V_SENSE: C3.1, R2.2, R3.1, U3.4

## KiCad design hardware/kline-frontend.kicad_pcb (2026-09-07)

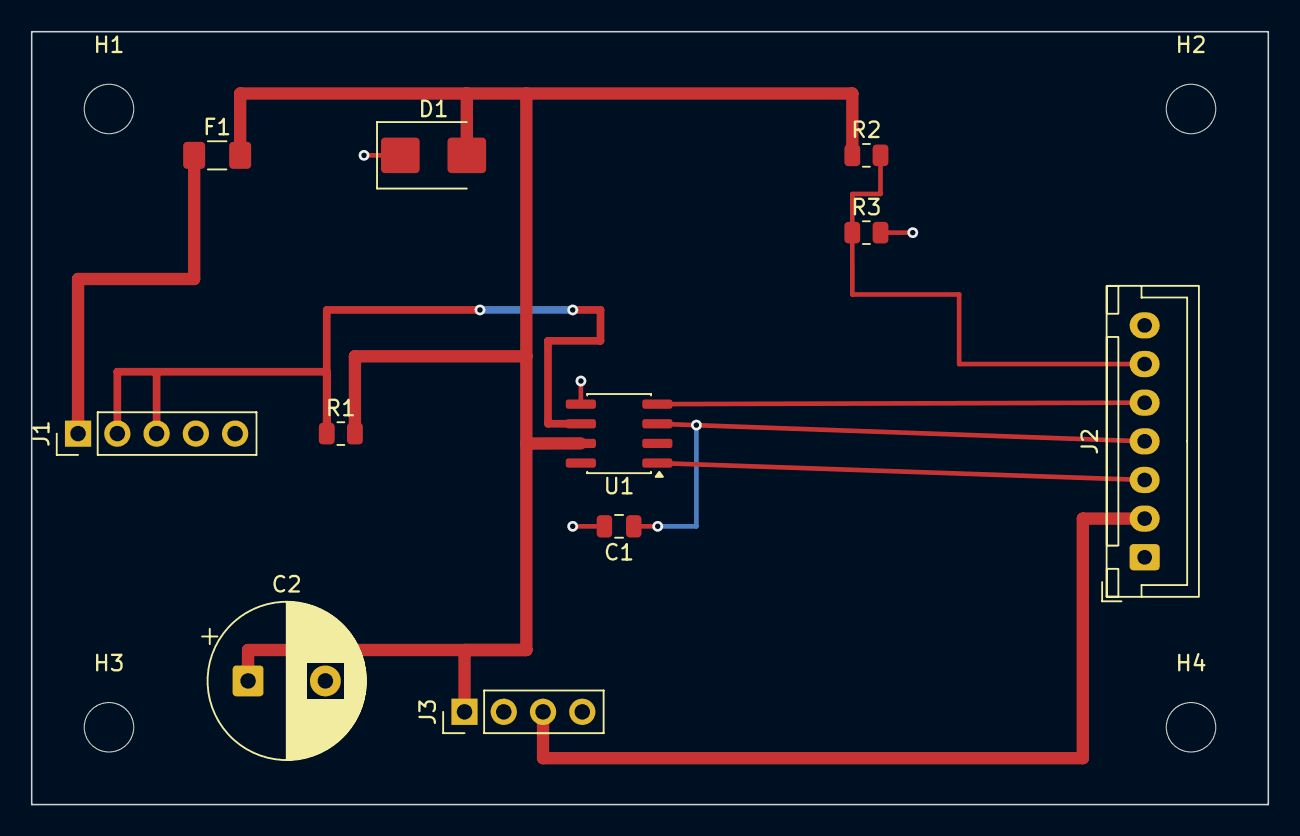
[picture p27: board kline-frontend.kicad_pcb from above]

Board: 2 copper layers, 80.0 x 50.0 mm, 15 parts (0 on the bottom side), 9 nets.

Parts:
C1: 100n; C_0805_2012Metric
C2: 470u/50V; CP_Radial_D10.0mm_P5.00mm
D1: SMBJ26A; D_SMB
F1: 1A; Fuse_1206_3216Metric_Pad1.42x1.75mm_HandSolder
H1, H2, H3, H4: M3; MountingHole_3.2mm_M3
J1: OBD2-5; PinHeader_1x05_P2.54mm_Vertical
J2: MCU-7; JST_XH_B7B-XH-A_1x07_P2.50mm_Vertical
J3: BUCK; PinHeader_1x04_P2.54mm_Vertical
R1: 510R; R_0805_2012Metric
R2: 100k; R_0805_2012Metric
R3: 22k; R_0805_2012Metric
U1: L9637D; SOIC-8_3.9x4.9mm_P1.27mm

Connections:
+3V3: C1.1, J2.4, U1.3
+5V: J2.2, J3.3
GND: C1.2, C2.2, D1.1, J1.4, J1.5, J2.1, J2.7, J3.2, J3.4, R3.2, U1.5
K_LINE: J1.2, J1.3, R1.1, U1.6
K_RX: J2.3, U1.1
K_TX: J2.5, U1.4
VBAT_FUSED: C2.1, D1.2, F1.2, J3.1, R1.2, R2.1, U1.7
VBAT_RAW: F1.1, J1.1
V_SENSE: J2.6, R2.2, R3.1

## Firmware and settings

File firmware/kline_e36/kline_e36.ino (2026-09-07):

// KWP71 sobre ESP32-S3 + L9637D  —  BMW E36 M43B16, Motronic 1.7.2
//
// Puerto de e36obd/kline.py y e36obd/kwp71.py, que ya funcionan contra este
// auto. Lo que cambia respecto de macOS:
//
//   · El init de 5 baudios deja de ser un truco. En macOS habia que hacer
//     bit-bang con TIOCSBRK porque el driver FTDI no deja tocar la linea;
//     aca se escribe el GPIO directo.
//   · Desaparecen los 231 ms por lectura del driver FTDI. El techo real lo
//     pone el handshake de KWP71 y el retardo entre bytes del DME.
//
// El L9637D NO invierte: en la figura 5 de la hoja de datos, TX baja y K baja
// detras. Asi que la logica del GPIO es la del UART, sin inversion.
//
// La linea K es UN hilo, asi que todo lo que transmitimos vuelve por RX. Cada
// escritura se sigue de una lectura que descarta ese eco. Es distinto del
// reconocimiento invertido, que es lo que manda la ECU.
//
// Herramientas > Puerto: el de modo normal (usbmodem largo), no el de descarga.
// Herramientas > USB CDC On Boot: Enabled, para que Serial sea la consola USB.

#include <Arduino.h>

// ------------------------------------------------------------------ pines
static const int PIN_K_TX = 17;   // -> L9637D pin 4 (TX)
static const int PIN_K_RX = 18;   // <- L9637D pin 1 (RX)

// --------------------------------------------------------------- protocolo
static const uint32_t KLINE_BAUD   = 9600;
static const uint8_t  ECU_ADDRESS  = 0x10;   // DME. La caja es 0x6C a 4800.
static const int      KEYWORD_COUNT = 3;     // el DME responde 55 00 81

// BMW espera 2600 ms de bus en reposo antes de cada init. Con 260 ms el
// barrido de direcciones daba falsos negativos: es un error que ya cometimos.
static const uint32_t BUS_IDLE_MS    = 2600;
static const uint32_t BIT_MS         = 200;  // 5 baudios = 200 ms por bit
static const uint32_t INTER_BYTE_MS  = 5;
static const uint32_t BYTE_TIMEOUT_MS = 1200;

// Titulos de bloque KWP71
enum : uint8_t {
  BLK_READ_RAM        = 0x01,
  BLK_DISCONNECT      = 0x06,
  BLK_READ_FAULTS     = 0x07,
  BLK_READ_ADC        = 0x08,
  BLK_EMPTY           = 0x09,
  BLK_NACK            = 0x0A,
  BLK_NOT_SUPPORTED   = 0x0B,
  BLK_END             = 0x03,
};

static uint8_t g_seq = 0;

// =========================================================== transporte
static void klineIdle() {
  // Fuera de sesion la linea descansa alta (recesiva).
  pinMode(PIN_K_TX, OUTPUT);
  digitalWrite(PIN_K_TX, HIGH);
}

static bool readByteRaw(uint8_t *out, uint32_t timeoutMs) {
  uint32_t t0 = millis();
  while (millis() - t0 < timeoutMs) {
    if (Serial1.available()) { *out = (uint8_t)Serial1.read(); return true; }
    delay(1);
  }
  return false;
}

// Escribe un byte y se come su propio eco. La linea K es un hilo: lo que
// transmitimos siempre vuelve.
static bool writeByteSwallowEcho(uint8_t b) {
  while (Serial1.available()) Serial1.read();      // limpiar antes
  Serial1.write(b);
  Serial1.flush();
  uint8_t echo;
  if (!readByteRaw(&echo, 300)) return false;      // sin eco: algo anda mal
  return echo == b;
}

// ====================================================== init de 5 baudios
static bool slowInit(uint8_t address, uint8_t *keywords, int nKeywords) {
  Serial.printf("bus en reposo %lu ms...\n", (unsigned long)BUS_IDLE_MS);
  klineIdle();
  delay(BUS_IDLE_MS);

  Serial.printf("init de 5 baudios, direccion 0x%02X\n", address);

  // bit de arranque
  digitalWrite(PIN_K_TX, LOW);
  delay(BIT_MS);
  // ocho bits de datos, LSB primero
  for (int i = 0; i < 8; i++) {
    digitalWrite(PIN_K_TX, (address >> i) & 1 ? HIGH : LOW);
    delay(BIT_MS);
  }
  // El bit de parada NO se duerme: es la linea descansando alta. Si esperamos
  // los 200 ms completos antes de escuchar, tiramos a la basura el 0x55 de la
  // ECU, que puede llegar a los ~60 ms. Este bug ya nos costo una sesion.
  digitalWrite(PIN_K_TX, HIGH);

  // pasar el pin al UART y escuchar
  Serial1.begin(KLINE_BAUD, SERIAL_8N1, PIN_K_RX, PIN_K_TX);
  while (Serial1.available()) Serial1.read();

  uint8_t b;
  if (!readByteRaw(&b, 500)) {
    Serial.println("  sin respuesta al init");
    return false;
  }
  if (b != 0x55) {
    Serial.printf("  se esperaba 0x55 y llego 0x%02X\n", b);
    // 0x66 significa que la ECU habla a la MITAD de nuestra velocidad:
    // un 0x55 a 4800 muestreado a 9600 se lee 0x66. Asi encontramos la caja.
    if (b == 0x66) Serial.println("  0x66 = esta a 4800, no a 9600");
    return false;
  }
  Serial.println("  0x55 sincronismo OK");

  for (int i = 0; i < nKeywords; i++) {
    if (!readByteRaw(&keywords[i], 500)) {
      Serial.printf("  falto la keyword %d\n", i);
      return false;
    }
  }
  Serial.print("  keywords:");
  for (int i = 0; i < nKeywords; i++) Serial.printf(" %02X", keywords[i]);
  Serial.println();

  // La ultima keyword se reconoce invertida y ahi arranca la sesion.
  delay(INTER_BYTE_MS * 5);
  Serial1.write((uint8_t)(~keywords[nKeywords - 1]));
  Serial1.flush();
  uint8_t echo;
  readByteRaw(&echo, 300);
  return true;
}

// ============================================================== bloques
static bool sendBlock(uint8_t title, const uint8_t *payload, uint8_t n) {
  g_seq = (uint8_t)(g_seq + 1);
  uint8_t len = (uint8_t)(1 + 1 + n + 1);      // seq + title + payload + fin
  uint8_t buf[64];
  uint8_t k = 0;
  buf[k++] = len;
  buf[k++] = g_seq;
  buf[k++] = title;
  for (uint8_t i = 0; i < n; i++) buf[k++] = payload[i];
  buf[k++] = BLK_END;

  for (uint8_t i = 0; i < k; i++) {
    if (!writeByteSwallowEcho(buf[i])) {
      Serial.printf("  se perdio el eco en el byte %u\n", i);
      return false;
    }
    // Todos menos el ultimo los reconoce la ECU, invertidos.
    if (i < len) {
      uint8_t ack;
      if (!readByteRaw(&ack, BYTE_TIMEOUT_MS)) {
        Serial.printf("  sin reconocimiento del byte %u\n", i);
        return false;
      }
      if (ack != (uint8_t)(~buf[i])) {
        Serial.printf("  reconocimiento malo en %u: esperaba %02X, llego %02X\n",
                      i, (uint8_t)(~buf[i]), ack);
        return false;
      }
    }
    delay(INTER_BYTE_MS);
  }
  return true;
}

static bool recvBlock(uint8_t *title, uint8_t *payload, uint8_t *nOut) {
  uint8_t len;
  if (!readByteRaw(&len, BYTE_TIMEOUT_MS)) return false;
  if (len < 3) { Serial.printf("  bloque corto: len=%u\n", len); return false; }

  delay(INTER_BYTE_MS);
  writeByteSwallowEcho((uint8_t)(~len));

  uint8_t raw[64];
  raw[0] = len;
  for (uint8_t i = 1; i <= len; i++) {
    if (!readByteRaw(&raw[i], BYTE_TIMEOUT_MS)) return false;
    if (i < len) {
      delay(INTER_BYTE_MS);
      writeByteSwallowEcho((uint8_t)(~raw[i]));
    }
  }
  g_seq   = raw[1];
  *title  = raw[2];
  *nOut   = (uint8_t)(len - 3);
  for (uint8_t i = 0; i < *nOut; i++) payload[i] = raw[3 + i];
  return true;
}

// ============================================================== fallas
// Cada falla son 5 bytes: [codigo][condicion][rpm][byte3][frecuencia].
// Las escalas del freeze frame no estan cerradas; el codigo si.
static void printFaults(const uint8_t *p, uint8_t n) {
  if (n == 0) { Serial.println("  sin fallas almacenadas"); return; }
  for (uint8_t i = 0; i + 4 < n; i += 5) {
    Serial.printf("  codigo %3u  cond 0x%02X  ocurrencias %u  crudo %02X %02X\n",
                  p[i], p[i + 1], p[i + 4], p[i + 2], p[i + 3]);
    if (p[i] == 100) Serial.println("      -> Amplifier/output stage 1 in DME");
    if (p[i] == 36)  Serial.println("      -> EVAP / valvula del canister");
  }
}

// ================================================================ arranque
void setup() {
  Serial.begin(115200);
  uint32_t t0 = millis();
  while (!Serial && millis() - t0 < 4000) delay(50);
  delay(500);

  Serial.println();
  Serial.println("=== KWP71 / E36 M43B16 ===");
  Serial.printf("TX=GPIO%d  RX=GPIO%d  %lu baudios  direccion 0x%02X\n",
                PIN_K_TX, PIN_K_RX, (unsigned long)KLINE_BAUD, ECU_ADDRESS);
  Serial.println("Contacto en posicion 2. El motor puede estar apagado.");
  Serial.println();

  uint8_t kw[KEYWORD_COUNT] = {0};
  if (!slowInit(ECU_ADDRESS, kw, KEYWORD_COUNT)) {
    Serial.println("\nINIT FALLIDO. Revisar, en orden:");
    Serial.println("  1. llave en posicion 2, no en 1");
    Serial.println("  2. OBD2 pin 7 Y pin 15 juntos al pin 6 del L9637D");
    Serial.println("  3. pin 3 del L9637D en 3,3 V");
    Serial.println("  4. pin 6 en reposo cerca de 12 V");
    return;
  }
  Serial.println("\nSESION ABIERTA\n");

  // La ECU manda sus cadenas de identificacion sin que se las pidan.
  uint8_t title, payload[64], n;
  for (int i = 0; i < 8; i++) {
    if (!recvBlock(&title, payload, &n)) break;
    if (title == BLK_EMPTY) break;
    Serial.printf("bloque 0x%02X (%u bytes): ", title, n);
    for (uint8_t j = 0; j < n; j++)
      Serial.print((payload[j] >= 32 && payload[j] < 127) ? (char)payload[j] : '.');
    Serial.println();
    delay(INTER_BYTE_MS);
    sendBlock(BLK_EMPTY, nullptr, 0);
  }

  Serial.println("\n--- memoria de fallas ---");
  if (sendBlock(BLK_READ_FAULTS, nullptr, 0)) {
    while (recvBlock(&title, payload, &n)) {
      if (title == BLK_EMPTY) break;
      printFaults(payload, n);
      delay(INTER_BYTE_MS);
      sendBlock(BLK_EMPTY, nullptr, 0);
    }
  }

  Serial.println("\nSe esperan los codigos 100 y 36, los dos con contador en 50.");
  Serial.println("Si aparecen, todo el stack funciona.");
  sendBlock(BLK_DISCONNECT, nullptr, 0);
}

void loop() {
  delay(1000);
}

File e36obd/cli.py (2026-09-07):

"""Command line interface for talking to an E36 Motronic ECU over K-line."""

from __future__ import annotations

import argparse
import csv
import logging
import sys
import time
from datetime import datetime, timezone

import serial
from serial.tools import list_ports

from .ds2 import COMMON_ADDRESSES as COMMON_DS2_ADDRESSES
from .ds2 import DS2, DS2Error
from .egs import EGS_ADDRESS, EGS_BAUD
from .egs import decode as decode_egs
from .faults import decode as decode_faults
from .kline import InitError, KLine, KLineError
from .live import LiveReader
from .snapshot import Snapshot
from .snapshot import diff as diff_snapshots
from .web import serve
from .kwp71 import BlockType, KWP71Session, NotSupportedError

log = logging.getLogger("e36obd")

# FTDI's USB vendor ID. K+DCAN cables use the FT232R (product 0x6001).
FTDI_VID = 0x0403

# 0x10 wakes DME #1 and 0x14 wakes DME #2 on BMW Motronic units; the same 0x10
# appears for Alfa, Fiat and Volvo Motronics. The rest are longer shots.
#
# Note: 0x12 is deliberately NOT first. It is the DS2 engine-ECU address -- a
# different protocol entirely -- and appears in no KWP71 implementation.
DEFAULT_SCAN_ADDRESSES = [0x10, 0x14, 0x11, 0x01, 0x13, 0x33, 0x00, 0x12, 0x17]


# --------------------------------------------------------------------- helpers


def hexs(data: bytes | list[int]) -> str:
    return " ".join(f"{b:02X}" for b in data)


def find_default_port() -> str | None:
    """Pick the most likely K-line cable from the attached serial devices."""
    candidates = [p for p in list_ports.comports() if p.vid == FTDI_VID]
    if not candidates:
        candidates = [p for p in list_ports.comports() if "usbserial" in p.device]
    if not candidates:
        return None
    # Prefer the callout device (/dev/cu.*) on macOS: /dev/tty.* blocks on open
    # waiting for carrier detect, which never asserts on a K-line cable.
    for port in candidates:
        if "/cu." in port.device:
            return port.device
    return candidates[0].device


def open_line(args: argparse.Namespace) -> KLine:
    port = args.port or find_default_port()
    if port is None:
        raise SystemExit(
            "No serial port found. Plug in the K+DCAN cable, or pass --port explicitly."
        )
    loopback = None
    if args.loopback == "on":
        loopback = True
    elif args.loopback == "off":
        loopback = False
    return KLine(port=port, baud=args.baud, timeout=args.timeout, loopback=loopback)


def connect_session(args: argparse.Namespace, line: KLine) -> KWP71Session:
    session = KWP71Session(line)
    keywords = session.connect(address=args.address, keyword_count=args.keyword_bytes)
    print(f"Connected. Keyword bytes: {hexs(keywords)}")
    if session.id_strings:
        print("ECU identification:")
        for raw in session.id_strings:
            text = raw.decode("ascii", errors="replace").strip()
            print(f"  {text!r:40} raw: {hexs(raw)}")
    return session


# -------------------------------------------------------------------- commands


def cmd_doctor(args: argparse.Namespace) -> int:
    """Check the cable and port with no car attached."""
    print("=== Serial ports ===")
    ports = list(list_ports.comports())
    if not ports:
        print("  none found")
    for port in ports:
        vid = f"{port.vid:04X}" if port.vid is not None else "----"
        pid = f"{port.pid:04X}" if port.pid is not None else "----"
        marker = "  <-- FTDI" if port.vid == FTDI_VID else ""
        print(f"  {port.device:32} VID:PID={vid}:{pid}  {port.description}{marker}")

    chosen = args.port or find_default_port()
    if chosen is None:
        print("\nNo candidate cable found. Is the K+DCAN plugged into USB?")
        return 1

    print(f"\n=== Opening {chosen} ===")
    try:
        line = KLine(port=chosen, baud=args.baud, timeout=args.timeout)
    except serial.SerialException as exc:
        print(f"  FAILED to open: {exc}")
        return 1

    with line:
        print("  opened OK")
        try:
            line._ser.break_condition = True
            time.sleep(0.05)
            line._ser.break_condition = False
            print("  BREAK control works (needed for the 5-baud init)")
        except (OSError, serial.SerialException) as exc:
            print(f"  BREAK control FAILED: {exc}")
            print("  Without BREAK we cannot perform the slow init on macOS.")
            return 1

        print("\n=== Loopback probe ===")
        # The K-line transceiver inside the cable is powered from OBD2 pin 16,
        # i.e. from the car's battery -- not from USB. So an unplugged cable
        # cannot echo. Once plugged into the car, an echo here proves the
        # adapter is passing +12V and ground through, which is the single most
        # common failure with cheap K-line-only 20-pin adapters.
        line.flush()
        echoes = 0
        for probe in (0x55, 0xAA, 0xF7):
            line._ser.write(bytes([probe]))
            line._ser.flush()
            reply = line.try_read_byte(timeout=0.4)
            got = f"{reply:02X}" if reply is not None else "silence"
            print(f"  sent {probe:02X} -> {got}")
            if reply == probe:
                echoes += 1

        if echoes:
            print("  Cable is echoing: the transceiver is powered.")
        else:
            print("  No echo.")
            print("  * Unplugged from the car: normal, nothing is wrong.")
            print("  * Plugged into the car with ignition on: the cable is NOT")
            print("    getting +12V. Suspect the 20-pin adapter (K-line-only,")
            print("    no power pass-through) or pin 16 on the round connector.")

        print("\n=== Listening for 2s of unsolicited traffic ===")
        line.flush()
        seen = []
        deadline = time.monotonic() + 2.0
        while time.monotonic() < deadline:
            byte = line.try_read_byte(timeout=0.1)
            if byte is not None:
                seen.append(byte)
        if seen:
            print(f"  {len(seen)} bytes: {hexs(seen[:32])}")
            print("  (Traffic with no request sent usually means the K-line is active.)")
        else:
            print("  silent -- expected. The ECU only speaks when spoken to.")

    print("\nCable looks usable. Next: connect to the car and run `scan`.")
    return 0
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

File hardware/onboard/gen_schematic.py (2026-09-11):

"""Esquema SVG + netlist KiCad, generados desde las MISMAS redes que la placa (gen_board.N).

  python3 hardware/onboard/gen_schematic.py

El dibujo se verifica contra N: cada (ref, pin) de cada red tiene que aparecer en el dibujo
exactamente en esa red (por cable o por etiqueta). Si no coincide, no se emite el SVG.
"""
import os, re, sys
HERE = os.path.dirname(os.path.abspath(__file__))
src = open(os.path.join(HERE, "gen_board.py")).read()
# leer P y N sin importar pcbnew
ns = {}
exec(re.search(r"^P = \[.*?^\]", src, re.S | re.M).group(0), ns)
exec(re.search(r"^N = \{.*?^\}", src, re.S | re.M).group(0), ns)
P, N = ns["P"], ns["N"]
VAL = {p[0]: p[6] for p in P}

COL = {"VBAT_RAW": "#c0392b", "VBAT_F": "#c0392b", "VIN": "#c0392b", "+3V3": "#c0392b", "VBUS": "#c0392b",
       "SW": "#8e44ad", "BST": "#8e44ad", "K_LINE": "#c2701a", "GND": "#555555"}
def col(net): return COL.get(net, "#2166a8")

svg, pins, used = [], {}, {}      # used[net] = set de "ref.pin" dibujados

def T(x, y, s, size=11, anchor="start", color="#222", weight=400):
    svg.append('<text x="%g" y="%g" font-size="%g" text-anchor="%s" fill="%s" font-weight="%d">%s</text>'
               % (x, y, size, anchor, color, weight, s.replace("&", "&amp;").replace("<", "&lt;")))
def L(x0, y0, x1, y1, color="#222", w=1.6):
    svg.append('<line x1="%g" y1="%g" x2="%g" y2="%g" stroke="%s" stroke-width="%g"/>' % (x0, y0, x1, y1, color, w))

def box(ref, x, y, w, h, sub, plist):
    """Caja con pines: plist = [(pin, lado L/R, offset, etiqueta)]. Guarda el extremo del stub."""
    svg.append('<rect x="%g" y="%g" width="%g" height="%g" rx="3" fill="#fff" stroke="#222" stroke-width="1.8"/>' % (x, y, w, h))
    T(x + w / 2, y + 16, ref, 13, "middle", weight=600); T(x + w / 2, y + 30, sub, 10, "middle", "#666")
    for pid, side, off, lab in plist:
        if side == "L":
            L(x - 22, y + off, x, y + off); pins[(ref, pid)] = (x - 22, y + off); T(x + 5, y + off + 4, lab, 10)
        else:
            L(x + w, y + off, x + w + 22, y + off); pins[(ref, pid)] = (x + w + 22, y + off); T(x + w - 5, y + off + 4, lab, 10, "end")

def part2(ref, kind, x, y, orient):
    """Dos terminales centrado en (x,y). H: pin1 izq, pin2 der. V: pin1 arriba, pin2 abajo."""
    d = 30
    if orient == "H":    p1, p2 = (x - d, y), (x + d, y)
    elif orient == "Vr": p1, p2 = (x, y + d), (x, y - d)      # pin 2 arriba
    else:                p1, p2 = (x, y - d), (x, y + d)
    pins[(ref, "1")], pins[(ref, "2")] = p1, p2
    g = 'transform="translate(%g %g) rotate(%d)"' % (x, y, 0 if orient == "H" else 90)
    body = {"R": '<rect x="-16" y="-6" width="32" height="12" fill="#fff" stroke="#222" stroke-width="1.6"/>',
            "C": '<line x1="-3" y1="-9" x2="-3" y2="9" stroke="#222" stroke-width="2.2"/><line x1="3" y1="-9" x2="3" y2="9" stroke="#222" stroke-width="2.2"/>',
            "D": '<polygon points="8,-8 8,8 -8,0" fill="#fff" stroke="#222" stroke-width="1.6"/><line x1="-8" y1="-8" x2="-8" y2="8" stroke="#222" stroke-width="2.4"/>',
            "Z": '<polygon points="8,-8 8,8 -8,0" fill="#fff" stroke="#222" stroke-width="1.6"/><polyline points="-11,-8 -8,-8 -8,8 -5,8" fill="none" stroke="#222" stroke-width="2.4"/>',
            "LED": '<polygon points="8,-8 8,8 -8,0" fill="#fff" stroke="#222" stroke-width="1.6"/><line x1="-8" y1="-8" x2="-8" y2="8" stroke="#222" stroke-width="2.4"/><line x1="0" y1="-10" x2="6" y2="-16" stroke="#222" stroke-width="1.4"/><line x1="-4" y1="-10" x2="2" y2="-16" stroke="#222" stroke-width="1.4"/>',
            "L": '<path d="M-16,0 a4,4 0 0,1 8,0 a4,4 0 0,1 8,0 a4,4 0 0,1 8,0 a4,4 0 0,1 8,0" fill="none" stroke="#222" stroke-width="1.8"/>',
            "F": '<rect x="-14" y="-5" width="28" height="10" fill="#fff" stroke="#222" stroke-width="1.6"/><line x1="-14" y1="0" x2="14" y2="0" stroke="#222" stroke-width="1.4"/>',
            "SW": '<line x1="-14" y1="0" x2="-6" y2="0" stroke="#222" stroke-width="1.8"/><line x1="6" y1="0" x2="14" y2="0" stroke="#222" stroke-width="1.8"/><line x1="-6" y1="2" x2="8" y2="-8" stroke="#222" stroke-width="1.8"/>'}[kind]
    stub = 14 if kind in ("R", "F") else 8 if kind in ("C",) else 14
    svg.append('<g %s>%s<line x1="-30" y1="0" x2="%g" y2="0" stroke="#222" stroke-width="1.6"/><line x1="%g" y1="0" x2="30" y2="0" stroke="#222" stroke-width="1.6"/></g>'
               % (g, body, -stub, stub))
    lx, ly = (x, y - 12) if orient == "H" else (x + 14, y - 2)
    T(lx, ly, ref, 10, "middle" if orient == "H" else "start", weight=600)
    T(lx, ly + 11 if orient == "H" else ly + 11, VAL[ref].split(" ")[0], 9.5, "middle" if orient == "H" else "start", "#666")
    # el pin 1 (catodo en D/LED/Z) queda marcado con la barra: en H a la izquierda, en V arriba

def wire(net, path):
    """path: lista de "ref.pin" o (x,y). Se dibuja en orden, y todos los pines quedan en la red."""
    pts = []
    for p in path:
        if isinstance(p, str):
            ref, pid = p.split("."); pts.append(pins[(ref, pid)]); used.setdefault(net, set()).add(p)
        else: pts.append(p)
    svg.append('<polyline points="%s" fill="none" stroke="%s" stroke-width="2" stroke-linejoin="round"/>'
               % (" ".join("%g,%g" % q for q in pts), col(net)))
    for q in pts:
        if sum(1 for r in pts if r == q) > 1 or any(q == pins.get(k) for k in ()):
            pass
    return pts

def dot(x, y, net): svg.append('<circle cx="%g" cy="%g" r="3.4" fill="%s"/>' % (x, y, col(net)))

def label(net, pin, dx=0, dy=0, side="R"):
    """Etiqueta de red en el extremo de un pin (o desplazada)."""
    ref, pid = pin.split("."); x, y = pins[(ref, pid)]
    used.setdefault(net, set()).add(pin)
    if dx or dy: L(x, y, x + dx, y + dy, col(net), 2); x, y = x + dx, y + dy
    if net == "GND":
        L(x, y, x, y + 10, col(net), 2); L(x - 9, y + 10, x + 9, y + 10, "#555", 2.2)
        L(x - 6, y + 14, x + 6, y + 14, "#555", 2); L(x - 3, y + 18, x + 3, y + 18, "#555", 2); return
    if side == "R": T(x + 5, y + 4, net, 10, "start", col(net), 600)
    elif side == "L": T(x - 5, y + 4, net, 10, "end", col(net), 600)
    elif side == "T": T(x, y - 5, net, 10, "middle", col(net), 600)
    else: T(x, y + 14, net, 10, "middle", col(net), 600)
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

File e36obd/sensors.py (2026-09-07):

"""Live sensor map for BMW DME M1.7.2 (E36 M43B16).

Addresses and scalings originate from a captured INPA session against a
Motronic 1.7 and were verified against this M43B16 1.7.2 at idle: battery
13.69 V while charging, intake air 17.2 C, coolant 37.1 C warming, 940 rpm.
Four mutually consistent physical readings is good evidence the map holds.

Important: the DME does not populate these locations until the engine is
actually running. With ignition on and the engine off they all read 0x00,
which looks like a dead link but is not.
"""

from __future__ import annotations

from dataclasses import dataclass
from typing import Callable


@dataclass(frozen=True)
class Sensor:
    address: int
    name: str
    unit: str
    scale: Callable[[int], float]
    fmt: str = "{:.1f}"

    def render(self, raw: int) -> str:
        return self.fmt.format(self.scale(raw))


# Core block: contiguous from 0x0036 to 0x0040, readable in a single command.
# Keeping it to one read matters -- every extra round trip is another chance
# for ignition noise to corrupt the byte handshake.
CORE_START = 0x0036
CORE_LENGTH = 0x0B  # 0x0036..0x0040 inclusive

CORE_SENSORS: list[Sensor] = [
    Sensor(0x0036, "battery", "V", lambda b: 0.0681 * b, "{:.2f}"),
    Sensor(0x0037, "intake_air_temp", "C", lambda b: -33.5 + 0.65 * b),
    Sensor(0x0038, "coolant_temp", "C", lambda b: -32.5 + 0.65 * b),
    Sensor(0x003C, "rpm", "rpm", lambda b: 10.0 * b, "{:.0f}"),
    Sensor(0x0040, "load", "ms", lambda b: 0.05 * b, "{:.2f}"),
]

# Velocidad de camino. Documentada en 0x008B, pero NUNCA validada -- con el
# motor apagado leía 0x00 como todo lo demás. Vive fuera del bloque contiguo,
# así que leerla cuesta un round trip extra y baja la tasa de muestreo, por eso
# es opcional.
#
# OJO: puede estar DENTRO del bloque de 11 bytes. Seis bytes de ese bloque
# (0x39 0x3A 0x3B 0x3D 0x3E 0x3F) siguen sin identificar y viajan gratis en cada
# lectura. Antes de pagar un round trip, conviene buscarla ahí con el explorador.
ROAD_SPEED_ADDR = 0x008B
ROAD_SPEED_SCALE = 1.102          # km/h por cuenta (sin validar)

# Tren final, para pasar de velocidad de camino a vueltas del eje de salida.
# La relación de marcha es régimen / vueltas_de_salida, no régimen / km/h.
FINAL_DRIVE = 4.44                # E36 318i automático, típico
TYRE_CIRCUM_M = 1.87              # 205/60 R15

def output_shaft_rpm(speed_kmh: float, final_drive: float = FINAL_DRIVE,
                     circum_m: float = TYRE_CIRCUM_M) -> float:
    """Vueltas del eje de salida a partir de la velocidad de camino.

    Hay que calibrarlo: en 3ª la relación mecánica es exactamente 1.000, así que
    si andando en tercera esto no da ~1.00, el tren final o la circunferencia
    están mal y se corrigen desde ahí.
    """
    if speed_kmh <= 0 or circum_m <= 0:
        return 0.0
    return speed_kmh * 1000.0 / 60.0 / circum_m * final_drive


# Outside the core block, so each costs an extra round trip.
EXTRA_SENSORS: list[Sensor] = [
    Sensor(0x0055, "ignition_angle", "deg", lambda b: 0.75 * (96 - b)),
    Sensor(0x008B, "road_speed", "km/h", lambda b: 1.102 * b),
    Sensor(0x009D, "air_consumption", "kg/h", lambda b: 0.2 * b),
    Sensor(0x0211, "lambda_integrator", "", lambda b: float(b - 128), "{:.0f}"),
]

ALL_SENSORS = CORE_SENSORS + EXTRA_SENSORS


def core_offset(sensor: Sensor) -> int:
    """Index of a core sensor's byte within a CORE_LENGTH read from CORE_START."""
    return sensor.address - CORE_START

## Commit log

2026-09-08 Add iOS app, ELM backpack hardware, firmware tests
    - ios/: SwiftPM E36Core package (acquisition, alerts, wire protocol,
    session store, widget snapshots) plus the E36OBD app, widgets, tests,
    and project-generation tooling
    - hardware/elm-backpack/: parametric CAD model, render/packaging scripts,
    rev B–E exports (STEP/STL/3MF/PNG), and viewer
    - firmware/tests/: BLE unit tests; minor ble.py fixes
    - README updates for the LAN dashboard token flow
    - Untrack .DS_Store and add root .gitignore
    [assembly-with-references.step, base.step, base.stl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]
2026-09-11 Add iOS vehicle scene + K-line work; store large assets in Git LFS
    - ios/: RealityKit vehicle scene (VehicleScene/, VehicleSceneView, custom
    VehiclePaint metal), Design/Vehicle source (.blend/.glb/.usdz/.exr),
    export/render/bake tooling, overview & turntable views, updated dashboard
    - firmware/: K-line driver (kline.py) + tests, BLE updates
    - Git LFS for large binary assets (usdz, blend, glb, exr, realityenv, step,
    stl, 3mf, zip, pdf, jsonl, media) via .gitattributes
    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
    [E36-316i.blend, FogIntake.step, ReferenceLighting.blend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]
2026-09-11 Update vehicle .blend sources and geometry/paint audits
    [E36-316i.blend, ReferenceLighting.blend]
2026-09-11 feat(ios): refine E36 asset and Metal lighting
    Add the app-only lowered stance, refined badges, HDR display transform, aligned environment lighting, and live material shading. Include native scene assets, render previews, regeneration tools, and 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
    [AppLighting.blend, E36-316i.blend, ReferenceLighting.blend]
2026-09-11 hardware: single-board E36 K-line reader (ESP32-S3 + L9637D + AP63203 + OBD2) with printed case
    Rev B board, 90x50 mm, 2 layers: WROOM-1-N16R8 module with antenna keep-out,
    L9637D K-line front end, AP63203 12V->3.3V buck with hardware UVLO
    (on 12.5 V / off 11.5 V, USB overrides), OBD2 male plug footprint built from
    the Macchina CCBDM20 STEP, J4 pigtail for the 20-pin round connector, USB-C
    native. Generated by gen_board.py (pcbnew) + Freerouting; DRC 0 errors,
    0 unconnected. Schematic and netlist verified against the same net table.
    JLCPCB gerbers/BOM/CPL in fab/. Two-part build123d case (M50 =BMW= lid,
    USB-C captured in the wall, pigtail variant) with Blender renders.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
    [assembly-pigtail.step, assembly.step, base-pigtail.step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]
2026-09-11 hardware: onboard case restyle, M50 badge, USB-C capture, pigtail variant
    - Case: R6 corners, 45-degree chamfers, seam shadow line, brass M3 heat-set
    inserts (M3x12 from below), O3 light pipes for the LEDs, clip holes for
    RESET/BOOT, OBD2 plug modelled with its D profile.
    - Badge as a separate part: 85x22 black field, 13 silver ribs at 1.6 mm pitch
    running the lid, BMW plaque off-centre cutting only the middle ribs
    (filament change at 1.6 mm), copied from the M50 valve cover.
    - USB-C receptacle protrudes 1.6 mm and passes through a shell-shaped opening
    flush with a bezel; board grown to 90x50, shelf under the board edge.
    - J4 JST-XH pigtail (GND/K/+12) to go direct to the 20-pin ro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
    [assembly-pigtail.step, assembly.step, badge.stl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]
2026-09-12 hardware: verified LCSC codes, JLCPCB/PCBWay pricing, PCBWay sample package; archive session
    - BOM: three wrong LCSC codes found while pricing and fixed (L9637D -> C153038
    E-L9637D013TR, 3.74k -> C23016, LEDs -> basic 0603 KT-0603W/R), plus verified
    codes for TVS, 2010 pull-up, 50 V input caps, 36k; gerbers/BOM/CPL regenerated
    (DRC 0 errors, 0 unconnected). BOOT button and status LED relocated to clear the
    badge band; badge now 13 ribs with continuous outer ribs past the BMW plaque.
    - pricing.py: JLCPCB estimate from their parts API + published fees
    (~97 USD / 5 boards, ~140 / 10). pcbway.py: PCBWay one-sample package (BOM in
    their format with MPNs, centroids, drawing, order note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
    [bom-jlcpcb.csv, bom-pcbway.csv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]
2026-09-12 chore(workspace): save current work and session context
    [AppLighting.blend, E36-316i.blend, ReferenceLighting.blend]
2026-09-12 feat(ios): complete vehicle experience and Apple companions
    Add the Watch app, complications, Live Activities and Garage/OBC widget
    variations. Refine the native E36 asset, studio lighting, optics and
    roundel icon; keep a single edge-to-edge scene across the four tabs
    with ordered camera rotations and free navigation when expanded.
    Repair the Garage widget shadow export with transparent edges. Preserve
    session context in a continuation handoff and visible conversation archive.
    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
2026-09-12 sessions: raw transcripts — refreshed Claude sessions, sub-agent transcripts, task outputs, memory snapshot
2026-09-12 docs(sessions): archive raw enclosure conversation records
2026-09-29 docs(ios): record signed device delivery on main
